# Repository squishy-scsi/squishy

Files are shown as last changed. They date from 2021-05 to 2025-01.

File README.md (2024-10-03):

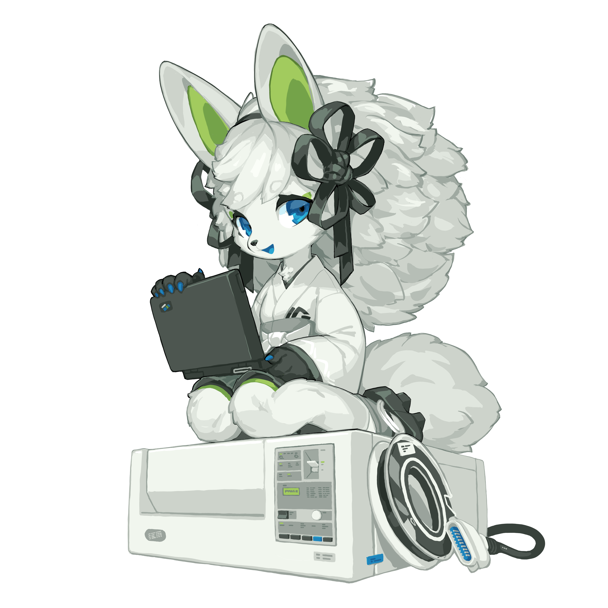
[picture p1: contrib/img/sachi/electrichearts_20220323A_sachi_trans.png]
[](https://docs.scsi.moe/mascot.html)
# Squishy: The SCSI Multitool

Squishy is a platform for working with old SCSI devices with modern systems in a flexible manner. It was originally developed as a one-off solution for the [taperipper](https://lethalbit.net/projects/taperipper/) project, which was to boot a modern system off of a IBM 9348-002 9-track magnetic tape drive.

It has since evolved into being a generic toolkit and hardware platform for all things SCSI.

Squishy is comprised of 4 core components; A gateware library built on [Torii](https://github.com/shrine-maiden-heavy-industries/torii-hdl); A python library with various utilities and structures for dealing with SCSI data; A applet system to allow for custom gateware/python code applets to run on the hardware; And finally, the hardware itself.

> [!IMPORTANT]
> If you're looking for the Squishy hardware, the design files have moved to [`squishy-scsi/hardware`](https://github.com/squishy-scsi/hardware).

## Documentation

The documentation for Squishy can be found at [https://docs.scsi.moe](https://docs.scsi.moe).

## Installation

The installation instructions for squishy on various platforms can be found on the [https://docs.scsi.moe/install.html](https://docs.scsi.moe/install.html) page.

## Hardware

The Squishy hardware design files have be migrated to [`squishy-scsi/hardware`](https://github.com/squishy-scsi/hardware).

Details about the squishy hardware can be found on the [https://docs.scsi.moe/hardware/index.html](https://docs.scsi.moe/hardware/index.html) page.

## Mascot - Sachi

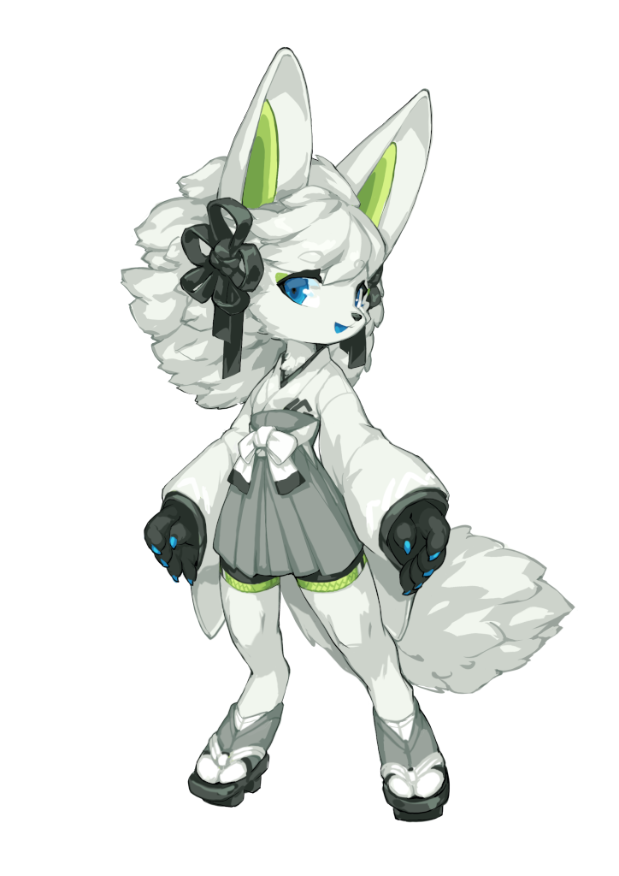
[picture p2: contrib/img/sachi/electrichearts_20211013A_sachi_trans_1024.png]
Sachi the spirit fox


More information about Sachi is available on her [mascot page](https://docs.scsi.moe/mascot.html) in the documentation.

Sachi was designed and illustrated by the amazing [Tyson Tan (tysontan.com)](https://tysontan.com). He provides mascot design service for free and open source software projects, free of charge, under free license.

## Community

Squishy has a dedicated IRC channel, [#squishy on libera.chat](https://web.libera.chat/#squishy). Join to ask questions, discuss ongoing development, or just hang out.

**NOTE:** Squishy does not have an official discord, nor any endorsed discord servers, for an explanation as to why, see the [F.A.Q.](https://docs.scsi.moe/faq.html)

## Licenses

The Squishy project is licensed under 3 individual licenses, one for the hardware and gateware, one for the software and one for the documentation.

The hardware is licensed under the [CERN-OHL-S](https://ohwr.org/cern_ohl_s_v2.txt), the license for which can be found in [`squishy-scsi/hardware/LICENSE`](https://github.com/squishy-scsi/hardware/tree/main/LICENSE)

The software and gateware are licensed under the [BSD-3-Clause](https://spdx.org/licenses/BSD-3-Clause.html) and can be found in [LICENSE.software](https://github.com/squishy-scsi/squishy/tree/main/LICENSE.software).

The documentation is licensed under the Creative Commons [CC-BY-SA](https://creativecommons.org/licenses/by-sa/4.0/) and can be found in [LICENSE.docs](https://github.com/squishy-scsi/squishy/tree/main/LICENSE.docs)

The icons used in the GUI are from the [KDE](https://kde.org) project. They are the [breeze-icons](https://github.com/KDE/breeze-icons/) and they are licensed under the [LGPL v2.1](https://spdx.org/licenses/LGPL-2.1-only.html), and can be found in [LICENSE.icons](https://github.com/squishy-scsi/squishy/tree/main/LICENSE.icons)

Sachi, the mascot is dual-licensed under the [BSD-3-Clause](https://spdx.org/licenses/BSD-3-Clause.html) and the Creative Commons [CC-BY-SA](https://creativecommons.org/licenses/by-sa/2.0/)

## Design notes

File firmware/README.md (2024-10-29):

# Squishy - Supervisor Firmware

> [!CAUTION]
> This documentation is ***really*** rough and incomplete, it will be
> eventually rolled into the [main documentation](https://docs.scsi.moe),
> but only once it's been stabilized.

This is the firmware that runs on the supervisor MCU on the squishy rev2 board, which is responsible for handling programming the FPGA and ensuring it can always boot into backup bootloader gateware.

## Building

To build the firmware you need a handful of things:

* meson >= 1.4.0
* ninja
* and a GCC `arm-none-eabi` cross compiler toolchain

To build the firmware, create a build directory (we'll call it `$BUILD`) and then invoke `meson` passing the toolchain file, like so:

```
$ meson setup --cross-file contrib/arm-none-eabi.meson $BUILD firmware
```

With that all done and happy, you can then build the firmware ELF with `ninja -C build`.

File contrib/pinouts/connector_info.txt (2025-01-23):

| PIN CNT | Body Type  | Signaling | Is Shielded | Name    | SCSI Standard        | Table ID | Table Reference | Figure Reference | Connector Reference                  |
|=========|============|===========|=============|=========|======================|==========|=================|==================|======================================|
| 50      | IDC        | SE        | No          | IDC50   | X3.131:1986 (SCSI-1) | MSE-50   | 4-1             | (FIG 4-1/4-2)    |                                      |
| 50      | IDC        | HVD       | No          | IDC50   | X3.131:1986 (SCSI-1) | HVD-50   | 4-2             | (FIG 4-1/4-2)    |                                      |
| 50      | Centronics | SE        | Yes         | CE50    | x3.131:1986 (SCSI-1) | MSE-50   | 4-1             |                  |                                      |
| 50      | Centronics | HVD       | Yes         | CE50    | x3.131:1986 (SCSI-1) | HVD-50   | 4-2             |                  |                                      |
|---------|------------|-----------|-------------|---------|----------------------|----------|-----------------|------------------|--------------------------------------|
| 50      | HD         | SE        | No          | HD50    | SCSI-2 R10L          | MSE-50   | 2:2             | (FIG 1/2 A)      | Non-shielded connector alternative 1 |
| 68      | HD         | SE        | No          | HD68    | SCSI-2 R10L          | SCSI2-68 | 3               | (FIG 1/2 B)      | Non-shielded connector               |
| 50      | HD         | HVD       | No          | HD50    | SCSI-2 R10L          | HVD-50   | 4:2             | (FIG 1/2 A)      | Non-shielded connector alternative 1 |
| 68      | HD         | HVD       | No          | HD68    | SCSI-2 R10L          | SCSI2-68 | 5               | (FIG 1/2 B)      | Non-shielded connector               |
| 50      | IDC        | SE        | No          | IDC50   | SCSI-2 R10L          | MSE-50   | 2:1             | (FIG 3/4 A)      | Non-shielded connector alternative 2 |
| 50      | IDC        | HVD       | No          | IDC50   | SCSI-2 R10L          | HVD-50   | 4:1             | (FIG 3/4 A)      | Non-shielded connector alternative 2 |
| 50      | HD         | SE        | Yes         | HD50    | SCSI-2 R10L          | MSE-50   | 2:2             | (FIG 6/5 A)      | Shielded connector alternative 1     |
| 68      | HD         | SE        | Yes         | HD68    | SCSI-2 R10L          | SCSI2-68 | 3               | (FIG 6/5 B)      | Shielded connector                   |
| 50      | HD         | HVD       | Yes         | HD50    | SCSI-2 R10L          | HVD-50   | 4:2             | (FIG 6/5 A)      | Shielded connector alternative 1     |
| 68      | HD         | HVD       | Yes         | HD68    | SCSI-2 R10L          | SCSI2-68 | 5               | (FIG 6/5 B)      | Shielded connector                   |
| 50      | Centronics | SE        | Yes         | CE50    | SCSI-2 R10L          | MSE-50   | 2:2             | (FIG 7/8 A)      | Shielded connector alternative 2     |
| 50      | Centronics | HVD       | Yes         | CE50    | SCSI-2 R10L          | HVD-50   | 4:2             | (FIG 7/8 A)      | Shielded connector alternative 2     |
|---------|------------|-----------|-------------|---------|----------------------|----------|-----------------|------------------|--------------------------------------|
| 68      | HD         | SE        | No          | HD68    | SPI-1 R15A (SCSI-3)  | MSE-68   | Table 1/2       | (FIG 4/5)        | Nonshielded connector                |
| 68      | HD         | SE        | Yes         | HD68    | SPI-1 R15A (SCSI-3)  | MSE-68   | Table 1/2       | (FIG 6/7)        | Shielded connector                   |
| 68      | HD         | HVD       | No          | HD68    | SPI-1 R15A (SCSI-3)  | HVD-68   | Table 3/4       | (FIG 4/5)        | Nonshielded connector                |
| 68      | HD         | HVD       | Yes         | HD68    | SPI-1 R15A (SCSI-3)  | HVD-68   | Table 3/4       | (FIG 6/7)        | Shielded connector                   |
|---------|------------|-----------|-------------|---------|----------------------|----------|-----------------|------------------|--------------------------------------|
| 50      | HD         | SE        | No          | HD50    | SPI-2 R20B (SCSI-3)  | MSE-50   | 3:2             | (FIG 8/9 A)      | Nonshielded connector alternative 1  |
| 50      | HD         | LVD       | No          | HD50    | SPI-2 R20B (SCSI-3)  | MSE-50   | 7:2             | (FIG 8/9 A)      | Nonshielded connector alternative 1  |
| 50      | HD         | HVD       | No          | HD50    | SPI-2 R20B (SCSI-3)  | HVD-50   | 10:2            | (FIG 8/9 A)      | Nonshielded connector alternative 1  |
| 50      | IDC        | SE        | No          | IDC50   | SPI-2 R20B (SCSI-3)  | MSE-50   | 3:1             | (FIG 10/11 A)    | Nonshielded connector alternative 2  |
| 50      | IDC        | LVD       | No          | IDC50   | SPI-2 R20B (SCSI-3)  | MSE-50   | 7:1             | (FIG 10/11 A)    | Nonshielded connector alternative 2  |
| 50      | IDC        | HVD       | No          | IDC50   | SPI-2 R20B (SCSI-3)  | HVD-50   | 10:1            | (FIG 10/11 A)    | Nonshielded connector alternative 2  |
| 68      | HD         | SE        | No          | HD68    | SPI-2 R20B (SCSI-3)  | MSE-68   | 4               | (FIG 8/9 P)      | Nonshielded connector alternative 3  |
| 68      | HD         | SE        | No          | HD68    | SPI-2 R20B (SCSI-3)  | MSE-68   | 5               | (FIG 8/9 Q)      | Nonshielded connector alternative 3  |
| 68      | HD         | LVD       | No          | HD68    | SPI-2 R20B (SCSI-3)  | MSE-68   | 8               | (FIG 8/9 P)      | Nonshielded connector alternative 3  |
| 68      | HD         | LVD       | No          | HD68    | SPI-2 R20B (SCSI-3)  | MSE-68   | 9               | (FIG 8/9 Q)      | Nonshielded connector alternative 3  |
| 68      | HD         | HVD       | No          | HD68    | SPI-2 R20B (SCSI-3)  | HVD-68   | 11              | (FIG 8/9 P)      | Nonshielded connector alternative 3  |
| 68      | HD         | HVD       | No          | HD68    | SPI-2 R20B (SCSI-3)  | HVD-68   | 12              | (FIG 8/9 Q)      | Nonshielded connector alternative 3  |
| 80      | SCA        | SE        | No          | SCA-2   | SPI-2 R20B (SCSI-3)  | SCA-80   | 6               | (FIG 12/13 P)    | Nonshielded connector alternative 4  |
| 80      | SCA        | LVD       | No          | SCA-2   | SPI-2 R20B (SCSI-3)  | SCA-80   | 13              | (FIG 12/13 P)    | Nonshielded connector alternative 4  |
| 80      | SCA        | HVD       | No          | SCA-2   | SPI-2 R20B (SCSI-3)  | SCA-80   | 13              | (FIG 12/13 P)    | Nonshielded connector alternative 4  |
| 50      | HD         | SE        | Yes         | HD50    | SPI-2 R20B (SCSI-3)  | MSE-50   | 3:2             | (FIG 14/15 A)    | Shielded connector alternative 1     |
| 50      | HD         | LVD       | Yes         | HD50    | SPI-2 R20B (SCSI-3)  | MSE-50   | 7:2             | (FIG 14/15 A)    | Shielded connector alternative 1     |
| 50      | HD         | HVD       | Yes         | HD50    | SPI-2 R20B (SCSI-3)  | HVD-50   | 10:2            | (FIG 14/15 A)    | Shielded connector alternative 1     |
| 50      | Centronics | SE        | Yes         | CE50    | SPI-2 R20B (SCSI-3)  | MSE-50   | 3:1             | (FIG 16/17 A)    | Shielded connector alternative 2     |
| 50      | Centronics | LVD       | Yes         | CE50    | SPI-2 R20B (SCSI-3)  | MSE-50   | 7:1             | (FIG 16/17 A)    | Shielded connector alternative 2     |
| 50      | Centronics | HVD       | Yes         | CE50    | SPI-2 R20B (SCSI-3)  | HVD-50   | 10:1            | (FIG 16/17 A)    | Shielded connector alternative 2     |
| 68      | HD         | SE        | Yes         | HD68    | SPI-2 R20B (SCSI-3)  | MSE-68   | 4               | (FIG 18/19 P)    | Shielded connector alternative 3     |
| 68      | HD         | SE        | Yes         | HD68    | SPI-2 R20B (SCSI-3)  | MSE-68   | 5               | (FIG 18/19 Q)    | Shielded connector alternative 3     |
| 68      | HD         | LVD       | Yes         | HD68    | SPI-2 R20B (SCSI-3)  | MSE-68   | 8               | (FIG 18/19 P)    | Shielded connector alternative 3     |
| 68      | HD         | LVD       | Yes         | HD68    | SPI-2 R20B (SCSI-3)  | MSE-68   | 9               | (FIG 18/19 Q)    | Shielded connector alternative 3     |
| 68      | HD         | HVD       | Yes         | HD68    | SPI-2 R20B (SCSI-3)  | HVD-68   | 11              | (FIG 18/19 P)    | Shielded connector alternative 3     |
| 68      | HD         | HVD       | Yes         | HD68    | SPI-2 R20B (SCSI-3)  | HVD-68   | 12              | (FIG 18/19 Q)    | Shielded connector alternative 3     |
| 68      | VHDCI      | SE        | Yes         | VHDCI68 | SPI-2 R20B (SCSI-3)  | MSE-68   | 4               | (FIG 20/21 P)    | Shielded connector alternative 4     |
| 68      | VHDCI      | SE        | Yes         | VHDCI68 | SPI-2 R20B (SCSI-3)  | MSE-68   | 5               | (FIG 20/21 Q)    | Shielded connector alternative 4     |
| 68      | VHDCI      | LVD       | Yes         | VHDCI68 | SPI-2 R20B (SCSI-3)  | MSE-68   | 8               | (FIG 20/21 P)    | Shielded connector alternative 4     |
| 68      | VHDCI      | LVD       | Yes         | VHDCI68 | SPI-2 R20B (SCSI-3)  | MSE-68   | 9               | (FIG 20/21 Q)    | Shielded connector alternative 4     |
| 68      | VHDCI      | HVD       | Yes         | VHDCI68 | SPI-2 R20B (SCSI-3)  | HVD-68   | 11              | (FIG 20/21 P)    | Shielded connector alternative 4     |
| 68      | VHDCI      | HVD       | Yes         | VHDCI68 | SPI-2 R20B (SCSI-3)  | HVD-68   | 12              | (FIG 20/21 Q)    | Shielded connector alternative 4     |
|---------|------------|-----------|-------------|---------|----------------------|----------|-----------------|------------------|--------------------------------------|
| 50      | HD         | SE        | No          | HD50    | SPI-3 R14 (SCSI-3)   | MSE-50   | 3:2             | (FIG 11/12 A)    | Nonshielded connector alternative 1  |
| 50      | HD         | LVD       | No          | HD50    | SPI-3 R14 (SCSI-3)   | MSE-50   | 6:2             | (FIG 11/12 A)    | Nonshielded connector alternative 1  |
| 50      | IDC        | SE        | No          | IDC50   | SPI-3 R14 (SCSI-3)   | MSE-50   | 3:1             | (FIG 12/14 A)    | Nonshielded connector alternative 2  |
| 50      | IDC        | LVD       | No          | IDC50   | SPI-3 R14 (SCSI-3)   | MSE-50   | 6:1             | (FIG 12/14 A)    | Nonshielded connector alternative 2  |
| 68      | HD         | SE        | No          | HD68    | SPI-3 R14 (SCSI-3)   | MSE-68   | 4               | (FIG 11/12 P)    | Nonshielded connector alternative 3  |
| 68      | HD         | LVD       | No          | HD68    | SPI-3 R14 (SCSI-3)   | MSE-68   | 7               | (FIG 11/12 P)    | Nonshielded connector alternative 3  |
| 80      | SCA        | SE        | No          | SCA-2   | SPI-3 R14 (SCSI-3)   | SCA-80   | 5               | (FIG 15/16 P)    | Nonshielded connector alternative 4  |
| 80      | SCA        | LVD       | No          | SCA-2   | SPI-3 R14 (SCSI-3)   | SCA-80   | 8               | (FIG 15/16 P)    | Nonshielded connector alternative 4  |
| 50      | HD         | SE        | Yes         | HD50    | SPI-3 R14 (SCSI-3)   | MSE-50   | 3:2             | (FIG 17/18 A)    | Shielded connector alternative 1     |
| 50      | HD         | LVD       | Yes         | HD50    | SPI-3 R14 (SCSI-3)   | MSE-50   | 6:2             | (FIG 17/18 A)    | Shielded connector alternative 1     |
| 50      | Centronics | SE        | Yes         | CE50    | SPI-3 R14 (SCSI-3)   | MSE-50   | 3:1             | (FIG 19/20 A)    | Shielded connector alternative 2     |
| 50      | Centronics | LVD       | Yes         | CE50    | SPI-3 R14 (SCSI-3)   | MSE-50   | 6:1             | (FIG 19/20 A)    | Shielded connector alternative 2     |
| 68      | HD         | SE        | Yes         | HD68    | SPI-3 R14 (SCSI-3)   | MSE-68   | 4               | (FIG 21/22 P)    | Shielded connector alternative 3     |
| 68      | HD         | LVD       | Yes         | HD68    | SPI-3 R14 (SCSI-3)   | MSE-68   | 4               | (FIG 21/22 P)    | Shielded connector alternative 3     |
| 68      | VHDCI      | SE        | Yes         | VHDCI68 | SPI-3 R14 (SCSI-3)   | MSE-68   | 7               | (FIG 23/24 P)    | Shielded connector alternative 4     |
| 68      | VHDCI      | LVD       | Yes         | VHDCI68 | SPI-3 R14 (SCSI-3)   | MSE-68   | 7               | (FIG 23/24 P)    | Shielded connector alternative 4     |
|---------|------------|-----------|-------------|---------|----------------------|----------|-----------------|------------------|--------------------------------------|
| 50      | HD         | SE        | No          | HD50    | SPI-4 R10 (SCSI-3)   | MSE-50   | 13:2            | (FIG 25/26 A)    | Nonshielded connector alternative 1  |
| 50      | HD         | LVD       | No          | HD50    | SPI-4 R10 (SCSI-3)   | MSE-50   | 16:2            | (FIG 25/26 A)    | Nonshielded connector alternative 1  |
| 50      | IDC        | SE        | No          | IDC50   | SPI-4 R10 (SCSI-3)   | MSE-50   | 13:1            | (FIG 27/28 A)    | Nonshielded connector alternative 2  |
| 50      | IDC        | LVD       | No          | IDC50   | SPI-4 R10 (SCSI-3)   | MSE-50   | 16:1            | (FIG 27/28 A)    | Nonshielded connector alternative 2  |
| 68      | HD         | SE        | No          | HD68    | SPI-4 R10 (SCSI-3)   | MSE-68   | 14              | (FIG 25/26 P)    | Nonshielded connector alternative 3  |
| 68      | HD         | LVD       | No          | HD68    | SPI-4 R10 (SCSI-3)   | MSE-68   | 17              | (FIG 25/26 P)    | Nonshielded connector alternative 3  |
| 80      | SCA        | SE        | No          | SCA-2   | SPI-4 R10 (SCSI-3)   | SCA-80   | 15              | (FIG 29/30 P)    | Nonshielded connector alternative 4  |
| 80      | SCA        | LVD       | No          | SCA-2   | SPI-4 R10 (SCSI-3)   | SCA-80   | 18              | (FIG 29/30 P)    | Nonshielded connector alternative 4  |
| 50      | HD         | SE        | Yes         | HD50    | SPI-4 R10 (SCSI-3)   | MSE-50   | 13:2            | (FIG 31/32 A)    | Shielded connector alternative 1     |
| 50      | HD         | LVD       | Yes         | HD50    | SPI-4 R10 (SCSI-3)   | MSE-50   | 16:2            | (FIG 31/32 A)    | Shielded connector alternative 1     |
| 50      | Centronics | SE        | Yes         | CE50    | SPI-4 R10 (SCSI-3)   | MSE-50   | 13:1            | (FIG 33/34 A)    | Shielded connector alternative 2     |
| 50      | Centronics | LVD       | Yes         | CE50    | SPI-4 R10 (SCSI-3)   | MSE-50   | 16:1            | (FIG 33/34 A)    | Shielded connector alternative 2     |
| 68      | HD         | SE        | Yes         | HD68    | SPI-4 R10 (SCSI-3)   | MSE-68   | 14              | (FIG 35/36 P)    | Shielded connector alternative 3     |
| 68      | HD         | LVD       | Yes         | HD68    | SPI-4 R10 (SCSI-3)   | MSE-68   | 17              | (FIG 35/36 P)    | Shielded connector alternative 3     |
| 68      | VHDCI      | SE        | Yes         | VHDCI68 | SPI-4 R10 (SCSI-3)   | MSE-68   | 14              | (FIG 37/38 P)    | Shielded connector alternative 4     |
| 68      | VHDCI      | LVD       | Yes         | VHDCI68 | SPI-4 R10 (SCSI-3)   | MSE-68   | 17              | (FIG 37/38 P)    | Shielded connector alternative 4     |
|---------|------------|-----------|-------------|---------|----------------------|----------|-----------------|------------------|--------------------------------------|
| 50      | HD         | LVD       | No          | HD50    | SPI-5 R06 (SCSI-3)   | MSE-50   | 13:2            | (FIG 25/26 A)    | Nonshielded connector alternative 1  |
| 50      | IDC        | LVD       | No          | IDC50   | SPI-5 R06 (SCSI-3)   | MSE-50   | 13:1            | (FIG 27/28 A)    | Nonshielded connector alternative 2  |
| 68      | HD         | LVD       | No          | HD68    | SPI-5 R06 (SCSI-3)   | MSE-68   | 14              | (FIG 25/26 P)    | Nonshielded connector alternative 3  |
| 80      | SCA        | LVD       | No          | SCA-2   | SPI-5 R06 (SCSI-3)   | SCA-80   | 15              | (FIG 29/30 P)    | Nonshielded connector alternative 4  |
| 50      | HD         | LVD       | Yes         | HD50    | SPI-5 R06 (SCSI-3)   | MSE-50   | 13:2            | (FIG 31/32 A)    | Shielded connector alternative 1     |
| 50      | Centronics | LVD       | Yes         | CE50    | SPI-5 R06 (SCSI-3)   | MSE-50   | 13:1            | (FIG 33/34 A)    | Shielded connector alternative 2     |
| 68      | HD         | LVD       | Yes         | HD68    | SPI-5 R06 (SCSI-3)   | MSE-68   | 14              | (FIG 35/36 P)    | Shielded connector alternative 3     |
| 68      | VHDCI      | LVD       | Yes         | VHDCI68 | SPI-5 R06 (SCSI-3)   | MSE-68   | 14              | (FIG 37/38 P)    | Shielded connector alternative 4     |
|=========|============|===========|=============|=========|======================|==========|=================|==================|======================================|

X3.131:1986

	|         Table 4-1 (SCSI-1)            | - |         Table 4-2 (SCSI-1)            |
	|                  SE                   | - |                  HVD                  |
	| Pin # | Signal    | Signal    | Pin # | - | Pin # | Signal    | Signal    | Pin # |
	|-------|-----------|-----------|-------| - |-------|-----------|-----------|-------|
	| 1     | GND       | -DB0      | 2     | - | 1     | GND       | GND       | 2     |
	| 3     | GND       | -DB1      | 4     | - | 3     | +DB0      | -DB0      | 4     |
	| 5     | GND       | -DB2      | 6     | - | 5     | +DB1      | -DB1      | 6     |
	| 7     | GND       | -DB3      | 8     | - | 7     | +DB2      | -DB2      | 8     |
	| 9     | GND       | -DB4      | 10    | - | 9     | +DB3      | -DB3      | 10    |
	| 11    | GND       | -DB5      | 12    | - | 11    | +DB4      | -DB4      | 12    |
	| 13    | GND       | -DB6      | 14    | - | 13    | +DB5      | -DB5      | 14    |
	| 15    | GND       | -DB7      | 16    | - | 15    | +DB6      | -DB6      | 16    |
	| 17    | GND       | -DBP      | 18    | - | 17    | +DB7      | -DB7      | 18    |
	| 19    | GND       | GND       | 20    | - | 19    | +DBP      | -DBP      | 20    |
	| 21    | GND       | GND       | 22    | - | 21    | DIFFSENS  | GND       | 22    |
	| 23    | GND       | GND       | 24    | - | 23    | GND       | GND       | 24    |
	| 25    | NC        | TERMPWR   | 26    | - | 25    | TERMPWR   | TERMPWR   | 26    |
	| 27    | GND       | GND       | 28    | - | 27    | GND       | GND       | 28    |
	| 29    | GND       | GND       | 30    | - | 29    | +ATN      | -ATN      | 30    |
	| 31    | GND       | -ATN      | 32    | - | 31    | GND       | GND       | 32    |
	| 33    | GND       | GND       | 34    | - | 33    | +BSY      | -BSY      | 34    |
	| 35    | GND       | -BSY      | 36    | - | 35    | +ACK      | -ACK      | 36    |
	| 37    | GND       | -ACK      | 38    | - | 37    | +RST      | -RST      | 38    |
	| 39    | GND       | -RST      | 40    | - | 39    | +MSG      | -MSG      | 40    |
	| 41    | GND       | -MSG      | 42    | - | 41    | +SEL      | -SEL      | 42    |
	| 43    | GND       | -SEL      | 44    | - | 43    | +C/D      | -C/D      | 44    |
	| 45    | GND       | -C/D      | 46    | - | 45    | +REQ      | -REQ      | 46    |
	| 47    | GND       | -REQ      | 48    | - | 47    | +I/O      | -I/O      | 48    |
	| 49    | GND       | -I/O      | 50    | - | 49    | GND       | GND       | 50    |

SCSI-2 R10L

	|          Table 2:1 (SCSI-2)           | - |          Table 2:2 (SCSI-2)           |
	|                  SE                   | - |                  SE                   |
	| Pin # | Signal    | Signal    | Pin # | - | Pin # | Signal    | Signal    | Pin # |
	|-------|-----------|-----------|-------| - |-------|-----------|-----------|-------|
	| 1     | GND       | -DB0      | 2     | - | 1     | GND       | -DB0      | 26    |
	| 3     | GND       | -DB1      | 4     | - | 2     | GND       | -DB1      | 27    |
	| 5     | GND       | -DB2      | 6     | - | 3     | GND       | -DB2      | 28    |
	| 7     | GND       | -DB3      | 8     | - | 4     | GND       | -DB3      | 29    |
	| 9     | GND       | -DB4      | 10    | - | 5     | GND       | -DB4      | 30    |
	| 11    | GND       | -DB5      | 12    | - | 6     | GND       | -DB5      | 31    |
	| 13    | GND       | -DB6      | 14    | - | 7     | GND       | -DB6      | 32    |
	| 15    | GND       | -DB7      | 16    | - | 8     | GND       | -DB7      | 33    |
	| 17    | GND       | -DBP      | 18    | - | 9     | GND       | -DBP      | 34    |
	| 19    | GND       | GND       | 20    | - | 10    | GND       | GND       | 35    |
	| 21    | GND       | GND       | 22    | - | 11    | GND       | GND       | 36    |
	| 23    | RESERVED  | RESERVED  | 24    | - | 12    | RESERVED  | RESERVED  | 37    |
	| 25    | NC        | TERMPWR   | 26    | - | 13    | NC        | TERMPWR   | 38    |
	| 27    | RESERVED  | RESERVED  | 28    | - | 14    | RESERVED  | RESERVED  | 39    |
	| 29    | GND       | GND       | 30    | - | 15    | GND       | GND       | 40    |
	| 31    | GND       | -ATN      | 32    | - | 16    | GND       | -ATN      | 41    |
	| 33    | GND       | GND       | 34    | - | 17    | GND       | GND       | 42    |
	| 35    | GND       | -BSY      | 36    | - | 18    | GND       | -BSY      | 43    |
	| 37    | GND       | -ACK      | 38    | - | 19    | GND       | -ACK      | 44    |
	| 39    | GND       | -RST      | 40    | - | 20    | GND       | -RST      | 45    |
	| 41    | GND       | -MSG      | 42    | - | 21    | GND       | -MSG      | 56    |
	| 43    | GND       | -SEL      | 44    | - | 22    | GND       | -SEL      | 47    |
	| 45    | GND       | -C/D      | 46    | - | 23    | GND       | -C/D      | 48    |
	| 47    | GND       | -REQ      | 48    | - | 24    | GND       | -REQ      | 49    |
	| 49    | GND       | -I/O      | 50    | - | 25    | GND       | -I/O      | 50    |

	|            Table 3 (SCSI-2)           |
	|                  SE                   |
	| Pin # | Signal    | Signal    | Pin # |
	|-------|-----------|-----------|-------|
	| 1     | GND       | GND       | 35    |
	| 2     | GND       | -DB8      | 36    |
	| 3     | GND       | -DB9      | 37    |
	| 4     | GND       | -DB10     | 38    |
	| 5     | GND       | -DB11     | 39    |
	| 6     | GND       | -DB12     | 40    |
	| 7     | GND       | -DB13     | 41    |
	| 8     | GND       | -DB14     | 42    |
	| 9     | GND       | -DB15     | 43    |
	| 10    | GND       | -DBP1     | 44    |
	| 11    | GND       | -ACKB     | 45    |
	| 12    | GND       | GND       | 46    |
	| 13    | GND       | -REQB     | 47    |
	| 14    | GND       | -DB16     | 48    |
	| 15    | GND       | -DB17     | 49    |
	| 16    | GND       | -DB18     | 50    |
	| 17    | TERMPWRB  | TERMPWRB  | 51    |
	| 18    | TERMPWRB  | TERMPWRB  | 52    |
	| 19    | GND       | -DB19     | 53    |
	| 20    | GND       | -DB20     | 54    |
	| 21    | GND       | -DB21     | 55    |
	| 22    | GND       | -DB22     | 56    |
	| 23    | GND       | -DB23     | 57    |
	| 24    | GND       | -DBP2     | 58    |
	| 25    | GND       | -DB24     | 59    |
	| 26    | GND       | -DB25     | 60    |
	| 27    | GND       | -DB26     | 61    |
	| 28    | GND       | -DB27     | 62    |
	| 29    | GND       | -DB28     | 63    |
	| 30    | GND       | -DB29     | 64    |
	| 31    | GND       | -DB30     | 65    |
	| 32    | GND       | -DB31     | 66    |
	| 33    | GND       | -DBP3     | 67    |
	| 34    | GND       | GND       | 68    |

	|          Table 4:1 (SCSI-2)           | - |          Table 4:2 (SCSI-2)           |
	|                  HVD                  | - |                  HVD                  |
	| Pin # | Signal    | Signal    | Pin # | - | Pin # | Signal    | Signal    | Pin # |
	|-------|-----------|-----------|-------| - |-------|-----------|-----------|-------|
	| 1     | GND       | GND       | 2     | - | 1     | GND       | GND       | 26    |
	| 3     | +DB0      | -DB0      | 4     | - | 2     | +DB0      | -DB0      | 27    |
	| 5     | +DB1      | -DB1      | 6     | - | 3     | +DB1      | -DB1      | 28    |
	| 7     | +DB2      | -DB2      | 8     | - | 4     | +DB2      | -DB2      | 29    |
	| 9     | +DB3      | -DB3      | 10    | - | 5     | +DB3      | -DB3      | 30    |
	| 11    | +DB4      | -DB4      | 12    | - | 6     | +DB4      | -DB4      | 31    |
	| 13    | +DB5      | -DB5      | 14    | - | 7     | +DB5      | -DB5      | 32    |
	| 15    | +DB6      | -DB6      | 16    | - | 8     | +DB6      | -DB6      | 33    |
	| 17    | +DB7      | -DB7      | 18    | - | 9     | +DB7      | -DB7      | 34    |
	| 19    | +DBP      | -DBP      | 20    | - | 10    | +DBP      | -DBP      | 35    |
	| 21    | DIFFSENS  | GND       | 22    | - | 11    | DIFFSENS  | GND       | 36    |
	| 23    | RESERVED  | RESERVED  | 24    | - | 12    | RESERVED  | RESERVED  | 37    |
	| 25    | TERMPWR   | TERMPWR   | 26    | - | 13    | TERMPWR   | TERMPWR   | 38    |
	| 27    | RESERVED  | RESERVED  | 28    | - | 14    | RESERVED  | RESERVED  | 39    |
	| 29    | +ATN      | -ATN      | 30    | - | 15    | +ATN      | -ATN      | 40    |
	| 31    | GND       | GND       | 32    | - | 16    | GND       | GND       | 41    |
	| 33    | +BSY      | -BSY      | 34    | - | 17    | +BSY      | -BSY      | 42    |
	| 35    | +ACK      | -ACK      | 36    | - | 18    | +ACK      | -ACK      | 43    |
	| 37    | +RST      | -RST      | 38    | - | 19    | +RST      | -RST      | 44    |
	| 39    | +MSG      | -MSG      | 40    | - | 20    | +MSG      | -MSG      | 45    |
	| 41    | +SEL      | -SEL      | 42    | - | 21    | +SEL      | -SEL      | 56    |
	| 43    | +C/D      | -C/D      | 44    | - | 22    | +C/D      | -C/D      | 47    |
	| 45    | +REQ      | -REQ      | 46    | - | 23    | +REQ      | -REQ      | 48    |
	| 47    | +I/O      | -I/O      | 48    | - | 24    | +I/O      | -I/O      | 49    |
	| 49    | GND       | GND       | 50    | - | 25    | GND       | GND       | 50    |

	|            Table 5 (SCSI-2)           |
	|                  HVD                  |
	| Pin # | Signal    | Signal    | Pin # |
	|-------|-----------|-----------|-------|
	| 1     | GND       | GND       | 35    |
	| 2     | +DB8      | -DB8      | 36    |
	| 3     | +DB9      | -DB9      | 37    |
	| 4     | +DB10     | -DB10     | 38    |
	| 5     | +DB11     | -DB11     | 39    |
	| 6     | +DB12     | -DB12     | 40    |
	| 7     | +DB13     | -DB13     | 41    |
	| 8     | +DB14     | -DB14     | 42    |
	| 9     | +DB15     | -DB15     | 43    |
	| 10    | +DBP1     | -DBP1     | 44    |
	| 11    | +ACKB     | -ACKB     | 45    |
	| 12    | GND       | DIFFSENS  | 46    |
	| 13    | +REQB     | -REQB     | 47    |
	| 14    | +DB16     | -DB16     | 48    |
	| 15    | +DB17     | -DB17     | 49    |
	| 16    | +DB18     | -DB18     | 50    |
	| 17    | TERMPWRB  | TERMPWRB  | 51    |
	| 18    | TERMPWRB  | TERMPWRB  | 52    |
	| 19    | +DB19     | -DB19     | 53    |
	| 20    | +DB20     | -DB20     | 54    |
	| 21    | +DB21     | -DB21     | 55    |
	| 22    | +DB22     | -DB22     | 56    |
	| 23    | +DB23     | -DB23     | 57    |
	| 24    | +DBP2     | -DBP2     | 58    |
	| 25    | +DB24     | -DB24     | 59    |
	| 26    | +DB25     | -DB25     | 60    |
	| 27    | +DB26     | -DB26     | 61    |
	| 28    | +DB27     | -DB27     | 62    |
	| 29    | +DB28     | -DB28     | 63    |
	| 30    | +DB29     | -DB29     | 64    |
	| 31    | +DB30     | -DB30     | 65    |
	| 32    | +DB31     | -DB31     | 66    |
	| 33    | +DBP3     | -DBP3     | 67    |
	| 34    | GND       | GND       | 68    |

SPI-1 R15A (SCSI-3)

    |              Primary Bus              | - |             Secondary Bus             |
	|            Table 1 (SPI-1)            | - |            Table 2 (SPI-1)            |
	|                  SE                   | - |                  SE                   |
	| Pin # | Signal    | Signal    | Pin # | - | Pin # | Signal    | Signal    | Pin # |
	|-------|-----------|-----------|-------| - |-------|-----------|-----------|-------|
	| 1     | GND       | -DB12     | 35    | - | 1     | GND       | -DB28     | 35    |
	| 2     | GND       | -DB13     | 36    | - | 2     | GND       | -DB29     | 36    |
	| 3     | GND       | -DB14     | 37    | - | 3     | GND       | -DB30     | 37    |
	| 4     | GND       | -DB15     | 38    | - | 4     | GND       | -DB31     | 38    |
	| 5     | GND       | -DBP1     | 39    | - | 5     | GND       | -DBP3     | 39    |
	| 6     | GND       | -DB0      | 40    | - | 6     | GND       | -DB16     | 40    |
	| 7     | GND       | -DB1      | 41    | - | 7     | GND       | -DB17     | 41    |
	| 8     | GND       | -DB2      | 42    | - | 8     | GND       | -DB18     | 42    |
	| 9     | GND       | -DB3      | 43    | - | 9     | GND       | -DB19     | 43    |
	| 10    | GND       | -DB4      | 44    | - | 10    | GND       | -DB20     | 44    |
	| 11    | GND       | -DB5      | 45    | - | 11    | GND       | -DB21     | 45    |
	| 12    | GND       | -DB6      | 46    | - | 12    | GND       | -DB22     | 46    |
	| 13    | GND       | -DB7      | 47    | - | 13    | GND       | -DB23     | 47    |
	| 14    | GND       | -DBP      | 48    | - | 14    | GND       | -DBP2     | 48    |
	| 15    | GND       | GND       | 49    | - | 15    | GND       | GND       | 49    |
	| 16    | GND       | GND       | 50    | - | 16    | GND       | GND       | 50    |
	| 17    | TERMPWR   | TERMPWR   | 51    | - | 17    | TERMPWRQ  | TERMPWRQ  | 51    |
	| 18    | TERMPWR   | TERMPWR   | 52    | - | 18    | TERMPWRQ  | TERMPWRQ  | 52    |
	| 19    | RESERVED  | RESERVED  | 53    | - | 19    | RESERVED  | RESERVED  | 53    |
	| 20    | GND       | GND       | 54    | - | 20    | GND       | GND       | 54    |
	| 21    | GND       | -ATN      | 55    | - | 21    | GND       | TERMINATED| 55    |
	| 22    | GND       | GND       | 56    | - | 22    | GND       | GND       | 56    |
	| 23    | GND       | -BSY      | 57    | - | 23    | GND       | TERMINATED| 57    |
	| 24    | GND       | -ACK      | 58    | - | 24    | GND       | -ACKQ     | 58    |
	| 25    | GND       | -RST      | 59    | - | 25    | GND       | TERMINATED| 59    |
	| 26    | GND       | -MSG      | 60    | - | 26    | GND       | TERMINATED| 60    |
	| 27    | GND       | -SEL      | 61    | - | 27    | GND       | TERMINATED| 61    |
	| 28    | GND       | -C/D      | 62    | - | 28    | GND       | TERMINATED| 62    |
	| 29    | GND       | -REQ      | 63    | - | 29    | GND       | -REQQ     | 63    |
	| 30    | GND       | -I/O      | 64    | - | 30    | GND       | TERMINATED| 64    |
	| 31    | GND       | -DB8      | 65    | - | 31    | GND       | -DB24     | 65    |
	| 32    | GND       | -DB9      | 66    | - | 32    | GND       | -DB25     | 66    |
	| 33    | GND       | -DB10     | 67    | - | 33    | GND       | -DB26     | 67    |
	| 34    | GND       | -DB11     | 68    | - | 34    | GND       | -DB27     | 68    |

    |              Primary Bus              | - |             Secondary Bus             |
	|            Table 3 (SPI-1)            | - |            Table 4 (SPI-1)            |
	|                  HVD                  | - |                  HVD                  |
	| Pin # | Signal    | Signal    | Pin # | - | Pin # | Signal    | Signal    | Pin # |
	|-------|-----------|-----------|-------| - |-------|-----------|-----------|-------|
	| 1     | +DB12     | -DB12     | 35    | - | 1     | +DB28     | -DB28     | 35    |
	| 2     | +DB13     | -DB13     | 36    | - | 2     | +DB29     | -DB29     | 36    |
	| 3     | +DB14     | -DB14     | 37    | - | 3     | +DB30     | -DB30     | 37    |
	| 4     | +DB15     | -DB15     | 38    | - | 4     | +DB31     | -DB31     | 38    |
	| 5     | +DBP1     | -DBP1     | 39    | - | 5     | +DBP3     | -DBP3     | 39    |
	| 6     | GND       | GND       | 40    | - | 6     | GND       | GND       | 40    |
	| 7     | +DB0      | -DB0      | 41    | - | 7     | +DB16     | -DB16     | 41    |
	| 8     | +DB1      | -DB1      | 42    | - | 8     | +DB17     | -DB17     | 42    |
	| 9     | +DB2      | -DB2      | 43    | - | 9     | +DB18     | -DB18     | 43    |
	| 10    | +DB3      | -DB3      | 44    | - | 10    | +DB19     | -DB19     | 44    |
	| 11    | +DB4      | -DB4      | 45    | - | 11    | +DB20     | -DB20     | 45    |
	| 12    | +DB5      | -DB5      | 46    | - | 12    | +DB21     | -DB21     | 46    |
	| 13    | +DB6      | -DB6      | 47    | - | 13    | +DB22     | -DB22     | 47    |
	| 14    | +DB7      | -DB7      | 48    | - | 14    | +DB23     | -DB23     | 48    |
	| 15    | +DBP      | -DBP      | 49    | - | 15    | +DBP2     | -DBP2     | 49    |
	| 16    | DIFFSENS  | GND       | 50    | - | 16    | DIFFSENS  | GND       | 50    |
	| 17    | TERMPWR   | TERMPWR   | 51    | - | 17    | TERMPWRQ  | TERMPWRQ  | 51    |
	| 18    | TERMPWR   | TERMPWR   | 52    | - | 18    | TERMPWRQ  | TERMPWRQ  | 52    |
	| 19    | RESERVED  | RESERVED  | 53    | - | 19    | RESERVED  | RESERVED  | 53    |
	| 20    | +ATN      | -ATN      | 54    | - | 20    | TERMINATED| TERMINATED| 54    |
	| 21    | GND       | GND       | 55    | - | 21    | GND       | GND       | 55    |
	| 22    | +BSY      | -BSY      | 56    | - | 22    | TERMINATED| TERMINATED| 56    |
	| 23    | +ACK      | -ACK      | 57    | - | 23    | +ACKQ     | -ACKQ     | 57    |
	| 24    | +RST      | -RST      | 58    | - | 24    | TERMINATED| TERMINATED| 58    |
	| 25    | +MSG      | -MSG      | 59    | - | 25    | TERMINATED| TERMINATED| 59    |
	| 26    | +SEL      | -SEL      | 60    | - | 26    | TERMINATED| TERMINATED| 60    |
	| 27    | +C/D      | -C/D      | 61    | - | 27    | TERMINATED| TERMINATED| 61    |
	| 28    | +REQ      | -REQ      | 62    | - | 28    | +REQQ     | -REQQ     | 62    |
	| 29    | +I/O      | -I/O      | 63    | - | 29    | TERMINATED| TERMINATED| 63    |
	| 30    | GND       | GND       | 64    | - | 30    | GND       | GND       | 64    |
	| 31    | +DB8      | -DB8      | 65    | - | 31    | +DB24     | -DB24     | 65    |
	| 32    | +DB9      | -DB9      | 66    | - | 32    | +DB25     | -DB25     | 66    |
	| 33    | +DB10     | -DB10     | 67    | - | 33    | +DB26     | -DB26     | 67    |
	| 34    | +DB11     | -DB11     | 68    | - | 34    | +DB27     | -DB27     | 68    |

SPI-2 R20B (SCSI-3)

	|          Table 3:1 (SPI-2)            | - |          Table 3:2 (SPI-2)            |
	|                  SE                   | - |                  SE                   |
	| Pin # | Signal    | Signal    | Pin # | - | Pin # | Signal    | Signal    | Pin # |
	|-------|-----------|-----------|-------| - |-------|-----------|-----------|-------|
	| 1     | SIG RET   | -DB0      | 2     | - | 1     | SIG RET   | -DB0      | 26    |
	| 3     | SIG RET   | -DB1      | 4     | - | 2     | SIG RET   | -DB1      | 27    |
	| 5     | SIG RET   | -DB2      | 6     | - | 3     | SIG RET   | -DB2      | 28    |
	| 7     | SIG RET   | -DB3      | 8     | - | 4     | SIG RET   | -DB3      | 29    |
	| 9     | SIG RET   | -DB4      | 10    | - | 5     | SIG RET   | -DB4      | 30    |
	| 11    | SIG RET   | -DB5      | 12    | - | 6     | SIG RET   | -DB5      | 31    |
	| 13    | SIG RET   | -DB6      | 14    | - | 7     | SIG RET   | -DB6      | 32    |
	| 15    | SIG RET   | -DB7      | 16    | - | 8     | SIG RET   | -DB7      | 33    |
	| 17    | SIG RET   | -DBP      | 18    | - | 9     | SIG RET   | -DBP      | 34    |
	| 19    | GND       | GND       | 20    | - | 10    | GND       | GND       | 35    |
	| 21    | GND       | GND       | 22    | - | 11    | GND       | GND       | 36    |
	| 23    | RESERVED  | RESERVED  | 24    | - | 12    | RESERVED  | RESERVED  | 37    |
	| 25    | NC        | TERMPWR   | 26    | - | 13    | NC        | TERMPWR   | 38    |
	| 27    | RESERVED  | RESERVED  | 28    | - | 14    | RESERVED  | RESERVED  | 39    |
	| 29    | GND       | GND       | 30    | - | 15    | GND       | GND       | 40    |
	| 31    | SIG RET   | -ATN      | 32    | - | 16    | SIG RET   | -ATN      | 41    |
	| 33    | GND       | GND       | 34    | - | 17    | GND       | GND       | 42    |
	| 35    | SIG RET   | -BSY      | 36    | - | 18    | SIG RET   | -BSY      | 43    |
	| 37    | SIG RET   | -ACK      | 38    | - | 19    | SIG RET   | -ACK      | 44    |
	| 39    | SIG RET   | -RST      | 40    | - | 20    | SIG RET   | -RST      | 45    |
	| 41    | SIG RET   | -MSG      | 42    | - | 21    | SIG RET   | -MSG      | 56    |
	| 43    | SIG RET   | -SEL      | 44    | - | 22    | SIG RET   | -SEL      | 47    |
	| 45    | SIG RET   | -C/D      | 46    | - | 23    | SIG RET   | -C/D      | 48    |
	| 47    | SIG RET   | -REQ      | 48    | - | 24    | SIG RET   | -REQ      | 49    |
	| 49    | SIG RET   | -I/O      | 50    | - | 25    | SIG RET   | -I/O      | 50    |

	|             Table 4 (SPI-2)           | - |            Table 5 (SPI-2)            |
	|                  SE                   | - |                  SE                   |
	| Pin # | Signal    | Signal    | Pin # | - | Pin # | Signal    | Signal    | Pin # |
	|-------|-----------|-----------|-------| - |-------|-----------|-----------|-------|
	| 1     | SIG RET   | -DB12     | 35    | - | 1     | SIG RET   | -DB28     | 35    |
	| 2     | SIG RET   | -DB13     | 36    | - | 2     | SIG RET   | -DB29     | 36    |
	| 3     | SIG RET   | -DB14     | 37    | - | 3     | SIG RET   | -DB30     | 37    |
	| 4     | SIG RET   | -DB15     | 38    | - | 4     | SIG RET   | -DB31     | 38    |
	| 5     | SIG RET   | -DBP1     | 39    | - | 5     | SIG RET   | -DBP3     | 39    |
	| 6     | SIG RET   | -DB0      | 40    | - | 6     | SIG RET   | -DB16     | 40    |
	| 7     | SIG RET   | -DB1      | 41    | - | 7     | SIG RET   | -DB17     | 41    |
	| 8     | SIG RET   | -DB2      | 42    | - | 8     | SIG RET   | -DB18     | 42    |
	| 9     | SIG RET   | -DB3      | 43    | - | 9     | SIG RET   | -DB19     | 43    |
	| 10    | SIG RET   | -DB4      | 44    | - | 10    | SIG RET   | -DB20     | 44    |
	| 11    | SIG RET   | -DB5      | 45    | - | 11    | SIG RET   | -DB21     | 45    |
	| 12    | SIG RET   | -DB6      | 46    | - | 12    | SIG RET   | -DB22     | 46    |
	| 13    | SIG RET   | -DB7      | 47    | - | 13    | SIG RET   | -DB23     | 47    |
	| 14    | SIG RET   | -DBP      | 48    | - | 14    | SIG RET   | -DBP2     | 48    |
	| 15    | GND       | GND       | 49    | - | 15    | GND       | GND       | 49    |
	| 16    | GND       | GND       | 50    | - | 16    | GND       | GND       | 50    |
	| 17    | TERMPWR   | TERMPWR   | 51    | - | 17    | TERMPWRQ  | TERMPWRQ  | 51    |
	| 18    | TERMPWR   | TERMPWR   | 52    | - | 18    | TERMPWRQ  | TERMPWRQ  | 52    |
	| 19    | RESERVED  | RESERVED  | 53    | - | 19    | RESERVED  | RESERVED  | 53    |
	| 20    | GND       | GND       | 54    | - | 20    | GND       | GND       | 54    |
	| 21    | SIG RET   | -ATN      | 55    | - | 21    | GND       | TERMINATED| 55    |
	| 22    | GND       | GND       | 56    | - | 22    | GND       | GND       | 56    |
	| 23    | SIG RET   | -BSY      | 57    | - | 23    | GND       | TERMINATED| 57    |
	| 24    | SIG RET   | -ACK      | 58    | - | 24    | SIG RET   | -ACKQ     | 58    |
	| 25    | SIG RET   | -RST      | 59    | - | 25    | GND       | TERMINATED| 59    |
	| 26    | SIG RET   | -MSG      | 60    | - | 26    | GND       | TERMINATED| 60    |
	| 27    | SIG RET   | -SEL      | 61    | - | 27    | GND       | TERMINATED| 61    |
	| 28    | SIG RET   | -C/D      | 62    | - | 28    | GND       | TERMINATED| 62    |
	| 29    | SIG RET   | -REQ      | 63    | - | 29    | SIG RET   | -REQQ     | 63    |
	| 30    | SIG RET   | -I/O      | 64    | - | 30    | GND       | TERMINATED| 64    |
	| 31    | SIG RET   | -DB8      | 65    | - | 31    | SIG RET   | -DB24     | 65    |
	| 32    | SIG RET   | -DB9      | 66    | - | 32    | SIG RET   | -DB25     | 66    |
	| 33    | SIG RET   | -DB10     | 67    | - | 33    | SIG RET   | -DB26     | 67    |
	| 34    | SIG RET   | -DB11     | 68    | - | 34    | SIG RET   | -DB27     | 68    |

	|            Table 6 (SPI-2)            |
	|                  SE                   |
	| Pin # | Signal    | Signal    | Pin # |
	|-------|-----------|-----------|-------|
	| 1     | 12V CHRG  | 12V GND   | 41    |
	| 2     | 12V       | 12V GND   | 42    |
	| 3     | 12V       | 12V GND   | 43    |
	| 4     | 12V       | MATED 1   | 44    |
	| 5     | 3.3V      | 3.3V CHRG | 45    |
	| 6     | 3.3V      | GND       | 46    |
	| 7     | -DB11     | SIG RET   | 47    |
	| 8     | -DB10     | SIG RET   | 48    |
	| 9     | -DB9      | SIG RET   | 49    |
	| 10    | -DB8      | SIG RET   | 50    |
	| 11    | -I/O      | SIG RET   | 51    |
	| 12    | -REQ      | SIG RET   | 52    |
	| 13    | -C/D      | SIG RET   | 53    |
	| 14    | -SEL      | SIG RET   | 54    |
	| 15    | -MSG      | SIG RET   | 55    |
	| 16    | -RST      | SIG RET   | 56    |
	| 17    | -ACK      | SIG RET   | 57    |
	| 18    | -BSY      | SIG RET   | 58    |
	| 19    | -ATN      | SIG RET   | 59    |
	| 20    | -DBP      | SIG RET   | 60    |
	| 21    | -DB7      | SIG RET   | 61    |
	| 22    | -DB6      | SIG RET   | 62    |
	| 23    | -DB5      | SIG RET   | 63    |
	| 24    | -DB4      | SIG RET   | 64    |
	| 25    | -DB3      | SIG RET   | 65    |
	| 26    | -DB2      | SIG RET   | 66    |
	| 27    | -DB1      | SIG RET   | 67    |
	| 28    | -DB0      | SIG RET   | 68    |
	| 29    | -DBP1     | SIG RET   | 69    |
	| 30    | -DB15     | SIG RET   | 70    |
	| 31    | -DB14     | SIG RET   | 71    |
	| 32    | -DB13     | SIG RET   | 72    |
	| 33    | -DB12     | SIG RET   | 73    |
	| 34    | 5V        | MATED 2   | 74    |
	| 35    | 5V        | 5V GND    | 75    |
	| 36    | 5V CHRG   | 5V GND    | 76    |
	| 37    | SPINDLE   | LED OUT   | 77    |
	| 38    | RMT_START | DLYD_STRT | 78    |
	| 39    | SCSI ID 0 | SCSI ID 1 | 79    |
	| 40    | SCSI ID 2 | SCSI ID 3 | 80    |

	|          Table 7:1 (SPI-2)            | - |          Table 7:2 (SPI-2)            |
	|                  LVD                  | - |                  LVD                  |
	| Pin # | Signal    | Signal    | Pin # | - | Pin # | Signal    | Signal    | Pin # |
	|-------|-----------|-----------|-------| - |-------|-----------|-----------|-------|
	| 1     | +DB0      | -DB0      | 2     | - | 1     | +DB0      | -DB0      | 26    |
	| 3     | +DB1      | -DB1      | 4     | - | 2     | +DB1      | -DB1      | 27    |
	| 5     | +DB2      | -DB2      | 6     | - | 3     | +DB2      | -DB2      | 28    |
	| 7     | +DB3      | -DB3      | 8     | - | 4     | +DB3      | -DB3      | 29    |
	| 9     | +DB4      | -DB4      | 10    | - | 5     | +DB4      | -DB4      | 30    |
	| 11    | +DB5      | -DB5      | 12    | - | 6     | +DB5      | -DB5      | 31    |
	| 13    | +DB6      | -DB6      | 14    | - | 7     | +DB6      | -DB6      | 32    |
	| 15    | +DB7      | -DB7      | 16    | - | 8     | +DB7      | -DB7      | 33    |
	| 17    | +DBP      | -DBP      | 18    | - | 9     | +DBP      | -DBP      | 34    |
	| 19    | GND       | GND       | 20    | - | 10    | GND       | GND       | 35    |
	| 21    | DIFFSENS  | GND       | 22    | - | 11    | DIFFSENS  | GND       | 36    |
	| 23    | RESERVED  | RESERVED  | 24    | - | 12    | RESERVED  | RESERVED  | 37    |
	| 25    | TERMPWR   | TERMPWR   | 26    | - | 13    | TERMPWR   | TERMPWR   | 38    |
	| 27    | RESERVED  | RESERVED  | 28    | - | 14    | RESERVED  | RESERVED  | 39    |
	| 29    | GND       | GND       | 30    | - | 15    | GND       | GND       | 40    |
	| 31    | +ATN      | -ATN      | 32    | - | 16    | +ATN      | -ATN      | 41    |
	| 33    | GND       | GND       | 34    | - | 17    | GND       | GND       | 42    |
	| 35    | +BSY      | -BSY      | 36    | - | 18    | +BSY      | -BSY      | 43    |
	| 37    | +ACK      | -ACK      | 38    | - | 19    | +ACK      | -ACK      | 44    |
	| 39    | +RST      | -RST      | 40    | - | 20    | +RST      | -RST      | 45    |
	| 41    | +MSG      | -MSG      | 42    | - | 21    | +MSG      | -MSG      | 56    |
	| 43    | +SEL      | -SEL      | 44    | - | 22    | +SEL      | -SEL      | 47    |
	| 45    | +C/D      | -C/D      | 46    | - | 23    | +C/D      | -C/D      | 48    |
	| 47    | +REQ      | -REQ      | 48    | - | 24    | +REQ      | -REQ      | 49    |
	| 49    | +I/O      | -I/O      | 50    | - | 25    | +I/O      | -I/O      | 50    |

	|            Table 8 (SPI-2)            | - |            Table 9 (SPI-2)            |
	|                  LVD                  | - |                  LVD                  |
	| Pin # | Signal    | Signal    | Pin # | - | Pin # | Signal    | Signal    | Pin # |
	|-------|-----------|-----------|-------| - |-------|-----------|-----------|-------|
	| 1     | +DB12     | -DB12     | 35    | - | 1     | +DB28     | -DB28     | 35    |
	| 2     | +DB13     | -DB13     | 36    | - | 2     | +DB29     | -DB29     | 36    |
	| 3     | +DB14     | -DB14     | 37    | - | 3     | +DB30     | -DB30     | 37    |
	| 4     | +DB15     | -DB15     | 38    | - | 4     | +DB31     | -DB31     | 38    |
	| 5     | +DBP1     | -DBP1     | 39    | - | 5     | +DBP3     | -DBP3     | 39    |
	| 6     | +DB0      | -DB0      | 40    | - | 6     | +DB16     | -DB16     | 40    |
	| 7     | +DB1      | -DB1      | 41    | - | 7     | +DB17     | -DB17     | 41    |
	| 8     | +DB2      | -DB2      | 42    | - | 8     | +DB18     | -DB18     | 42    |
	| 9     | +DB3      | -DB3      | 43    | - | 9     | +DB19     | -DB19     | 43    |
	| 10    | +DB4      | -DB4      | 44    | - | 10    | +DB20     | -DB20     | 44    |
	| 11    | +DB5      | -DB5      | 45    | - | 11    | +DB21     | -DB21     | 45    |
	| 12    | +DB6      | -DB6      | 46    | - | 12    | +DB22     | -DB22     | 46    |
	| 13    | +DB7      | -DB7      | 47    | - | 13    | +DB23     | -DB23     | 47    |
	| 14    | +DBP      | -DBP      | 48    | - | 14    | +DBP2     | -DBP2     | 48    |
	| 15    | GND       | GND       | 49    | - | 15    | GND       | GND       | 49    |
	| 16    | DIFFSENS  | GND       | 50    | - | 16    | DIFFSENS  | GND       | 50    |
	| 17    | TERMPWR   | TERMPWR   | 51    | - | 17    | TERMPWRQ  | TERMPWRQ  | 51    |
	| 18    | TERMPWR   | TERMPWR   | 52    | - | 18    | TERMPWRQ  | TERMPWRQ  | 52    |
	| 19    | RESERVED  | RESERVED  | 53    | - | 19    | RESERVED  | RESERVED  | 53    |
	| 20    | GND       | GND       | 54    | - | 20    | GND       | GND       | 54    |
	| 21    | +ATN      | -ATN      | 55    | - | 21    | TERMINATED| TERMINATED| 55    |
	| 22    | GND       | GND       | 56    | - | 22    | GND       | GND       | 56    |
	| 23    | +BSY      | -BSY      | 57    | - | 23    | TERMINATED| TERMINATED| 57    |
	| 24    | +ACK      | -ACK      | 58    | - | 24    | +ACKQ     | -ACKQ     | 58    |
	| 25    | +RST      | -RST      | 59    | - | 25    | TERMINATED| TERMINATED| 59    |
	| 26    | +MSG      | -MSG      | 60    | - | 26    | TERMINATED| TERMINATED| 60    |
	| 27    | +SEL      | -SEL      | 61    | - | 27    | TERMINATED| TERMINATED| 61    |
	| 28    | +C/D      | -C/D      | 62    | - | 28    | TERMINATED| TERMINATED| 62    |
	| 29    | +REQ      | -REQ      | 63    | - | 29    | +REQQ     | -REQQ     | 63    |
	| 30    | +I/O      | -I/O      | 64    | - | 30    | TERMINATED| TERMINATED| 64    |
	| 31    | +DB8      | -DB8      | 65    | - | 31    | +DB24     | -DB24     | 65    |
	| 32    | +DB9      | -DB9      | 66    | - | 32    | +DB25     | -DB25     | 66    |
	| 33    | +DB10     | -DB10     | 67    | - | 33    | +DB26     | -DB26     | 67    |
	| 34    | +DB11     | -DB11     | 68    | - | 34    | +DB27     | -DB27     | 68    |

	|         Table 10:1 (SPI-2)            | - |         Table 10:2 (SPI-2)            |
	|                  HVD                  | - |                  HVD                  |
	| Pin # | Signal    | Signal    | Pin # | - | Pin # | Signal    | Signal    | Pin # |
	|-------|-----------|-----------|-------| - |-------|-----------|-----------|-------|
	| 1     | GND       | GND       | 2     | - | 1     | GND       | GND       | 26    |
	| 3     | +DB0      | -DB0      | 4     | - | 2     | +DB0      | -DB0      | 27    |
	| 5     | +DB1      | -DB1      | 6     | - | 3     | +DB1      | -DB1      | 28    |
	| 7     | +DB2      | -DB2      | 8     | - | 4     | +DB2      | -DB2      | 29    |
	| 9     | +DB3      | -DB3      | 10    | - | 5     | +DB3      | -DB3      | 30    |
	| 11    | +DB4      | -DB4      | 12    | - | 6     | +DB4      | -DB4      | 31    |
	| 13    | +DB5      | -DB5      | 14    | - | 7     | +DB5      | -DB5      | 32    |
	| 15    | +DB6      | -DB6      | 16    | - | 8     | +DB6      | -DB6      | 33    |
	| 17    | +DB7      | -DB7      | 18    | - | 9     | +DB7      | -DB7      | 34    |
	| 19    | +DBP      | -DBP      | 20    | - | 10    | +DBP      | -DBP      | 35    |
	| 21    | DIFFSENS  | GND       | 22    | - | 11    | DIFFSENS  | GND       | 36    |
	| 23    | RESERVED  | RESERVED  | 24    | - | 12    | RESERVED  | RESERVED  | 37    |
	| 25    | TERMPWR   | TERMPWR   | 26    | - | 13    | TERMPWR   | TERMPWR   | 38    |
	| 27    | RESERVED  | RESERVED  | 28    | - | 14    | RESERVED  | RESERVED  | 39    |
	| 29    | +ATN      | -ATN      | 30    | - | 15    | +ATN      | -ATN      | 40    |
	| 31    | GND       | GND       | 32    | - | 16    | GND       | GND       | 41    |
	| 33    | +BSY      | -BSY      | 34    | - | 17    | +BSY      | -BSY      | 42    |
	| 35    | +ACK      | -ACK      | 36    | - | 18    | +ACK      | -ACK      | 43    |
	| 37    | +RST      | -RST      | 38    | - | 19    | +RST      | -RST      | 44    |
	| 39    | +MSG      | -MSG      | 40    | - | 20    | +MSG      | -MSG      | 45    |
	| 41    | +SEL      | -SEL      | 42    | - | 21    | +SEL      | -SEL      | 56    |
	| 43    | +C/D      | -C/D      | 44    | - | 22    | +C/D      | -C/D      | 47    |
	| 45    | +REQ      | -REQ      | 46    | - | 23    | +REQ      | -REQ      | 48    |
	| 47    | +I/O      | -I/O      | 48    | - | 24    | +I/O      | -I/O      | 49    |
	| 49    | GND       | GND       | 50    | - | 25    | GND       | GND       | 50    |

	|           Table 11 (SPI-2)            | - |           Table 12 (SPI-2)            |
	|                  HVD                  | - |                  HVD                  |
	| Pin # | Signal    | Signal    | Pin # | - | Pin # | Signal    | Signal    | Pin # |
	|-------|-----------|-----------|-------| - |-------|-----------|-----------|-------|
	| 1     | +DB12     | -DB12     | 35    | - | 1     | +DB28     | -DB28     | 35    |
	| 2     | +DB13     | -DB13     | 36    | - | 2     | +DB29     | -DB29     | 36    |
	| 3     | +DB14     | -DB14     | 37    | - | 3     | +DB30     | -DB30     | 37    |
	| 4     | +DB15     | -DB15     | 38    | - | 4     | +DB31     | -DB31     | 38    |
	| 5     | +DBP1     | -DBP1     | 39    | - | 5     | +DBP3     | -DBP3     | 39    |
	| 6     | GND       | GND       | 40    | - | 6     | GND       | GND       | 40    |
	| 7     | +DB0      | -DB0      | 41    | - | 7     | +DB16     | -DB16     | 41    |
	| 8     | +DB1      | -DB1      | 42    | - | 8     | +DB17     | -DB17     | 42    |
	| 9     | +DB2      | -DB2      | 43    | - | 9     | +DB18     | -DB18     | 43    |
	| 10    | +DB3      | -DB3      | 44    | - | 10    | +DB19     | -DB19     | 44    |
	| 11    | +DB4      | -DB4      | 45    | - | 11    | +DB20     | -DB20     | 45    |
	| 12    | +DB5      | -DB5      | 46    | - | 12    | +DB21     | -DB21     | 46    |
	| 13    | +DB6      | -DB6      | 47    | - | 13    | +DB22     | -DB22     | 47    |
	| 14    | +DB7      | -DB7      | 48    | - | 14    | +DB23     | -DB23     | 48    |
	| 15    | +DBP      | -DBP      | 49    | - | 15    | +DBP2     | -DBP2     | 49    |
	| 16    | DIFFSENS  | GND       | 50    | - | 16    | DIFFSENS  | GND       | 50    |
	| 17    | TERMPWR   | TERMPWR   | 51    | - | 17    | TERMPWRQ  | TERMPWRQ  | 51    |
	| 18    | TERMPWR   | TERMPWR   | 52    | - | 18    | TERMPWRQ  | TERMPWRQ  | 52    |
	| 19    | RESERVED  | RESERVED  | 53    | - | 19    | RESERVED  | RESERVED  | 53    |
	| 20    | +ATN      | -ATN      | 54    | - | 20    | TERMINATED| TERMINATED| 54    |
	| 21    | GND       | GND       | 55    | - | 21    | GND       | GND       | 55    |
	| 22    | +BSY      | -BSY      | 56    | - | 22    | TERMINATED| TERMINATED| 56    |
	| 23    | +ACK      | -ACK      | 57    | - | 23    | +ACKQ     | -ACKQ     | 57    |
	| 24    | +RST      | -RST      | 58    | - | 24    | TERMINATED| TERMINATED| 58    |
	| 25    | +MSG      | -MSG      | 59    | - | 25    | TERMINATED| TERMINATED| 59    |
	| 26    | +SEL      | -SEL      | 60    | - | 26    | TERMINATED| TERMINATED| 60    |
	| 27    | +C/D      | -C/D      | 61    | - | 27    | TERMINATED| TERMINATED| 61    |
	| 28    | +REQ      | -REQ      | 62    | - | 28    | +REQQ     | -REQQ     | 62    |
	| 29    | +I/O      | -I/O      | 63    | - | 29    | TERMINATED| TERMINATED| 63    |
	| 30    | GND       | GND       | 64    | - | 30    | GND       | GND       | 64    |
	| 31    | +DB8      | -DB8      | 65    | - | 31    | +DB24     | -DB24     | 65    |
	| 32    | +DB9      | -DB9      | 66    | - | 32    | +DB25     | -DB25     | 66    |
	| 33    | +DB10     | -DB10     | 67    | - | 33    | +DB26     | -DB26     | 67    |
	| 34    | +DB11     | -DB11     | 68    | - | 34    | +DB27     | -DB27     | 68    |

	|           Table 13 (SPI-2)            |
	|                HVD/LVD                |
	| Pin # | Signal    | Signal    | Pin # |
	|-------|-----------|-----------|-------|
	| 1     | 12V CHRG  | 12V GND   | 41    |
	| 2     | 12V       | 12V GND   | 42    |
	| 3     | 12V       | 12V GND   | 43    |
	| 4     | 12V       | MATED 1   | 44    |
	| 5     | 3.3V      | 3.3V CHRG | 45    |
	| 6     | 3.3V      | DIFFSENS  | 46    |
	| 7     | -DB11     | +DB11     | 47    |
	| 8     | -DB10     | +DB10     | 48    |
	| 9     | -DB9      | +DB9      | 49    |
	| 10    | -DB8      | +DB8      | 50    |
	| 11    | -I/O      | +I/O      | 51    |
	| 12    | -REQ      | +REQ      | 52    |
	| 13    | -C/D      | +C/D      | 53    |
	| 14    | -SEL      | +SEL      | 54    |
	| 15    | -MSG      | +MSG      | 55    |
	| 16    | -RST      | +RST      | 56    |
	| 17    | -ACK      | +ACK      | 57    |
	| 18    | -BSY      | +BSY      | 58    |
	| 19    | -ATN      | +ATN      | 59    |
	| 20    | -DBP      | +DBP      | 60    |
	| 21    | -DB7      | +DB7      | 61    |
	| 22    | -DB6      | +DB6      | 62    |
	| 23    | -DB5      | +DB5      | 63    |
	| 24    | -DB4      | +DB4      | 64    |
	| 25    | -DB3      | +DB3      | 65    |
	| 26    | -DB2      | +DB2      | 66    |
	| 27    | -DB1      | +DB1      | 67    |
	| 28    | -DB0      | +DB0      | 68    |
	| 29    | -DBP1     | +DBP1     | 69    |
	| 30    | -DB15     | +DB15     | 70    |
	| 31    | -DB14     | +DB14     | 71    |
	| 32    | -DB13     | +DB13     | 72    |
	| 33    | -DB12     | +DB12     | 73    |
	| 34    | 5V        | MATED 2   | 74    |
	| 35    | 5V        | 5V GND    | 75    |
	| 36    | 5V CHRG   | 5V GND    | 76    |
	| 37    | SPINDLE   | LED OUT   | 77    |
	| 38    | RMT_START | DLYD_STRT | 78    |
	| 39    | SCSI ID 0 | SCSI ID 1 | 79    |
	| 40    | SCSI ID 2 | SCSI ID 3 | 80    |

SPI-3 R14 (SCSI-3)

	|          Table 3:1 (SPI-3)            | - |          Table 3:2 (SPI-3)            |
	|                  SE                   | - |                  SE                   |
	| Pin # | Signal    | Signal    | Pin # | - | Pin # | Signal    | Signal    | Pin # |
	|-------|-----------|-----------|-------| - |-------|-----------|-----------|-------|
	| 1     | SIG RET   | -DB0      | 2     | - | 1     | SIG RET   | -DB0      | 26    |
	| 3     | SIG RET   | -DB1      | 4     | - | 2     | SIG RET   | -DB1      | 27    |
	| 5     | SIG RET   | -DB2      | 6     | - | 3     | SIG RET   | -DB2      | 28    |
	| 7     | SIG RET   | -DB3      | 8     | - | 4     | SIG RET   | -DB3      | 29    |
	| 9     | SIG RET   | -DB4      | 10    | - | 5     | SIG RET   | -DB4      | 30    |
	| 11    | SIG RET   | -DB5      | 12    | - | 6     | SIG RET   | -DB5      | 31    |
	| 13    | SIG RET   | -DB6      | 14    | - | 7     | SIG RET   | -DB6      | 32    |
	| 15    | SIG RET   | -DB7      | 16    | - | 8     | SIG RET   | -DB7      | 33    |
	| 17    | SIG RET   | -DBP      | 18    | - | 9     | SIG RET   | -DBP      | 34    |
	| 19    | GND       | GND       | 20    | - | 10    | GND       | GND       | 35    |
	| 21    | GND       | GND       | 22    | - | 11    | GND       | GND       | 36    |
	| 23    | RESERVED  | RESERVED  | 24    | - | 12    | RESERVED  | RESERVED  | 37    |
	| 25    | NC        | TERMPWR   | 26    | - | 13    | NC        | TERMPWR   | 38    |
	| 27    | RESERVED  | RESERVED  | 28    | - | 14    | RESERVED  | RESERVED  | 39    |
	| 29    | GND       | GND       | 30    | - | 15    | GND       | GND       | 40    |
	| 31    | SIG RET   | -ATN      | 32    | - | 16    | SIG RET   | -ATN      | 41    |
	| 33    | GND       | GND       | 34    | - | 17    | GND       | GND       | 42    |
	| 35    | SIG RET   | -BSY      | 36    | - | 18    | SIG RET   | -BSY      | 43    |
	| 37    | SIG RET   | -ACK      | 38    | - | 19    | SIG RET   | -ACK      | 44    |
	| 39    | SIG RET   | -RST      | 40    | - | 20    | SIG RET   | -RST      | 45    |
	| 41    | SIG RET   | -MSG      | 42    | - | 21    | SIG RET   | -MSG      | 56    |
	| 43    | SIG RET   | -SEL      | 44    | - | 22    | SIG RET   | -SEL      | 47    |
	| 45    | SIG RET   | -C/D      | 46    | - | 23    | SIG RET   | -C/D      | 48    |
	| 47    | SIG RET   | -REQ      | 48    | - | 24    | SIG RET   | -REQ      | 49    |
	| 49    | SIG RET   | -I/O      | 50    | - | 25    | SIG RET   | -I/O      | 50    |

	|            Table 4 (SPI-3)            |
	|                  SE                   |
	| Pin # | Signal    | Signal    | Pin # |
	|-------|-----------|-----------|-------|
	| 1     | SIG RET   | -DB12     | 35    |
	| 2     | SIG RET   | -DB13     | 36    |
	| 3     | SIG RET   | -DB14     | 37    |
	| 4     | SIG RET   | -DB15     | 38    |
	| 5     | SIG RET   | -DBP1     | 39    |
	| 6     | SIG RET   | -DB0      | 40    |
	| 7     | SIG RET   | -DB1      | 41    |
	| 8     | SIG RET   | -DB2      | 42    |
	| 9     | SIG RET   | -DB3      | 43    |
	| 10    | SIG RET   | -DB4      | 44    |
	| 11    | SIG RET   | -DB5      | 45    |
	| 12    | SIG RET   | -DB6      | 46    |
	| 13    | SIG RET   | -DB7      | 47    |
	| 14    | SIG RET   | -DBP      | 48    |
	| 15    | GND       | GND       | 49    |
	| 16    | GND       | GND       | 50    |
	| 17    | TERMPWR   | TERMPWR   | 51    |
	| 18    | TERMPWR   | TERMPWR   | 52    |
	| 19    | RESERVED  | RESERVED  | 53    |
	| 20    | GND       | GND       | 54    |
	| 21    | SIG RET   | -ATN      | 55    |
	| 22    | GND       | GND       | 56    |
	| 23    | SIG RET   | -BSY      | 57    |
	| 24    | SIG RET   | -ACK      | 58    |
	| 25    | SIG RET   | -RST      | 59    |
	| 26    | SIG RET   | -MSG      | 60    |
	| 27    | SIG RET   | -SEL      | 61    |
	| 28    | SIG RET   | -C/D      | 62    |
	| 29    | SIG RET   | -REQ      | 63    |
	| 30    | SIG RET   | -I/O      | 64    |
	| 31    | SIG RET   | -DB8      | 65    |
	| 32    | SIG RET   | -DB9      | 66    |
	| 33    | SIG RET   | -DB10     | 67    |
	| 34    | SIG RET   | -DB11     | 68    |

	|            Table 5 (SPI-3)            |
	|                  SE                   |
	| Pin # | Signal    | Signal    | Pin # |
	|-------|-----------|-----------|-------|
	| 1     | 12V CHRG  | 12V GND   | 41    |
	| 2     | 12V       | 12V GND   | 42    |
	| 3     | 12V       | 12V GND   | 43    |
	| 4     | 12V       | MATED 1   | 44    |
	| 5     | 3.3V      | 3.3V CHRG | 45    |
	| 6     | 3.3V      | GND       | 46    |
	| 7     | -DB11     | SIG RET   | 47    |
	| 8     | -DB10     | SIG RET   | 48    |
	| 9     | -DB9      | SIG RET   | 49    |
	| 10    | -DB8      | SIG RET   | 50    |
	| 11    | -I/O      | SIG RET   | 51    |
	| 12    | -REQ      | SIG RET   | 52    |
	| 13    | -C/D      | SIG RET   | 53    |
	| 14    | -SEL      | SIG RET   | 54    |
	| 15    | -MSG      | SIG RET   | 55    |
	| 16    | -RST      | SIG RET   | 56    |
	| 17    | -ACK      | SIG RET   | 57    |
	| 18    | -BSY      | SIG RET   | 58    |
	| 19    | -ATN      | SIG RET   | 59    |
	| 20    | -DBP      | SIG RET   | 60    |
	| 21    | -DB7      | SIG RET   | 61    |
	| 22    | -DB6      | SIG RET   | 62    |
	| 23    | -DB5      | SIG RET   | 63    |
	| 24    | -DB4      | SIG RET   | 64    |
	| 25    | -DB3      | SIG RET   | 65    |
	| 26    | -DB2      | SIG RET   | 66    |
	| 27    | -DB1      | SIG RET   | 67    |
	| 28    | -DB0      | SIG RET   | 68    |
	| 29    | -DBP1     | SIG RET   | 69    |
	| 30    | -DB15     | SIG RET   | 70    |
	| 31    | -DB14     | SIG RET   | 71    |
	| 32    | -DB13     | SIG RET   | 72    |
	| 33    | -DB12     | SIG RET   | 73    |
	| 34    | 5V        | MATED 2   | 74    |
	| 35    | 5V        | 5V GND    | 75    |
	| 36    | 5V CHRG   | 5V GND    | 76    |
	| 37    | SPINDLE   | LED OUT   | 77    |
	| 38    | RMT_START | DLYD_STRT | 78    |
	| 39    | SCSI ID 0 | SCSI ID 1 | 79    |
	| 40    | SCSI ID 2 | SCSI ID 3 | 80    |

	|           Table 6:1 (SPI-3)           | - |           Table 6:2 (SPI-3)           |
	|                LVD/MSE                | - |                LVD/MSE                |
	| Pin # | Signal    | Signal    | Pin # | - | Pin # | Signal    | Signal    | Pin # |
	|-------|-----------|-----------|-------| - |-------|-----------|-----------|-------|
	| 1     | +DB0      | -DB0      | 2     | - | 1     | +DB0      | -DB0      | 26    |
	| 3     | +DB1      | -DB1      | 4     | - | 2     | +DB1      | -DB1      | 27    |
	| 5     | +DB2      | -DB2      | 6     | - | 3     | +DB2      | -DB2      | 28    |
	| 7     | +DB3      | -DB3      | 8     | - | 4     | +DB3      | -DB3      | 29    |
	| 9     | +DB4      | -DB4      | 10    | - | 5     | +DB4      | -DB4      | 30    |
	| 11    | +DB5      | -DB5      | 12    | - | 6     | +DB5      | -DB5      | 31    |
	| 13    | +DB6      | -DB6      | 14    | - | 7     | +DB6      | -DB6      | 32    |
	| 15    | +DB7      | -DB7      | 16    | - | 8     | +DB7      | -DB7      | 33    |
	| 17    | +DBP      | -DBP      | 18    | - | 9     | +DBP      | -DBP      | 34    |
	| 19    | GND       | GND       | 20    | - | 10    | GND       | GND       | 35    |
	| 21    | DIFFSENS  | GND       | 22    | - | 11    | DIFFSENS  | GND       | 36    |
	| 23    | RESERVED  | RESERVED  | 24    | - | 12    | RESERVED  | RESERVED  | 37    |
	| 25    | TERMPWR   | TERMPWR   | 26    | - | 13    | TERMPWR   | TERMPWR   | 38    |
	| 27    | RESERVED  | RESERVED  | 28    | - | 14    | RESERVED  | RESERVED  | 39    |
	| 29    | GND       | GND       | 30    | - | 15    | GND       | GND       | 40    |
	| 31    | +ATN      | -ATN      | 32    | - | 16    | +ATN      | -ATN      | 41    |
	| 33    | GND       | GND       | 34    | - | 17    | GND       | GND       | 42    |
	| 35    | +BSY      | -BSY      | 36    | - | 18    | +BSY      | -BSY      | 43    |
	| 37    | +ACK      | -ACK      | 38    | - | 19    | +ACK      | -ACK      | 44    |
	| 39    | +RST      | -RST      | 40    | - | 20    | +RST      | -RST      | 45    |
	| 41    | +MSG      | -MSG      | 42    | - | 21    | +MSG      | -MSG      | 56    |
	| 43    | +SEL      | -SEL      | 44    | - | 22    | +SEL      | -SEL      | 47    |
	| 45    | +C/D      | -C/D      | 46    | - | 23    | +C/D      | -C/D      | 48    |
	| 47    | +REQ      | -REQ      | 48    | - | 24    | +REQ      | -REQ      | 49    |
	| 49    | +I/O      | -I/O      | 50    | - | 25    | +I/O      | -I/O      | 50    |

	|             Table 7 (SPI-3)           |
	|                LVD/MSE                |
	| Pin # | Signal    | Signal    | Pin # |
	|-------|-----------|-----------|-------|
	| 1     | +DB12     | -DB12     | 35    |
	| 2     | +DB13     | -DB13     | 36    |
	| 3     | +DB14     | -DB14     | 37    |
	| 4     | +DB15     | -DB15     | 38    |
	| 5     | +DBP1     | -DBP1     | 39    |
	| 6     | +DB0      | -DB0      | 40    |
	| 7     | +DB1      | -DB1      | 41    |
	| 8     | +DB2      | -DB2      | 42    |
	| 9     | +DB3      | -DB3      | 43    |
	| 10    | +DB4      | -DB4      | 44    |
	| 11    | +DB5      | -DB5      | 45    |
	| 12    | +DB6      | -DB6      | 46    |
	| 13    | +DB7      | -DB7      | 47    |
	| 14    | +DBP      | -DBP      | 48    |
	| 15    | GND       | GND       | 49    |
	| 16    | DIFFSENS  | GND       | 50    |
	| 17    | TERMPWR   | TERMPWR   | 51    |
	| 18    | TERMPWR   | TERMPWR   | 52    |
	| 19    | RESERVED  | RESERVED  | 53    |
	| 20    | GND       | GND       | 54    |
	| 21    | +ATN      | -ATN      | 55    |
	| 22    | GND       | GND       | 56    |
	| 23    | +BSY      | -BSY      | 57    |
	| 24    | +ACK      | -ACK      | 58    |
	| 25    | +RST      | -RST      | 59    |
	| 26    | +MSG      | -MSG      | 60    |
	| 27    | +SEL      | -SEL      | 61    |
	| 28    | +C/D      | -C/D      | 62    |
	| 29    | +REQ      | -REQ      | 63    |
	| 30    | +I/O      | -I/O      | 64    |
	| 31    | +DB8      | -DB8      | 65    |
	| 32    | +DB9      | -DB9      | 66    |
	| 33    | +DB10     | -DB10     | 67    |
	| 34    | +DB11     | -DB11     | 68    |

	|             Table 8 (SPI-3)           |
	|                LVD/MSE                |
	| Pin # | Signal    | Signal    | Pin # |
	|-------|-----------|-----------|-------|
	| 1     | 12V CHRG  | 12V GND   | 41    |
	| 2     | 12V       | 12V GND   | 42    |
	| 3     | 12V       | 12V GND   | 43    |
	| 4     | 12V       | MATED 1   | 44    |
	| 5     | 3.3V      | 3.3V CHRG | 45    |
	| 6     | 3.3V      | DIFFSENS  | 46    |
	| 7     | -DB11     | +DB11     | 47    |
	| 8     | -DB10     | +DB10     | 48    |
	| 9     | -DB9      | +DB9      | 49    |
	| 10    | -DB8      | +DB8      | 50    |
	| 11    | -I/O      | +I/O      | 51    |
	| 12    | -REQ      | +REQ      | 52    |
	| 13    | -C/D      | +C/D      | 53    |
	| 14    | -SEL      | +SEL      | 54    |
	| 15    | -MSG      | +MSG      | 55    |
	| 16    | -RST      | +RST      | 56    |
	| 17    | -ACK      | +ACK      | 57    |
	| 18    | -BSY      | +BSY      | 58    |
	| 19    | -ATN      | +ATN      | 59    |
	| 20    | -DBP      | +DBP      | 60    |
	| 21    | -DB7      | +DB7      | 61    |
	| 22    | -DB6      | +DB6      | 62    |
	| 23    | -DB5      | +DB5      | 63    |
	| 24    | -DB4      | +DB4      | 64    |
	| 25    | -DB3      | +DB3      | 65    |
	| 26    | -DB2      | +DB2      | 66    |
	| 27    | -DB1      | +DB1      | 67    |
	| 28    | -DB0      | +DB0      | 68    |
	| 29    | -DBP1     | +DBP1     | 69    |
	| 30    | -DB15     | +DB15     | 70    |
	| 31    | -DB14     | +DB14     | 71    |
	| 32    | -DB13     | +DB13     | 72    |
	| 33    | -DB12     | +DB12     | 73    |
	| 34    | 5V        | MATED 2   | 74    |
	| 35    | 5V        | 5V GND    | 75    |
	| 36    | 5V CHRG   | 5V GND    | 76    |
	| 37    | SPINDLE   | LED OUT   | 77    |
	| 38    | RMT_START | DLYD_STRT | 78    |
	| 39    | SCSI ID 0 | SCSI ID 1 | 79    |
	| 40    | SCSI ID 2 | SCSI ID 3 | 80    |

SPI-4 R10 (SCSI-3)

	|         Table 13:1 (SPI-4)            | - |         Table 13:2 (SPI-4)            |
	|                  SE                   | - |                  SE                   |
	| Pin # | Signal    | Signal    | Pin # | - | Pin # | Signal    | Signal    | Pin # |
	|-------|-----------|-----------|-------| - |-------|-----------|-----------|-------|
	| 1     | SIG RET   | -DB0      | 2     | - | 1     | SIG RET   | -DB0      | 26    |
	| 3     | SIG RET   | -DB1      | 4     | - | 2     | SIG RET   | -DB1      | 27    |
	| 5     | SIG RET   | -DB2      | 6     | - | 3     | SIG RET   | -DB2      | 28    |
	| 7     | SIG RET   | -DB3      | 8     | - | 4     | SIG RET   | -DB3      | 29    |
	| 9     | SIG RET   | -DB4      | 10    | - | 5     | SIG RET   | -DB4      | 30    |
	| 11    | SIG RET   | -DB5      | 12    | - | 6     | SIG RET   | -DB5      | 31    |
	| 13    | SIG RET   | -DB6      | 14    | - | 7     | SIG RET   | -DB6      | 32    |
	| 15    | SIG RET   | -DB7      | 16    | - | 8     | SIG RET   | -DB7      | 33    |
	| 17    | SIG RET   | -DBP      | 18    | - | 9     | SIG RET   | -DBP      | 34    |
	| 19    | GND       | GND       | 20    | - | 10    | GND       | GND       | 35    |
	| 21    | GND       | GND       | 22    | - | 11    | GND       | GND       | 36    |
	| 23    | RESERVED  | RESERVED  | 24    | - | 12    | RESERVED  | RESERVED  | 37    |
	| 25    | NC        | TERMPWR   | 26    | - | 13    | NC        | TERMPWR   | 38    |
	| 27    | RESERVED  | RESERVED  | 28    | - | 14    | RESERVED  | RESERVED  | 39    |
	| 29    | GND       | GND       | 30    | - | 15    | GND       | GND       | 40    |
	| 31    | SIG RET   | -ATN      | 32    | - | 16    | SIG RET   | -ATN      | 41    |
	| 33    | GND       | GND       | 34    | - | 17    | GND       | GND       | 42    |
	| 35    | SIG RET   | -BSY      | 36    | - | 18    | SIG RET   | -BSY      | 43    |
	| 37    | SIG RET   | -ACK      | 38    | - | 19    | SIG RET   | -ACK      | 44    |
	| 39    | SIG RET   | -RST      | 40    | - | 20    | SIG RET   | -RST      | 45    |
	| 41    | SIG RET   | -MSG      | 42    | - | 21    | SIG RET   | -MSG      | 56    |
	| 43    | SIG RET   | -SEL      | 44    | - | 22    | SIG RET   | -SEL      | 47    |
	| 45    | SIG RET   | -C/D      | 46    | - | 23    | SIG RET   | -C/D      | 48    |
	| 47    | SIG RET   | -REQ      | 48    | - | 24    | SIG RET   | -REQ      | 49    |
	| 49    | SIG RET   | -I/O      | 50    | - | 25    | SIG RET   | -I/O      | 50    |

	|           Table 14 (SPI-4)            |
	|                  SE                   |
	| Pin # | Signal    | Signal    | Pin # |
	|-------|-----------|-----------|-------|
	| 1     | SIG RET   | -DB12     | 35    |
	| 2     | SIG RET   | -DB13     | 36    |
	| 3     | SIG RET   | -DB14     | 37    |
	| 4     | SIG RET   | -DB15     | 38    |
	| 5     | SIG RET   | -DBP1     | 39    |
	| 6     | SIG RET   | -DB0      | 40    |
	| 7     | SIG RET   | -DB1      | 41    |
	| 8     | SIG RET   | -DB2      | 42    |
	| 9     | SIG RET   | -DB3      | 43    |
	| 10    | SIG RET   | -DB4      | 44    |
	| 11    | SIG RET   | -DB5      | 45    |
	| 12    | SIG RET   | -DB6      | 46    |
	| 13    | SIG RET   | -DB7      | 47    |
	| 14    | SIG RET   | -DBP      | 48    |
	| 15    | GND       | GND       | 49    |
	| 16    | GND       | GND       | 50    |
	| 17    | TERMPWR   | TERMPWR   | 51    |
	| 18    | TERMPWR   | TERMPWR   | 52    |
	| 19    | RESERVED  | RESERVED  | 53    |
	| 20    | GND       | GND       | 54    |
	| 21    | SIG RET   | -ATN      | 55    |
	| 22    | GND       | GND       | 56    |
	| 23    | SIG RET   | -BSY      | 57    |
	| 24    | SIG RET   | -ACK      | 58    |
	| 25    | SIG RET   | -RST      | 59    |
	| 26    | SIG RET   | -MSG      | 60    |
	| 27    | SIG RET   | -SEL      | 61    |
	| 28    | SIG RET   | -C/D      | 62    |
	| 29    | SIG RET   | -REQ      | 63    |
	| 30    | SIG RET   | -I/O      | 64    |
	| 31    | SIG RET   | -DB8      | 65    |
	| 32    | SIG RET   | -DB9      | 66    |
	| 33    | SIG RET   | -DB10     | 67    |
	| 34    | SIG RET   | -DB11     | 68    |

	|           Table 15 (SPI-4)            |
	|                  SE                   |
	| Pin # | Signal    | Signal    | Pin # |
	|-------|-----------|-----------|-------|
	| 1     | 12V CHRG  | 12V GND   | 41    |
	| 2     | 12V       | 12V GND   | 42    |
	| 3     | 12V       | 12V GND   | 43    |
	| 4     | 12V       | MATED 1   | 44    |
	| 5     | 3.3V      | 3.3V CHRG | 45    |
	| 6     | 3.3V      | GND       | 46    |
	| 7     | -DB11     | SIG RET   | 47    |
	| 8     | -DB10     | SIG RET   | 48    |
	| 9     | -DB9      | SIG RET   | 49    |
	| 10    | -DB8      | SIG RET   | 50    |
	| 11    | -I/O      | SIG RET   | 51    |
	| 12    | -REQ      | SIG RET   | 52    |
	| 13    | -C/D      | SIG RET   | 53    |
	| 14    | -SEL      | SIG RET   | 54    |
	| 15    | -MSG      | SIG RET   | 55    |
	| 16    | -RST      | SIG RET   | 56    |
	| 17    | -ACK      | SIG RET   | 57    |
	| 18    | -BSY      | SIG RET   | 58    |
	| 19    | -ATN      | SIG RET   | 59    |
	| 20    | -DBP      | SIG RET   | 60    |
	| 21    | -DB7      | SIG RET   | 61    |
	| 22    | -DB6      | SIG RET   | 62    |
	| 23    | -DB5      | SIG RET   | 63    |
	| 24    | -DB4      | SIG RET   | 64    |
	| 25    | -DB3      | SIG RET   | 65    |
	| 26    | -DB2      | SIG RET   | 66    |
	| 27    | -DB1      | SIG RET   | 67    |
	| 28    | -DB0      | SIG RET   | 68    |
	| 29    | -DBP1     | SIG RET   | 69    |
	| 30    | -DB15     | SIG RET   | 70    |
	| 31    | -DB14     | SIG RET   | 71    |
	| 32    | -DB13     | SIG RET   | 72    |
	| 33    | -DB12     | SIG RET   | 73    |
	| 34    | 5V        | MATED 2   | 74    |
	| 35    | 5V        | 5V GND    | 75    |
	| 36    | 5V CHRG   | 5V GND    | 76    |
	| 37    | SPINDLE   | LED OUT   | 77    |
	| 38    | RMT_START | DLYD_STRT | 78    |
	| 39    | SCSI ID 0 | SCSI ID 1 | 79    |
	| 40    | SCSI ID 2 | SCSI ID 3 | 80    |

	|          Table 16:1 (SPI-4)           | - |          Table 16:2 (SPI-4)           |
	|                LVD/MSE                | - |                LVD/MSE                |
	| Pin # | Signal    | Signal    | Pin # | - | Pin # | Signal    | Signal    | Pin # |
	|-------|-----------|-----------|-------| - |-------|-----------|-----------|-------|
	| 1     | +DB0      | -DB0      | 2     | - | 1     | +DB0      | -DB0      | 26    |
	| 3     | +DB1      | -DB1      | 4     | - | 2     | +DB1      | -DB1      | 27    |
	| 5     | +DB2      | -DB2      | 6     | - | 3     | +DB2      | -DB2      | 28    |
	| 7     | +DB3      | -DB3      | 8     | - | 4     | +DB3      | -DB3      | 29    |
	| 9     | +DB4      | -DB4      | 10    | - | 5     | +DB4      | -DB4      | 30    |
	| 11    | +DB5      | -DB5      | 12    | - | 6     | +DB5      | -DB5      | 31    |
	| 13    | +DB6      | -DB6      | 14    | - | 7     | +DB6      | -DB6      | 32    |
	| 15    | +DB7      | -DB7      | 16    | - | 8     | +DB7      | -DB7      | 33    |
	| 17    | +DBP      | -DBP      | 18    | - | 9     | +DBP      | -DBP      | 34    |
	| 19    | GND       | GND       | 20    | - | 10    | GND       | GND       | 35    |
	| 21    | DIFFSENS  | GND       | 22    | - | 11    | DIFFSENS  | GND       | 36    |
	| 23    | RESERVED  | RESERVED  | 24    | - | 12    | RESERVED  | RESERVED  | 37    |
	| 25    | TERMPWR   | TERMPWR   | 26    | - | 13    | TERMPWR   | TERMPWR   | 38    |
	| 27    | RESERVED  | RESERVED  | 28    | - | 14    | RESERVED  | RESERVED  | 39    |
	| 29    | GND       | GND       | 30    | - | 15    | GND       | GND       | 40    |
	| 31    | +ATN      | -ATN      | 32    | - | 16    | +ATN      | -ATN      | 41    |
	| 33    | GND       | GND       | 34    | - | 17    | GND       | GND       | 42    |
	| 35    | +BSY      | -BSY      | 36    | - | 18    | +BSY      | -BSY      | 43    |
	| 37    | +ACK      | -ACK      | 38    | - | 19    | +ACK      | -ACK      | 44    |
	| 39    | +RST      | -RST      | 40    | - | 20    | +RST      | -RST      | 45    |
	| 41    | +MSG      | -MSG      | 42    | - | 21    | +MSG      | -MSG      | 56    |
	| 43    | +SEL      | -SEL      | 44    | - | 22    | +SEL      | -SEL      | 47    |
	| 45    | +C/D      | -C/D      | 46    | - | 23    | +C/D      | -C/D      | 48    |
	| 47    | +REQ      | -REQ      | 48    | - | 24    | +REQ      | -REQ      | 49    |
	| 49    | +I/O      | -I/O      | 50    | - | 25    | +I/O      | -I/O      | 50    |

	|           Table 17 (SPI-4)            |
	|                LVD/MSE                |
	| Pin # | Signal    | Signal    | Pin # |
	|-------|-----------|-----------|-------|
	| 1     | +DB12     | -DB12     | 35    |
	| 2     | +DB13     | -DB13     | 36    |
	| 3     | +DB14     | -DB14     | 37    |
	| 4     | +DB15     | -DB15     | 38    |
	| 5     | +DBP1     | -DBP1     | 39    |
	| 6     | +DB0      | -DB0      | 40    |
	| 7     | +DB1      | -DB1      | 41    |
	| 8     | +DB2      | -DB2      | 42    |
	| 9     | +DB3      | -DB3      | 43    |
	| 10    | +DB4      | -DB4      | 44    |
	| 11    | +DB5      | -DB5      | 45    |
	| 12    | +DB6      | -DB6      | 46    |
	| 13    | +DB7      | -DB7      | 47    |
	| 14    | +DBP      | -DBP      | 48    |
	| 15    | GND       | GND       | 49    |
	| 16    | DIFFSENS  | GND       | 50    |
	| 17    | TERMPWR   | TERMPWR   | 51    |
	| 18    | TERMPWR   | TERMPWR   | 52    |
	| 19    | RESERVED  | RESERVED  | 53    |
	| 20    | GND       | GND       | 54    |
	| 21    | +ATN      | -ATN      | 55    |
	| 22    | GND       | GND       | 56    |
	| 23    | +BSY      | -BSY      | 57    |
	| 24    | +ACK      | -ACK      | 58    |
	| 25    | +RST      | -RST      | 59    |
	| 26    | +MSG      | -MSG      | 60    |
	| 27    | +SEL      | -SEL      | 61    |
	| 28    | +C/D      | -C/D      | 62    |
	| 29    | +REQ      | -REQ      | 63    |
	| 30    | +I/O      | -I/O      | 64    |
	| 31    | +DB8      | -DB8      | 65    |
	| 32    | +DB9      | -DB9      | 66    |
	| 33    | +DB10     | -DB10     | 67    |
	| 34    | +DB11     | -DB11     | 68    |

	|            Table 18 (SPI-4)           |
	|                LVD/MSE                |
	| Pin # | Signal    | Signal    | Pin # |
	|-------|-----------|-----------|-------|
	| 1     | 12V CHRG  | 12V GND   | 41    |
	| 2     | 12V       | 12V GND   | 42    |
	| 3     | 12V       | 12V GND   | 43    |
	| 4     | 12V       | MATED 1   | 44    |
	| 5     | 3.3V      | 3.3V CHRG | 45    |
	| 6     | 3.3V      | DIFFSENS  | 46    |
	| 7     | -DB11     | +DB11     | 47    |
	| 8     | -DB10     | +DB10     | 48    |
	| 9     | -DB9      | +DB9      | 49    |
	| 10    | -DB8      | +DB8      | 50    |
	| 11    | -I/O      | +I/O      | 51    |
	| 12    | -REQ      | +REQ      | 52    |
	| 13    | -C/D      | +C/D      | 53    |
	| 14    | -SEL      | +SEL      | 54    |
	| 15    | -MSG      | +MSG      | 55    |
	| 16    | -RST      | +RST      | 56    |
	| 17    | -ACK      | +ACK      | 57    |
	| 18    | -BSY      | +BSY      | 58    |
	| 19    | -ATN      | +ATN      | 59    |
	| 20    | -DBP      | +DBP      | 60    |
	| 21    | -DB7      | +DB7      | 61    |
	| 22    | -DB6      | +DB6      | 62    |
	| 23    | -DB5      | +DB5      | 63    |
	| 24    | -DB4      | +DB4      | 64    |
	| 25    | -DB3      | +DB3      | 65    |
	| 26    | -DB2      | +DB2      | 66    |
	| 27    | -DB1      | +DB1      | 67    |
	| 28    | -DB0      | +DB0      | 68    |
	| 29    | -DBP1     | +DBP1     | 69    |
	| 30    | -DB15     | +DB15     | 70    |
	| 31    | -DB14     | +DB14     | 71    |
	| 32    | -DB13     | +DB13     | 72    |
	| 33    | -DB12     | +DB12     | 73    |
	| 34    | 5V        | MATED 2   | 74    |
	| 35    | 5V        | 5V GND    | 75    |
	| 36    | 5V CHRG   | 5V GND    | 76    |
	| 37    | SPINDLE   | LED OUT   | 77    |
	| 38    | RMT_START | DLYD_STRT | 78    |
	| 39    | SCSI ID 0 | SCSI ID 1 | 79    |
	| 40    | SCSI ID 2 | SCSI ID 3 | 80    |

SPI-5 R06 (SCSI-3)

	|           Table 13:1 (SPI-5)          | - |           Table 13:2 (SPI-5)          |
	|                  LVD                  | - |                  LVD                  |
	| Pin # | Signal    | Signal    | Pin # | - | Pin # | Signal    | Signal    | Pin # |
	|-------|-----------|-----------|-------| - |-------|-----------|-----------|-------|
	| 1     | +DB0      | -DB0      | 2     | - | 1     | +DB0      | -DB0      | 26    |
	| 3     | +DB1      | -DB1      | 4     | - | 2     | +DB1      | -DB1      | 27    |
	| 5     | +DB2      | -DB2      | 6     | - | 3     | +DB2      | -DB2      | 28    |
	| 7     | +DB3      | -DB3      | 8     | - | 4     | +DB3      | -DB3      | 29    |
	| 9     | +DB4      | -DB4      | 10    | - | 5     | +DB4      | -DB4      | 30    |
	| 11    | +DB5      | -DB5      | 12    | - | 6     | +DB5      | -DB5      | 31    |
	| 13    | +DB6      | -DB6      | 14    | - | 7     | +DB6      | -DB6      | 32    |
	| 15    | +DB7      | -DB7      | 16    | - | 8     | +DB7      | -DB7      | 33    |
	| 17    | +DBP      | -DBP      | 18    | - | 9     | +DBP      | -DBP      | 34    |
	| 19    | GND       | GND       | 20    | - | 10    | GND       | GND       | 35    |
	| 21    | DIFFSENS  | GND       | 22    | - | 11    | DIFFSENS  | GND       | 36    |
	| 23    | RESERVED  | RESERVED  | 24    | - | 12    | RESERVED  | RESERVED  | 37    |
	| 25    | TERMPWR   | TERMPWR   | 26    | - | 13    | TERMPWR   | TERMPWR   | 38    |
	| 27    | RESERVED  | RESERVED  | 28    | - | 14    | RESERVED  | RESERVED  | 39    |
	| 29    | GND       | GND       | 30    | - | 15    | GND       | GND       | 40    |
	| 31    | +ATN      | -ATN      | 32    | - | 16    | +ATN      | -ATN      | 41    |
	| 33    | GND       | GND       | 34    | - | 17    | GND       | GND       | 42    |
	| 35    | +BSY      | -BSY      | 36    | - | 18    | +BSY      | -BSY      | 43    |
	| 37    | +ACK      | -ACK      | 38    | - | 19    | +ACK      | -ACK      | 44    |
	| 39    | +RST      | -RST      | 40    | - | 20    | +RST      | -RST      | 45    |
	| 41    | +MSG      | -MSG      | 42    | - | 21    | +MSG      | -MSG      | 56    |
	| 43    | +SEL      | -SEL      | 44    | - | 22    | +SEL      | -SEL      | 47    |
	| 45    | +C/D      | -C/D      | 46    | - | 23    | +C/D      | -C/D      | 48    |
	| 47    | +REQ      | -REQ      | 48    | - | 24    | +REQ      | -REQ      | 49    |
	| 49    | +I/O      | -I/O      | 50    | - | 25    | +I/O      | -I/O      | 50    |

	|            Table 14 (SPI-5)           |
	|                  LVD                  |
	| Pin # | Signal    | Signal    | Pin # |
	|-------|-----------|-----------|-------|
	| 1     | +DB12     | -DB12     | 35    |
	| 2     | +DB13     | -DB13     | 36    |
	| 3     | +DB14     | -DB14     | 37    |
	| 4     | +DB15     | -DB15     | 38    |
	| 5     | +DBP1     | -DBP1     | 39    |
	| 6     | +DB0      | -DB0      | 40    |
	| 7     | +DB1      | -DB1      | 41    |
	| 8     | +DB2      | -DB2      | 42    |
	| 9     | +DB3      | -DB3      | 43    |
	| 10    | +DB4      | -DB4      | 44    |
	| 11    | +DB5      | -DB5      | 45    |
	| 12    | +DB6      | -DB6      | 46    |
	| 13    | +DB7      | -DB7      | 47    |
	| 14    | +DBP      | -DBP      | 48    |
	| 15    | GND       | GND       | 49    |
	| 16    | DIFFSENS  | GND       | 50    |
	| 17    | TERMPWR   | TERMPWR   | 51    |
	| 18    | TERMPWR   | TERMPWR   | 52    |
	| 19    | RESERVED  | RESERVED  | 53    |
	| 20    | GND       | GND       | 54    |
	| 21    | +ATN      | -ATN      | 55    |
	| 22    | GND       | GND       | 56    |
	| 23    | +BSY      | -BSY      | 57    |
	| 24    | +ACK      | -ACK      | 58    |
	| 25    | +RST      | -RST      | 59    |
	| 26    | +MSG      | -MSG      | 60    |
	| 27    | +SEL      | -SEL      | 61    |
	| 28    | +C/D      | -C/D      | 62    |
	| 29    | +REQ      | -REQ      | 63    |
	| 30    | +I/O      | -I/O      | 64    |
	| 31    | +DB8      | -DB8      | 65    |
	| 32    | +DB9      | -DB9      | 66    |
	| 33    | +DB10     | -DB10     | 67    |
	| 34    | +DB11     | -DB11     | 68    |

	|            Table 15 (SPI-5)           |
	|                  LVD                  |
	| Pin # | Signal    | Signal    | Pin # |
	|-------|-----------|-----------|-------|
	| 1     | 12V CHRG  | 12V GND   | 41    |
	| 2     | 12V       | 12V GND   | 42    |
	| 3     | 12V       | 12V GND   | 43    |
	| 4     | 12V       | MATED 1   | 44    |
	| 5     | 3.3V      | 3.3V CHRG | 45    |
	| 6     | 3.3V      | DIFFSENS  | 46    |
	| 7     | -DB11     | +DB11     | 47    |
	| 8     | -DB10     | +DB10     | 48    |
	| 9     | -DB9      | +DB9      | 49    |
	| 10    | -DB8      | +DB8      | 50    |
	| 11    | -I/O      | +I/O      | 51    |
	| 12    | -REQ      | +REQ      | 52    |
	| 13    | -C/D      | +C/D      | 53    |
	| 14    | -SEL      | +SEL      | 54    |
	| 15    | -MSG      | +MSG      | 55    |
	| 16    | -RST      | +RST      | 56    |
	| 17    | -ACK      | +ACK      | 57    |
	| 18    | -BSY      | +BSY      | 58    |
	| 19    | -ATN      | +ATN      | 59    |
	| 20    | -DBP      | +DBP      | 60    |
	| 21    | -DB7      | +DB7      | 61    |
	| 22    | -DB6      | +DB6      | 62    |
	| 23    | -DB5      | +DB5      | 63    |
	| 24    | -DB4      | +DB4      | 64    |
	| 25    | -DB3      | +DB3      | 65    |
	| 26    | -DB2      | +DB2      | 66    |
	| 27    | -DB1      | +DB1      | 67    |
	| 28    | -DB0      | +DB0      | 68    |
	| 29    | -DBP1     | +DBP1     | 69    |
	| 30    | -DB15     | +DB15     | 70    |
	| 31    | -DB14     | +DB14     | 71    |
	| 32    | -DB13     | +DB13     | 72    |
	| 33    | -DB12     | +DB12     | 73    |
	| 34    | 5V        | MATED 2   | 74    |
	| 35    | 5V        | 5V GND    | 75    |
	| 36    | 5V CHRG   | 5V GND    | 76    |
	| 37    | SPINDLE   | LED OUT   | 77    |
	| 38    | RMT_START | DLYD_STRT | 78    |
	| 39    | SCSI ID 0 | SCSI ID 1 | 79    |
	| 40    | SCSI ID 2 | SCSI ID 3 | 80    |

--------------------------------------

De-duplicated tables

HVD-50
	|                               SCSI-1, SCSI-2, SPI-2                               |
	|                                        HVD                                        |
	| Pin # | Signal    | Signal    | Pin # | - | Pin # | Signal    | Signal    | Pin # |
	|-------|-----------|-----------|-------| - |-------|-----------|-----------|-------|
	| 1     | GND       | GND       | 2     | - | 1     | GND       | GND       | 26    |
	| 3     | +DB0      | -DB0      | 4     | - | 2     | +DB0      | -DB0      | 27    |
	| 5     | +DB1      | -DB1      | 6     | - | 3     | +DB1      | -DB1      | 28    |
	| 7     | +DB2      | -DB2      | 8     | - | 4     | +DB2      | -DB2      | 29    |
	| 9     | +DB3      | -DB3      | 10    | - | 5     | +DB3      | -DB3      | 30    |
	| 11    | +DB4      | -DB4      | 12    | - | 6     | +DB4      | -DB4      | 31    |
	| 13    | +DB5      | -DB5      | 14    | - | 7     | +DB5      | -DB5      | 32    |
	| 15    | +DB6      | -DB6      | 16    | - | 8     | +DB6      | -DB6      | 33    |
	| 17    | +DB7      | -DB7      | 18    | - | 9     | +DB7      | -DB7      | 34    |
	| 19    | +DBP      | -DBP      | 20    | - | 10    | +DBP      | -DBP      | 35    |
	| 21    | DIFFSENS  | GND       | 22    | - | 11    | DIFFSENS  | GND       | 36    |
	| 23    | RESERVED* | RESERVED* | 24    | - | 12    | RESERVED* | RESERVED* | 37    |
	| 25    | TERMPWR   | TERMPWR   | 26    | - | 13    | TERMPWR   | TERMPWR   | 38    |
	| 27    | RESERVED* | RESERVED* | 28    | - | 14    | RESERVED* | RESERVED* | 39    |
	| 29    | +ATN      | -ATN      | 30    | - | 15    | +ATN      | -ATN      | 40    |
	| 31    | GND       | GND       | 32    | - | 16    | GND       | GND       | 41    |
	| 33    | +BSY      | -BSY      | 34    | - | 17    | +BSY      | -BSY      | 42    |
	| 35    | +ACK      | -ACK      | 36    | - | 18    | +ACK      | -ACK      | 43    |
	| 37    | +RST      | -RST      | 38    | - | 19    | +RST      | -RST      | 44    |
	| 39    | +MSG      | -MSG      | 40    | - | 20    | +MSG      | -MSG      | 45    |
	| 41    | +SEL      | -SEL      | 42    | - | 21    | +SEL      | -SEL      | 56    |
	| 43    | +C/D      | -C/D      | 44    | - | 22    | +C/D      | -C/D      | 47    |
	| 45    | +REQ      | -REQ      | 46    | - | 23    | +REQ      | -REQ      | 48    |
	| 47    | +I/O      | -I/O      | 48    | - | 24    | +I/O      | -I/O      | 49    |
	| 49    | GND       | GND       | 50    | - | 25    | GND       | GND       | 50    |
* GND in SCSI-1, SCSI-2 makes these "RESERVED"

Left-hand table uses wire pin (odd-even) numbering, right-hand table uses clockwise pin numbering.

MSE-50
	|                     SCSI-1, SCSI-2, SPI-2, SPI-3, SPI-4, SPI-5                    |
	|                                    LVD/MSE/SE                                     |
	| Pin # | Signal    | Signal    | Pin # | - | Pin # | Signal    | Signal    | Pin # |
	|-------|-----------|-----------|-------| - |-------|-----------|-----------|-------|
	| 1     | +DB0†     | -DB0      | 2     | - | 1     | +DB0†     | -DB0      | 26    |
	| 3     | +DB1†     | -DB1      | 4     | - | 2     | +DB1†     | -DB1      | 27    |
	| 5     | +DB2†     | -DB2      | 6     | - | 3     | +DB2†     | -DB2      | 28    |
	| 7     | +DB3†     | -DB3      | 8     | - | 4     | +DB3†     | -DB3      | 29    |
	| 9     | +DB4†     | -DB4      | 10    | - | 5     | +DB4†     | -DB4      | 30    |
	| 11    | +DB5†     | -DB5      | 12    | - | 6     | +DB5†     | -DB5      | 31    |
	| 13    | +DB6†     | -DB6      | 14    | - | 7     | +DB6†     | -DB6      | 32    |
	| 15    | +DB7†     | -DB7      | 16    | - | 8     | +DB7†     | -DB7      | 33    |
	| 17    | +DBP†     | -DBP      | 18    | - | 9     | +DBP†     | -DBP      | 34    |
	| 19    | GND       | GND       | 20    | - | 10    | GND       | GND       | 35    |
	| 21    | DIFFSENS‡ | GND       | 22    | - | 11    | DIFFSENS‡ | GND       | 36    |
	| 23    | RESERVED* | RESERVED* | 24    | - | 12    | RESERVED* | RESERVED* | 37    |
	| 25    | NC        | TERMPWR   | 26    | - | 13    | NC        | TERMPWR   | 38    |
	| 27    | RESERVED* | RESERVED* | 28    | - | 14    | RESERVED* | RESERVED* | 39    |
	| 29    | GND       | GND       | 30    | - | 15    | GND       | GND       | 40    |
	| 31    | +ATN†     | -ATN      | 32    | - | 16    | +ATN†     | -ATN      | 41    |
	| 33    | GND       | GND       | 34    | - | 17    | GND       | GND       | 42    |
	| 35    | +BSY†     | -BSY      | 36    | - | 18    | +BSY†     | -BSY      | 43    |
	| 37    | +ACK†     | -ACK      | 38    | - | 19    | +ACK†     | -ACK      | 44    |
	| 39    | +RST†     | -RST      | 40    | - | 20    | +RST†     | -RST      | 45    |
	| 41    | +MSG†     | -MSG      | 42    | - | 21    | +MSG†     | -MSG      | 56    |
	| 43    | +SEL†     | -SEL      | 44    | - | 22    | +SEL†     | -SEL      | 47    |
	| 45    | +C/D†     | -C/D      | 46    | - | 23    | +C/D†     | -C/D      | 48    |
	| 47    | +REQ†     | -REQ      | 48    | - | 24    | +REQ†     | -REQ      | 49    |
	| 49    | +I/O†     | -I/O      | 50    | - | 25    | +I/O†     | -I/O      | 50    |
* GND in SCSI-1, SCSI-2 makes these "RESERVED"
† GND in SCSI-1 and SCSI-2, SPI-2 makes these "SIG-RET" which is entirely equivalent
‡ GND in SE, which is used to distinguish that from LVD

Left-hand table uses wire pin (odd-even) numbering, right-hand table uses clockwise pin numbering.

SCA-80
	|      SPI-2, SPI-3, SPI-4, SPI-5       |
	|            HVD/LVD/MSE/SE             |
	| Pin # | Signal    | Signal    | Pin # |
	|-------|-----------|-----------|-------|
	| 1     | 12V CHRG  | 12V GND   | 41    |
	| 2     | 12V       | 12V GND   | 42    |
	| 3     | 12V       | 12V GND   | 43    |
	| 4     | 12V       | MATED 1   | 44    |
	| 5     | 3.3V      | 3.3V CHRG | 45    |
	| 6     | 3.3V      | DIFFSENS‡ | 46    |
	| 7     | -DB11     | +DB11†    | 47    |
	| 8     | -DB10     | +DB10†    | 48    |
	| 9     | -DB9      | +DB9†     | 49    |
	| 10    | -DB8      | +DB8†     | 50    |
	| 11    | -I/O      | +I/O†     | 51    |
	| 12    | -REQ      | +REQ†     | 52    |
	| 13    | -C/D      | +C/D†     | 53    |
	| 14    | -SEL      | +SEL†     | 54    |
	| 15    | -MSG      | +MSG†     | 55    |
	| 16    | -RST      | +RST†     | 56    |
	| 17    | -ACK      | +ACK†     | 57    |
	| 18    | -BSY      | +BSY†     | 58    |
	| 19    | -ATN      | +ATN†     | 59    |
	| 20    | -DBP      | +DBP†     | 60    |
	| 21    | -DB7      | +DB7†     | 61    |
	| 22    | -DB6      | +DB6†     | 62    |
	| 23    | -DB5      | +DB5†     | 63    |
	| 24    | -DB4      | +DB4†     | 64    |
	| 25    | -DB3      | +DB3†     | 65    |
	| 26    | -DB2      | +DB2†     | 66    |
	| 27    | -DB1      | +DB1†     | 67    |
	| 28    | -DB0      | +DB0†     | 68    |
	| 29    | -DBP1     | +DBP1†    | 69    |
	| 30    | -DB15     | +DB15†    | 70    |
	| 31    | -DB14     | +DB14†    | 71    |
	| 32    | -DB13     | +DB13†    | 72    |
	| 33    | -DB12     | +DB12†    | 73    |
	| 34    | 5V        | MATED 2   | 74    |
	| 35    | 5V        | 5V GND    | 75    |
	| 36    | 5V CHRG   | 5V GND    | 76    |
	| 37    | SPINDLE   | LED OUT   | 77    |
	| 38    | RMT_START | DLYD_STRT | 78    |
	| 39    | SCSI ID 0 | SCSI ID 1 | 79    |
	| 40    | SCSI ID 2 | SCSI ID 3 | 80    |
† SIG RET in SE
‡ GND in SE, which is used to distinguish that from HVD/LVD

SCSI2-68
	|                SCSI-2                 |
	|                HVD/SE                 |
	| Pin # | Signal    | Signal    | Pin # |
	|-------|-----------|-----------|-------|
	| 1     | GND       | GND       | 35    |
	| 2     | +DB8†     | -DB8      | 36    |
	| 3     | +DB9†     | -DB9      | 37    |
	| 4     | +DB10†    | -DB10     | 38    |
	| 5     | +DB11†    | -DB11     | 39    |
	| 6     | +DB12†    | -DB12     | 40    |
	| 7     | +DB13†    | -DB13     | 41    |
	| 8     | +DB14†    | -DB14     | 42    |
	| 9     | +DB15†    | -DB15     | 43    |
	| 10    | +DBP1†    | -DBP1     | 44    |
	| 11    | +ACKB†    | -ACKB     | 45    |
	| 12    | GND       | DIFFSENS‡ | 46    |
	| 13    | +REQB†    | -REQB     | 47    |
	| 14    | +DB16†    | -DB16     | 48    |
	| 15    | +DB17†    | -DB17     | 49    |
	| 16    | +DB18†    | -DB18     | 50    |
	| 17    | TERMPWRB  | TERMPWRB  | 51    |
	| 18    | TERMPWRB  | TERMPWRB  | 52    |
	| 19    | +DB19†    | -DB19     | 53    |
	| 20    | +DB20†    | -DB20     | 54    |
	| 21    | +DB21†    | -DB21     | 55    |
	| 22    | +DB22†    | -DB22     | 56    |
	| 23    | +DB23†    | -DB23     | 57    |
	| 24    | +DBP2†    | -DBP2     | 58    |
	| 25    | +DB24†    | -DB24     | 59    |
	| 26    | +DB25†    | -DB25     | 60    |
	| 27    | +DB26†    | -DB26     | 61    |
	| 28    | +DB27†    | -DB27     | 62    |
	| 29    | +DB28†    | -DB28     | 63    |
	| 30    | +DB29†    | -DB29     | 64    |
	| 31    | +DB30†    | -DB30     | 65    |
	| 32    | +DB31†    | -DB31     | 66    |
	| 33    | +DBP3†    | -DBP3     | 67    |
	| 34    | GND       | GND       | 68    |
† GND in SCSI-2
‡ GND in SE, which is used to distinguish that from LVD

HVD-68
	|             SPI-1, SPI-2              |
	|                  HVD                  |
	| Pin # | Signal    | Signal    | Pin # |
	|-------|-----------|-----------|-------|
	| 1     | +DB12     | -DB12     | 35    |
	| 2     | +DB13     | -DB13     | 36    |
	| 3     | +DB14     | -DB14     | 37    |
	| 4     | +DB15     | -DB15     | 38    |
	| 5     | +DBP1     | -DBP1     | 39    |
	| 6     | GND       | GND       | 40    |
	| 7     | +DB0      | -DB0      | 41    |
	| 8     | +DB1      | -DB1      | 42    |
	| 9     | +DB2      | -DB2      | 43    |
	| 10    | +DB3      | -DB3      | 44    |
	| 11    | +DB4      | -DB4      | 45    |
	| 12    | +DB5      | -DB5      | 46    |
	| 13    | +DB6      | -DB6      | 47    |
	| 14    | +DB7      | -DB7      | 48    |
	| 15    | +DBP      | -DBP      | 49    |
	| 16    | DIFFSENS  | GND       | 50    |
	| 17    | TERMPWR   | TERMPWR   | 51    |
	| 18    | TERMPWR   | TERMPWR   | 52    |
	| 19    | RESERVED  | RESERVED  | 53    |
	| 20    | +ATN      | -ATN      | 54    |
	| 21    | GND       | GND       | 55    |
	| 22    | +BSY      | -BSY      | 56    |
	| 23    | +ACK      | -ACK      | 57    |
	| 24    | +RST      | -RST      | 58    |
	| 25    | +MSG      | -MSG      | 59    |
	| 26    | +SEL      | -SEL      | 60    |
	| 27    | +C/D      | -C/D      | 61    |
	| 28    | +REQ      | -REQ      | 62    |
	| 29    | +I/O      | -I/O      | 63    |
	| 30    | GND       | GND       | 64    |
	| 31    | +DB8      | -DB8      | 65    |
	| 32    | +DB9      | -DB9      | 66    |
	| 33    | +DB10     | -DB10     | 67    |
	| 34    | +DB11     | -DB11     | 68    |
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

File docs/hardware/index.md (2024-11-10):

```{warning}
Squishy hardware is specially designed and **is not** able to be substituted for other hardware at the moment. This include any popular development or eval boards.
```

# Hardware

```{toctree}
:hidden:

rev1
rev2
```

```{todo}
Flesh this section out
```

The squishy hardware is broken up into revisions and release levels. Each revision has breaking changes when it comes to hardware, and so they are their own platforms, however, release levels within each revision are hardware compatible with each other.

Both the revision and the release level start at 0, and increment by one. If the release level is omitted, it is assumed to be 0.

The format follows the `rev<#>[.#]` format, where `rev<#>` is the hardware revision and `[.#]` is the release level. so the following string, `rev8.3` is hardware revision 8, release 3.

Currently there are two hardware releases [`rev1`] and [`rev2`], see each page for details on each respective hardware revision.

## Getting Squishy Hardware

There are two main ways to get squishy hardware, buying it, or building it.

### Buying Hardware

```{note}
As of 2024-11-07, Squishy hardware is not available for sale, however, once engineering and validation of Revision 2 is completed, rev2 units are expected to be available to purchase.
```
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

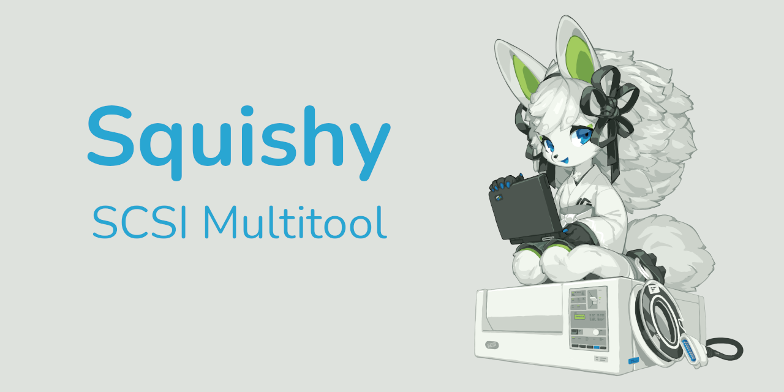
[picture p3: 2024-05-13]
docs/_images/og-image.png

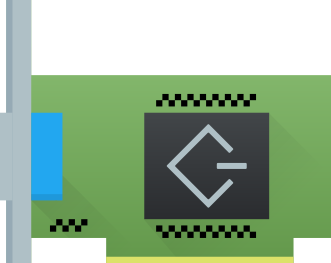
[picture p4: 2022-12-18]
contrib/img/scsi-card.png

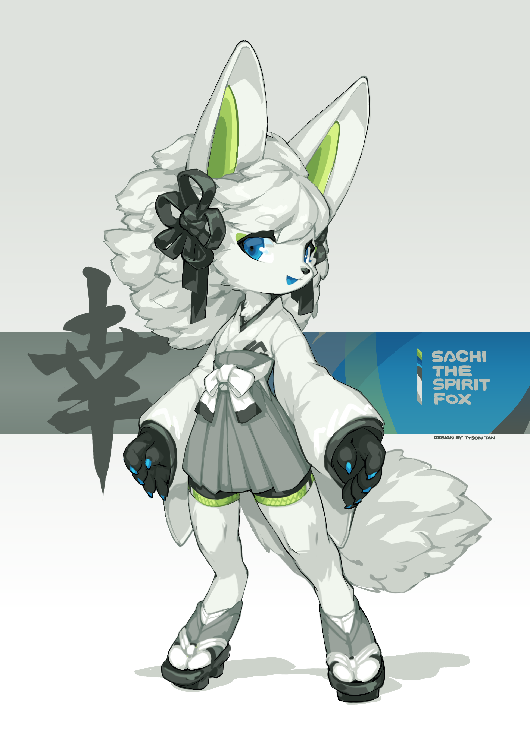
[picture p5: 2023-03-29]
contrib/img/sachi/electrichearts_20211013A_sachi.png

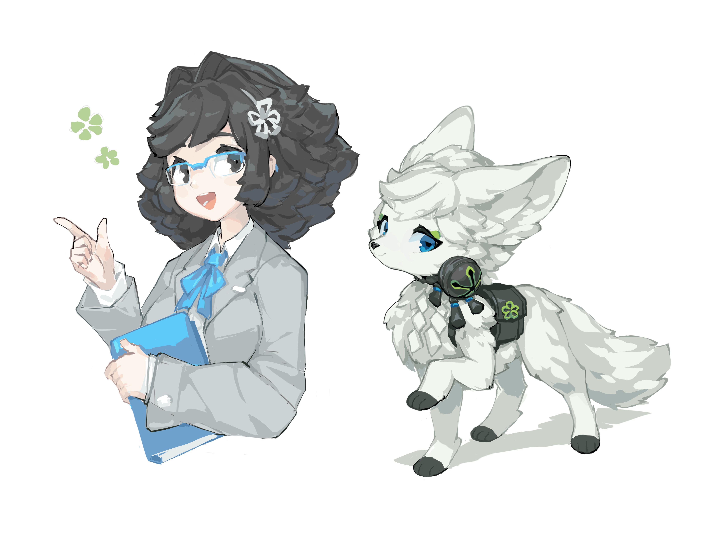
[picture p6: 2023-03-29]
contrib/img/sachi/electrichearts_20230322A_sachi_human_animal_trans.png

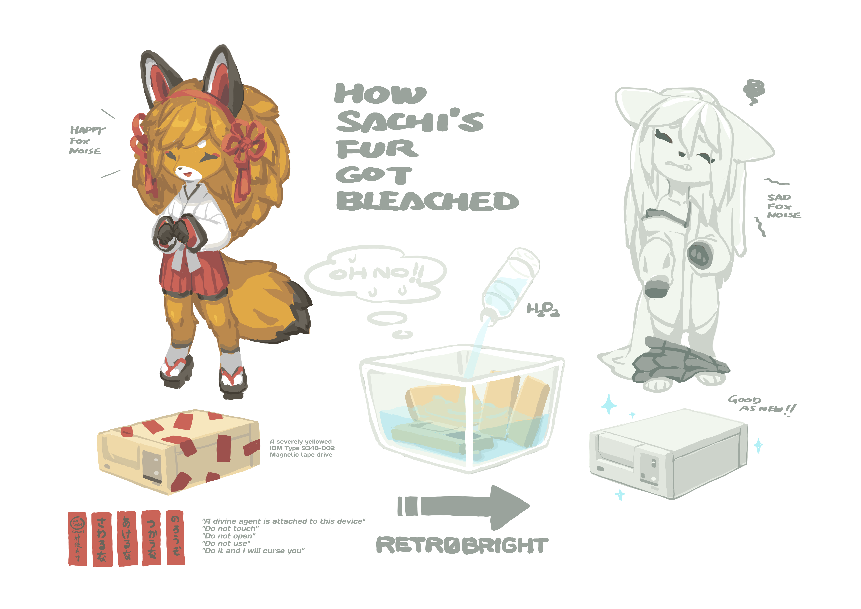
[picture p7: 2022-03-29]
contrib/img/sachi/electrichearts_20220325A_sachi_yellow_trans.png

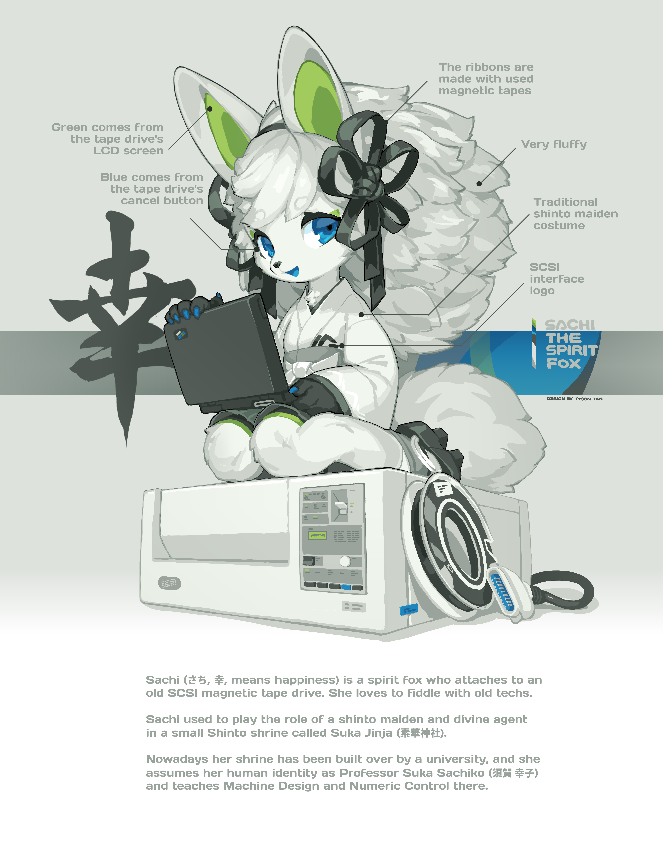
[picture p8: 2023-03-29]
contrib/img/sachi/electrichearts_20220323A_sachi_text_english.png

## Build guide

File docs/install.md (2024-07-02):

# Installation

```{warning}
The following instructions are a work-in-progress and may not be entirely up to date.
```

Squishy is a python application that can be installed via [`pip`],  either from the [git repository] or via a [wheel] package.

## System Requirements

Squishy is officially supported on most Linux distributions, the primary one being [Arch Linux] and variants there of. However other Linux distributions are supported as well.

Support for Microsoft Windows is preliminary, and due to lack of testing and development resources official support is currently not possible. But effort to make it as painless as possible to use on this platform is in-progress.

Support for Apple macOS is also unofficial, however due to its similarity to Linux and Unix-like operating systems, using Squishy on macOS should be just as painless as it is on Linux. Official support for macOS and other BSD-Family operating systems is planned.

Regardless of the operating system, there are some core dependencies that Squishy requires. This includes Python >= 3.10, [Yosys] >= 0.39, and [nextpnr] >= 0.7.

Squishy has been tested with [CPython], but might possibly run under [PyPy].

## Installing Prerequisites

Prior to installing Squishy, you must install all of its prerequisites and requirements.

### Installing Python

First off, install `python` and `pip` onto your system if the're not there already. It is also recommended to upgrade `pip` if not already to ensure all the steps work as expected.

```{eval-rst}
.. tab:: Arch-like

	.. code-block:: console

		$ sudo pacman -S python python-pip

.. tab:: Other Linux

	.. warning:: These instructions may be incorrect or incomplete!

	.. tab:: Debian-Like

		For `Debian <https://www.debian.org/>`_ based systems, use ``apt`` to install ``python3`` and ``python3-pip``

		.. code-block:: console

			$ sudo apt install python3 python3-pip

	.. tab:: Fedora-like

		For `Fedora <https://getfedora.org/>`_ and other ``dnf`` based systems,

		.. code-block:: console

			$ sudo dnf install python3 python3-pip

.. tab:: macOS

	Install `Homebrew <https://brew.sh/>`_ if not done already, then install the requirements.

	.. code-block:: console

		$ brew install python

.. tab:: Windows

	.. warning:: These instructions may be incorrect or incomplete!

	Download the latest Python installer from the `python downloads <https://www.python.org/downloads/>`_ page.

	Follow the instructions and ensure that the installer installs ``pip`` and puts the python executable in your ``%PATH%``

```
At this point, you may want to create a virtual environment for installing Squishy into:

```{eval-rst}
.. code-block:: console

	$ python -m venv squishy.venv
```

```{note}
If your python install doesn't have the `venv` module by default, then you will need to also install the python `virtualenv` package
```

You can then activate the virtual environment with:
```{eval-rst}
.. tab:: Arch-like

	.. code-block:: console

		$ . squishy.venv/bin/activate

.. tab:: Other Linux

	.. code-block:: console

		$ . squishy.venv/bin/activate

.. tab:: macOS

	.. code-block:: console

		$ . squishy.venv/bin/activate

.. tab:: Windows

	.. code-block:: console

		$ call squishy.venv/Scripts/activate.bat
```

### Installing Yosys and nextpnr

Next, you need to install [`yosys`] and [`nextpnr`] onto your system if it is not there already.

#### Native Install

The next option is to do a native install of the toolchain.

```{eval-rst}
.. tab:: Arch-like

	On Arch Linux and Arch-likes, you can install nightly packages which are located in the `AUR <https://aur.archlinux.org/>`_ with an AUR helper or using ``makepkg`` directly.

	Via an AUR helper like ``yay``

	.. code-block:: console

		$ yay -S yosys-nightly nextpnr-ice40-nightly nextpnr-ecp5-nightly

	Via ``makepkg`` directly

	.. code-block:: console

		$ git clone https://aur.archlinux.org/yosys-nightly.git
		$ git clone https://aur.archlinux.org/prjtrellis-nightly.git
		$ git clone https://aur.archlinux.org/icestorm-nightly.git
		$ git clone https://aur.archlinux.org/nextpnr-ecp5-nightly.git
		$ git clone https://aur.archlinux.org/nextpnr-ice40-nightly.git
		$ (cd yosys-nightly && makepkg -sic)
		$ (cd prjtrellis-nightly && makepkg -sic)
		$ (cd icestorm-nightly && makepkg -sic)
		$ (cd nextpnr-ecp5-nightly && makepkg -sic)
		$ (cd nextpnr-ice40-nightly && makepkg -sic)

.. tab:: Other Linux

	.. warning:: These instructions may be incorrect or incomplete!

	With other Linux distributions, it is recommended to use the `OSS Cad Suite <https://github.com/YosysHQ/oss-cad-suite-build>`_ nightly build. It provides a full environment of all the tools needed built on a nightly basis.

	Simply download the latest `release <https://github.com/YosysHQ/oss-cad-suite-build/releases>`_ for your architecture, extract it to a good home, and then add it to your ``$PATH``

	.. code-block:: console

		$ curl -LOJ https://github.com/YosysHQ/oss-cad-suite-build/releases/download/2024-07-02/oss-cad-suite-linux-x64-20240702.tgz
		$ tar xfv oss-cad-suite-linux-x64-20240702.tgz
		$ export PATH="`pwd`/oss-cad-suite/bin:$PATH"

.. tab:: macOS

	For macOS systems, it is recommended to use the YoWASP distribution of the toolchain. However if you want to use the native tools, and you are using an Intel based Mac, then the `OSS Cad Suite <https://github.com/YosysHQ/oss-cad-suite-build>`_ has nightly builds for x86_64 versions of Darwin.

	Simply download the latest `release <https://github.com/YosysHQ/oss-cad-suite-build/releases>`_ for your architecture, extract it to a good home, and then add it to your ``$PATH``

	.. code-block:: console

		$ curl -LOJ https://github.com/YosysHQ/oss-cad-suite-build/releases/download/2024-07-02/oss-cad-suite-darwin-x64-20240702.tgz
		$ tar xfv oss-cad-suite-darwin-x64-20240702.tgz
		$ export PATH="`pwd`/oss-cad-suite/bin:$PATH"

.. tab:: Windows

	.. warning:: These instructions may be incorrect or incomplete!

	For Windows systems, it is recommended to use the YoWASP distribution of the toolchain. However if you want to use the native tools, and you are using an Intel based PC, then the `OSS Cad Suite <https://github.com/YosysHQ/oss-cad-suite-build>`_ has nightly builds for x86_64 versions of Windows.

	Simply download the latest `release <https://github.com/YosysHQ/oss-cad-suite-build/releases>`_ for your architecture, extract it to a good home, and then add it to your ``%PATH%``

	.. code-block:: console

		$ call %cd%\oss-cad-suite\environment.bat

```

## Installing Squishy

```{eval-rst}
.. note::

	Due to some of squishy's dependencies, we can not publish a PyPi package at the moment.
```

Once all of the prerequisites are installed, you can finally install squishy into the virtual environment like so:

```{eval-rst}
.. code-block:: console

	(squishy.venv) $ pip install 'squishy @ git+https://github.com/squishy-scsi/squishy.git'
```

After that, check to make sure you have the `squishy` command:

```{eval-rst}
.. code-block:: console

	(squishy.venv) $ squishy --help
```

Now you can view the [Getting Started] page and start to use Squishy.

[`pip`]: https://pypi.org/project/pip/
[git repository]: https://github.com/squishy-scsi/squishy
[wheel]: https://pypi.org/project/wheel/
[Arch Linux]: https://archlinux.org/
[Yosys]: https://github.com/YosysHQ/yosys
[nextpnr]: https://github.com/YosysHQ/nextpnr
[CPython]: https://www.python.org/
[PyPy]: https://www.pypy.org/
[`yosys`]: https://github.com/YosysHQ/yosys
[`nextpnr`]: https://github.com/YosysHQ/nextpnr
[Getting Started]: ./getting_started.md

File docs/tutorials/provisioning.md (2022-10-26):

# Provisioning a New Device

```{toctree}
:hidden:

```

When you first build a squishy, or if the flash on your existing squishy gets corrupted, you will need to provision the device again. This is done by flashing a special image into the flash that contains the bootloader and stub bitstreams to ensure DFU works properly.

## Generating the Initial Image

To generate the initial image, we run squishy with the `provision` command like so:

```{eval-rst}
.. code-block:: console

	(squishy.venv) $ squishy provision --build-only --whole-device
```
The `--build-only` argument tells the `provision` command to build the but not program the image to a device, this means you can build it without a Squishy attached or for a blank Squishy.

The `--whole-device` argument tells `provision` to build the bootloader and bake the special device image that is to be flashed onto Squishy.

The resulting file `squishy-unified.bin` can then be flashed onto the SPI flash of the Squishy unit.

## Flashing the Image

To write the image to the Squishy device, you can hook up to the SPI header on the board using any capable tool and flash the whole `squishy-unified.bin` image. Once the device is then reset and able to read the new image, it will start in the bootloader waiting for an applet to be flashed to the device via the `squishy` utility or `dfu-util`.

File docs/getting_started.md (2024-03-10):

```{eval-rst}
.. figure:: ../contrib/img/sachi/doric-sachi.png
	:align: right
	:figwidth: 450px
```

# Getting Started

To get started with Squishy, first follow the [installation] instructions before you continue.

## Connecting the Hardware

```{todo}
Write this section
```

## Using the CLI

```{todo}
Write this section
```

[installation]: ./install.md

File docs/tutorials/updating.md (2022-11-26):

# Updating Squishy

```{toctree}
:hidden:

```

```
dfu-util -d 1209:ca70,:ca71 -a 0 -R -D ~/.cache/squishy/build/squishy_bootloader.bin
```

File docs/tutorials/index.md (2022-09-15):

# Tutorials

```{toctree}
:hidden:
applets/index
provisioning

```
## Hardware Usage

```{todo}
Write this section
```

## Software Usage

```{todo}
Write this section
```

## Applets

```{todo}
Write this section
```

## Gateware Library

```{todo}
Write this section
```

## Python Library

```{todo}
Write this section
```

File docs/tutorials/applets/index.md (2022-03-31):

# Custom Applets

```{toctree}
:hidden:

```

```{todo}
Write this section
```

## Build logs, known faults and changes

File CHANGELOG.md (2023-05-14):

# Changelog

All notable changes to this project will be documented in this file.

The format is based on [Keep a Changelog](https://keepachangelog.com/en/1.0.0/),
and this project adheres to [Semantic Versioning](https://semver.org/spec/v2.0.0.html).

<!--
Unreleased template stuff

## [Unreleased]
### Added
### Changed
### Deprecated
### Removed
### Fixed
### Security
-->

## [Unreleased]

[unreleased]: https://github.com/squishy-scsi/squishy/compare/543f4d29...main

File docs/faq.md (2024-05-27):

# Frequently Asked Questions

The following are some commonly asked questions, while this section is not exhaustive it will be updated when appropriate. For more specific questions, please join the IRC channel [#squishy on libera.chat] or use the [GitHub Discussions].

## Why should I use Squishy rather than one of the other SCSI projects?

That really depends on what you need. If you just want/need storage emulation, then please do go with one of the other projects, [BlueSCSI] et. al. are awesome projects and deserve your support.

But if you need something more flexible, or support for arcane hardware, then Squishy might be the right choice. It's not as turnkey as the other projects, but it is far more capable in more ways than one.

## Why is Squishy so complex?

Squishy, at first, seems overly complicated for what it is, after all, the other SCSI projects are fairly simple, not more than a handful of parts, where as Squishy is this monster with multiple boards, large power requirements and a complex software stack.

But it's for a good reason, Squishy was designed to be as capable, covering everything for SCSI-1 and HVD all the way to ULTRA-320 LVD, and everything between. Such capabilities demand complexity in order to be achieved, this is the primary driver behind the complexity of both the hardware and software ecosystem. However, this allows Squishy to be as flexible as possible, able to hopefully meet any possible needs that may arise.

## Why is Squishy using [Torii] rather than Amaranth or another HDL?

The reason for this is due to the fact ties into the original reason why Torii forked off from [Amaranth] in the first place. To keep it brief, it was primarily due to originally the stagnation of Amaranth at the time of the fork. Once pace of the development of Amaranth picked back up, it started to go in a design direction that was not quite what we wanted out of an HDL.

When using Torii, we have more tight integration in the development process between Squishy and Torii, they can effect and influence each other. We can also more rapidly respond to any bugs in the HDL without having to wait for a third party upstream.

## Why is Squishy so expensive?

This goes in tandem with [Why is Squishy so complex?](#why-is-squishy-so-complex). It is not expensive for the sake of being expensive, the upmost care and detail has been put in to the design, as such I like to say that Squishy is not built down to a price, but up to a standard, and that standard is very high.

This, unfortunately leads to the hardware being expensive, there is sadly nothing that can be done about that. However, as Squishy is 100% Open Source Hardware under the [CERN-OHL-S v2], you can go and build it yourself to try to cut down on costs. However, assembling Squishy yourself is not a trivial task due to several large BGA components and fairly tight tolerances for manufacturing.

## Why Does Squishy not have a Discord?

Squishy likes to do things out in the open, this means that Discords model of walled-off communities is not conducive to how we want to do things. In addition to this, there is a trend to moving documentation away from things like Wiki's and websites into Discord servers, which causes that information to no longer be publicly accessible, this is a huge problem when it comes to things like Open Source projects such as Squishy.

All in all, to make things easier on both the maintainers and community members, we are staying away from Discord for the forseeable future. We have an <a href="irc://irc.libera.chat:6667/#squishy">IRC chanel</a> for developer talk and general chatting, and for everything else we have the [GitHub Discussions], [Issue tracker], and this website.

[#squishy on libera.chat]: https://web.libera.chat/#squishy
[GitHub Discussions]: https://github.com/squishy-scsi/squishy/discussions
[Issue tracker]: https://github.com/squishy-scsi/squishy/issues
[BlueSCSI]: https://scsi.blue/
[CERN-OHL-S v2]: https://ohwr.org/cern_ohl_s_v2.pdf
[Torii]: https://github.com/shrine-maiden-heavy-industries/torii-hdl/
[Amaranth]: https://github.com/amaranth-lang/amaranth

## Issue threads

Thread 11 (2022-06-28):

Layout rev2 tempwr ADC and switching

lethalbit, 2022-06-28:
The rev2 hardware has a current/voltage ADC to measure TERMPWR to try to detect if the hardware has a fault.

This ADC as well as the TERMPWR enable/disable circuitry needs to be laid out and hooked up.

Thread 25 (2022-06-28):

micro SD Card SPI/SDIO Support

lethalbit, 2022-06-28:
The rev2 hardware has an on-board micro SD Card slot for storage emulation or other possible features, ideally the communication would be over SDIO if possible, but fallback to SPI mode for the SD Card might be needed.

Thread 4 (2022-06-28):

Complete rev2 FPGA Supervisor layout

lethalbit, 2022-06-28:
The layout for the FPGA supervisor mcu needs to be completed.

- [ ] Connect SPI bus + control signals to FPGA
- [ ] Connect SPI bus to onboard flash
- [ ] Connect LEDs
- [ ] Connect to DFU trigger button

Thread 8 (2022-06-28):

Design rev2 Physical bus interfaces

lethalbit, 2022-06-28:
The rev2 hardware is designed to have an interchangable bus / device front-end based on using the Samtec QTH-060-01-X-D-RA-PGP as it's connector.

Ideally we will have a board for each of the following SCSI connectors, more than one per board is okay, in the case of the IDC connectors and other small connectors.

- [ ] HD50
- [ ] DB25
- [ ] HD68
- [ ] C50
- [ ] IDC50
- [ ] IDC68
- [ ] SCA80
- [ ] VHDCI
- [ ] MD50
- [ ] MD68

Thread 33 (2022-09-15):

Add detection for yowasp-yosys/nextpnr

lethalbit, 2022-09-15:
When using the Yowasp builds of Yosys and nextpnr there is an issue with detecting them and using them when trying to build gateware. We need to add detection for this and warn if we don't find any of them.

lethalbit, 2023-01-21:
Debating if this should be deprecated and just replaced with [OSS CAD Suite](https://github.com/YosysHQ/oss-cad-suite-build)

lethalbit, 2023-05-12:
As we switched [Torii](https://github.com/shrine-maiden-heavy-industries/torii-hdl), we're dropping yowasp, as such we will be going with the [OSS CAD Suite](https://github.com/YosysHQ/oss-cad-suite-build) as part of setup, either packaged with Squishy software as part of the distribution, or as a needed dep.

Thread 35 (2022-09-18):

[PACKAGING] Debian / deb

lethalbit, 2022-09-18:
Setup / Automate packaging for Debian / apt/dpkg based distributions

laf0rge, 2023-10-08:
I'm wondering about the scope: Is this ticket on packaging just for host software, or also for firmware or even gateware?

In any case, I can strongly recommend using [OBS](https://openbuildservice.org/help/manuals/obs-user-guide/) for building for a variety of dpkg (Debian/Ubuntu/Raspbian) as well as rpm (OpenSuse, Fedora, ...) distributions.  We have years of experience in building lots of packages this way at [Osmocom](https://osmocom.org/) and are generally very happy with the OBS software/system.

You can play with OBS on https://build.opensuse.org/

I'm happy to help once the scope is becoming a bit more clear to me.

lethalbit, 2023-10-08:
In this case the gateware and host software are on and the same, as they are directly coupled and the gateware itself is generated based on the applet configuration.

I've not heard of that OBS, i'll give it a look and have a play around with it when I can. Currently the software is a bit on hold as I get working on the rev2 hardware again, which should fix all the problems and limitations with the rev1 hardware.

But yeah, i'll give OBS a poke and report back when I have the time~

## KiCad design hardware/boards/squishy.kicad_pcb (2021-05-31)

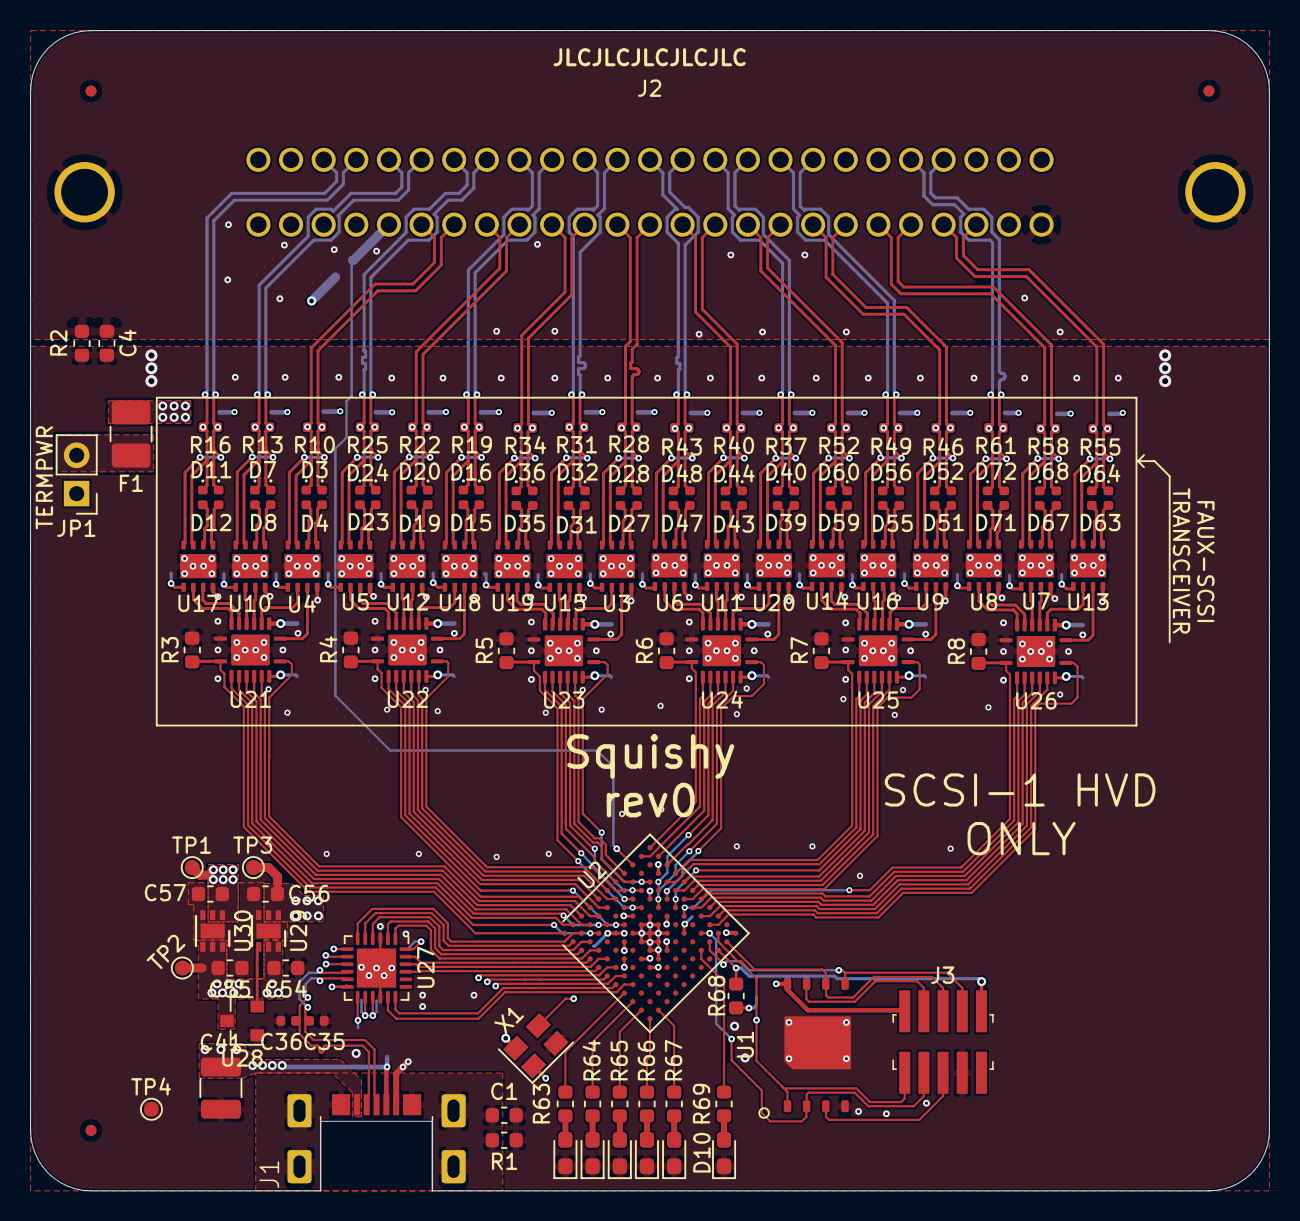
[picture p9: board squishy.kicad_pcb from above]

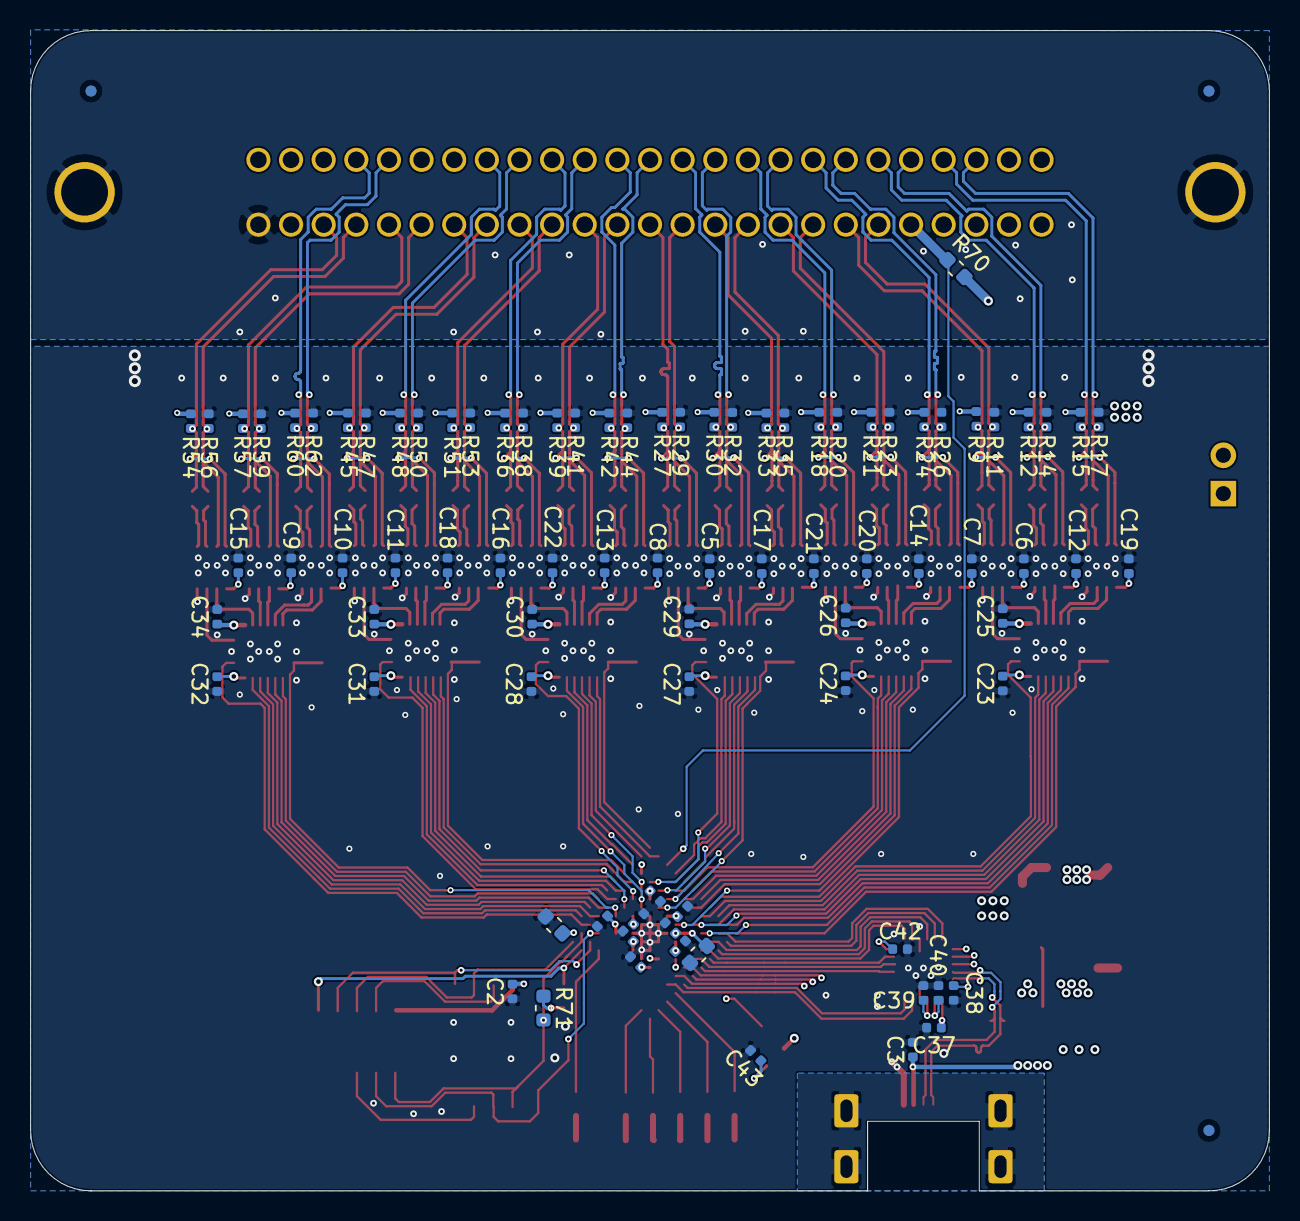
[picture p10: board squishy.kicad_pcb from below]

Board: 4 copper layers, 82.0 x 76.8 mm, 216 parts (89 on the bottom side), 196 nets.

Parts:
C1, C4: 0.1uF; C_0603_1608Metric
C2, C5, C6, C7, C8, C9, C10, C11, C12, C13, C14, C15, C16, C17, C18, C19, C20, C21, C22, C23, C24, C25, C26, C27, C28, C29, C30, C31, C32, C33, C34, C37, C38, C39, C40, C42, C46, C47, C48, C49, C50, C51, C52, C53: 0.1uF; C_0402_1005Metric
C3, C43: 0.01uF; C_0402_1005Metric
C35, C36: 47pf; C_0402_1005Metric
C41: 100uF; C_1210_3225Metric
C44, C45, C54, C55, C56, C57: 4.7uF; C_0603_1608Metric
D1, D9, D10: BLUE; LED_0603_1608Metric_Pad1.05x0.95mm_HandSolder
D2, D6: PINK; LED_0603_1608Metric_Pad1.05x0.95mm_HandSolder
D3, D4, D7, D8, D11, D12, D15, D16, D19, D20, D23, D24, D27, D28, D31, D32, D35, D36, D39, D40, D43, D44, D47, D48, D51, D52, D55, D56, D59, D60, D63, D64, D67, D68, D71, D72: D_Schottky_Small; D_0402_1005Metric
D5: WHITE; LED_0603_1608Metric_Pad1.05x0.95mm_HandSolder
F1: Polyfuse_Small; Fuse_1210_3225Metric_Castellated
FID1, FID2, FID3, FID4, FID5, FID6: Fiducial; Fiducial_0.75mm_Mask1.5mm
J1: USB_B_Micro; MICRO-USB-B-(IN_PCB)
J2: Conn_02x26_Top_Bottom; SCSI-50-PIN
J3: Conn_02x05_Odd_Even; FTSH-105-01-L-DV-K-TR
JP1: TERMPWR; PinHeader_1x02_P2.54mm_Vertical
R1, R2: 1M; R_0603_1608Metric
R3, R4, R5, R6, R7, R8, R64, R66, R68, R70, R71: 10k; R_0603_1608Metric
R9, R11, R12, R14, R15, R17, R18, R20, R21, R23, R24, R26, R27, R29, R30, R32, R33, R35, R36, R38, R39, R41, R42, R44, R45, R47, R48, R50, R51, R53, R54, R56, R57, R59, R60, R62: 330; R_0402_1005Metric
R10, R13, R16, R19, R22, R25, R28, R31, R34, R37, R40, R43, R46, R49, R52, R55, R58, R61: 150; R_0402_1005Metric
R63, R67, R69: 4k7; R_0603_1608Metric
R65: 6k8; R_0603_1608Metric
TP1: 1v2; TestPoint_Pad_D1.0mm
TP2: 5v0; TestPoint_Pad_D1.0mm
TP3: 3v3; TestPoint_Pad_D1.0mm
TP4: GND; TestPoint_Pad_D1.0mm
U1: 128MiB; WSON-8-1EP-6.0x8.0mm
U2: ICE40HX8K-BG121; BGA-121_9.0x9.0mm_Layout11x11_P0.8mm_Ball0.4mm_Pad0.35mm_NS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
U3, U4, U5, U6, U7, U8, U9, U10, U11, U12, U13, U14, U15, U16, U17, U18, U19, U20: THVD1451; VSON_8_3mm_x_3mm_1EP
U21, U22, U23, U24, U25, U26: TXB0106; R-PVQFN-N16
U27: FT240XQ; QFN-24-1EP_4x4mm_P0.5mm_EP2.6x2.6mm
U28: MAX809JTRG; SOT-23
U29: TLV755533PDRVR; DFN-6-1EP_2x2mm_P0.65mm_EP1x1.6mm
U30: TLV73312PQDRVRQ1; DFN-6-1EP_2x2mm_P0.65mm_EP1x1.6mm
X1: ASEM-48MHz; Oscillator_SMD_Abracon_ASE-4Pin_3.2x2.5mm

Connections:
+1V2: C45.2, C47.2, C49.2, C51.2, C53.2, C57.2, TP1.1, U2.D4, U2.D8, U2.H4, U2.H8, U30.1, U30.2
+3V3: C2.2, C23.2, C24.2, C27.2, C28.2, C31.2, C32.2, C38.1, C39.1, C40.1, C42.1, C43.1, C44.2, C46.2, C48.2, C50.2, C52.2, C56.2, J3.2, R68.2, R71.2, TP3.1, U1.8, U2.C10, U2.D6, U2.E4, U2.F8, U2.G4, U2.H6, U2.L11, U21.2, U22.2, U23.2, U24.2, U25.2, U26.2, U27.12, U27.14, U27.15, U27.24, U29.1, U29.2, X1.1, X1.4
+5V: C3.1, C5.2, C6.2, C7.2, C8.2, C9.2, C10.2, C11.2, C12.2, C13.2, C14.2, C15.2, C16.2, C17.2, C18.2, C19.2, C20.2, C21.2, C22.2, C25.1, C26.1, C29.1, C30.1, C33.1, C34.1, C41.1, C54.2, C55.2, J1.1, J1.4, JP1.1, TP2.1, U3.1, U4.1, U5.1, U6.1, U7.1, U8.1, U9.1, U10.1, U11.1, U12.1, U13.1, U14.1, U15.1, U16.1, U17.1, U18.1, U19.1, U20.1, U21.15, U22.15, U23.15, U24.15, U25.15, U26.15, U28.3, U29.5, U29.6, U30.4, U30.5, U30.6
/ACK+: D40.1, J2.35, R36.1, R37.2, U20.8
/ACK-: D39.1, J2.36, R37.1, R38.2, U20.7
/ACK_RX: U2.A6, U22.3
/ACK_TX: U2.B7, U22.1
/ATN+: D72.1, J2.29, R60.1, R61.2, U8.8
/ATN-: D71.1, J2.30, R61.1, R62.2, U8.7
/ATN_RX: U2.C4, U21.5
/ATN_TX: U2.B3, U21.4
/BNK0_OE: R3.1, U2.A1, U21.8
/BNK1_OE: R4.1, U2.A4, U22.8
/BNK2_OE: R5.1, U2.D7, U23.8
/BNK3_OE: R6.1, U2.A11, U24.8
/BNK4_OE: R7.1, U2.D11, U25.8
/BNK5_OE: R8.1, U2.G9, U26.8
/BSY+: D56.1, J2.33, R48.1, R49.2, U16.8
/BSY-: D55.1, J2.34, R49.1, R50.2, U16.7
/BSY_RX: U2.D5, U22.7
/BSY_TX: U2.B5, U22.6
/CD+: D24.1, J2.43, R24.1, R25.2, U5.8
/CD-: D23.1, J2.44, R25.1, R26.2, U5.7
/CD_RX: U2.E11, U25.5
/CD_TX: U2.E10, U25.4
/D0: U2.E1, U27.21
/D1: U2.D2, U27.1
/D2: U2.D1, U27.23
/D3: U2.B2, U27.6
/D4: U2.E2, U27.22
/D5: U2.C2, U27.4
/D6: U2.B1, U27.5
/D7: U2.C1, U27.2
/D+: C35.1, J1.3, U27.10
/D-: C36.1, J1.2, U27.11
/DB0+: D64.1, J2.3, R54.1, R55.2, U13.8
/DB0-: D63.1, J2.4, R55.1, R56.2, U13.7
/DB0_RX: U2.C3, U21.7
/DB0_TX: U2.A2, U21.6
/DB1+: D68.1, J2.5, R57.1, R58.2, U7.8
/DB1-: D67.1, J2.6, R58.1, R59.2, U7.7
/DB1_RX: U2.A3, U21.3
/DB1_TX: U2.B4, U21.1
/DB2+: D52.1, J2.7, R45.1, R46.2, U9.8
/DB2-: D51.1, J2.8, R46.1, R47.2, U9.7
/DB2_RX: U2.A5, U22.5
/DB2_TX: U2.B6, U22.4
/DB3+: D60.1, J2.9, R51.1, R52.2, U14.8
/DB3-: D59.1, J2.10, R52.1, R53.2, U14.7
/DB3_RX: U2.C7, U23.7
/DB3_TX: U2.A7, U23.6
/DB4+: D44.1, J2.11, R39.1, R40.2, U11.8
/DB4-: D43.1, J2.12, R40.1, R41.2, U11.7
/DB4_RX: U2.A8, U23.3
/DB4_TX: U2.C9, U23.1
/DB5+: D28.1, J2.13, R27.1, R28.2, U3.8
/DB5-: D27.1, J2.14, R28.1, R29.2, U3.7
/DB5_RX: U2.D9, U24.5
/DB5_TX: U2.C11, U24.4
/DB6+: D36.1, J2.15, R33.1, R34.2, U19.8
/DB6-: D35.1, J2.16, R34.1, R35.2, U19.7
/DB6_RX: U2.D10, U25.7
/DB6_TX: U2.F9, U25.6
/DB7+: D20.1, J2.17, R21.1, R22.2, U12.8
/DB7-: D19.1, J2.18, R22.1, R23.2, U12.7
/DB7_RX: U2.F11, U25.3
/DB7_TX: U2.F10, U25.1
/DBP+: D4.1, J2.19, R9.1, R10.2, U4.8
/DBP-: D3.1, J2.20, R10.1, R11.2, U4.7
/DBP_RX: U2.H11, U26.5
/DBP_TX: U2.H10, U26.4
/DIFF_SENSE: J2.21, R70.1, U2.A9
/FPGA_DONE: R69.1, U2.K8
/GLOBAL_CLK: U2.F3, X1.3
/IO+: D12.1, J2.47, R15.1, R16.2, U17.8
/IO-: D11.1, J2.48, R16.1, R17.2, U17.7
/IO_RX: U2.J11, U26.3
/IO_TX: U2.J10, U26.1
/MSG+: D32.1, J2.39, R30.1, R31.2, U15.8
/MSG-: D31.1, J2.40, R31.1, R32.2, U15.7
/MSG_RX: U2.A10, U24.7
/MSG_TX: U2.B11, U24.6
/REQ+: D8.1, J2.45, R12.1, R13.2, U10.8
/REQ-: D7.1, J2.46, R13.1, R14.2, U10.7
/REQ_RX: U2.G11, U26.7
/REQ_TX: U2.G10, U26.6
/RST+: D48.1, J2.37, R42.1, R43.2, U6.8
/RST-: D47.1, J2.38, R43.1, R44.2, U6.7
/RST_RX: U2.C8, U23.5
/RST_TX: U2.B8, U23.4
/S1: R63.1, U2.H1
/S2: R64.1, U2.J1
/S3: R65.1, U2.K1
/S4: R66.1, U2.L1
/S5: R67.1, U2.L2
/SEL+: D16.1, J2.41, R18.1, R19.2, U18.8
/SEL-: D15.1, J2.42, R19.1, R20.2, U18.7
/SEL_RX: U2.E8, U24.3
/SEL_TX: U2.E9, U24.1
/SHIELD: C4.1, J2.1, J2.51, J2.52, R2.1
/TERMPWR: F1.1, J2.25, J2.26, R9.2, R12.2, R15.2, R18.2, R21.2, R24.2, R27.2, R30.2, R33.2, R36.2, R39.2, R42.2, R45.2, R48.2, R51.2, R54.2, R57.2, R60.2, R70.2
/~FPGA_RESET: J3.10, R68.1, U2.L9
/~RD: U2.F1, U27.8
/~RXF: U2.G1, U27.18
/~SI_WU: U2.F2, U27.7
/~TXF: U2.H2, U27.17
/~WR: U2.G2, U27.9
GND: C1.1, C2.1, C3.2, C4.2, C5.1, C6.1, C7.1, C8.1, C9.1, C10.1, C11.1, C12.1, C13.1, C14.1, C15.1, C16.1, C17.1, C18.1, C19.1, C20.1, C21.1, C22.1, C23.1, C24.1, C25.2, C26.2, C27.1, C28.1, C29.2, C30.2, C31.1, C32.1, C33.2, C34.2, C35.2, C36.2, C37.2, C38.2, C39.2, C40.2, C41.2, C42.2, C43.2, C44.1, C45.1, C46.1, C47.1, C48.1, C49.1, C50.1, C51.1, C52.1, C53.1, C54.1, C55.1, C56.1, C57.1, D1.1, D2.1, D5.1, D6.1, D9.1, D10.1, J1.5, J2.2, J2.22, J2.23, J2.24, J2.27, J2.28, J2.31, J2.32, J2.49, J2.50, J3.7, R1.1, R2.2, R3.2, R4.2, R5.2, R6.2, R7.2, R8.2, R11.1, R14.1, R17.1, R20.1, R23.1, R26.1, R29.1, R32.1, R35.1, R38.1, R41.1, R44.1, R47.1, R50.1, R53.1, R56.1, R59.1, R62.1, TP4.1, U1.4, U1.9, U2.E5, U2.E6, U2.E7, U2.F5, U2.F6, U2.F7, U2.G5, U2.G6, U2.G7, U2.H5, U3.4, U3.9, U4.4, U4.9, U5.4, U5.9, U6.4, U6.9, U7.4, U7.9, U8.4, U8.9, U9.4, U9.9, U10.4, U10.9, U11.4, U11.9, U12.4, U12.9, U13.4, U13.9, U14.4, U14.9, U15.4, U15.9, U16.4, U16.9, U17.4, U17.9, U18.4, U18.9, U19.4, U19.9, U20.4, U20.9, U21.9, U21.17, U22.9, U22.17, U23.9, U23.17, U24.9, U24.17, U25.9, U25.17, U26.9, U26.17, U27.3, U27.16, U27.25, U28.1, U29.3, U29.7, U30.3, U30.7, X1.2
unnamed: C1.2, J1.6, R1.2
unnamed: C37.1, U27.13
unnamed: D1.2, R63.2
unnamed: D2.2, R64.2
unnamed: D3.2, U4.6
unnamed: D4.2, U4.5
unnamed: D5.2, R65.2
unnamed: D6.2, R66.2
unnamed: D7.2, U10.6
unnamed: D8.2, U10.5
unnamed: D9.2, R67.2
unnamed: D10.2, R69.2
unnamed: D11.2, U17.6
unnamed: D12.2, U17.5
unnamed: D15.2, U18.6
unnamed: D16.2, U18.5
unnamed: D19.2, U12.6
unnamed: D20.2, U12.5
unnamed: D23.2, U5.6
unnamed: D24.2, U5.5
unnamed: D27.2, U3.6
unnamed: D28.2, U3.5
unnamed: D31.2, U15.6
unnamed: D32.2, U15.5
unnamed: D35.2, U19.6
unnamed: D36.2, U19.5
unnamed: D39.2, U20.6
unnamed: D40.2, U20.5
unnamed: D43.2, U11.6
unnamed: D44.2, U11.5
unnamed: D47.2, U6.6
unnamed: D48.2, U6.5
unnamed: D51.2, U9.6
unnamed: D52.2, U9.5
unnamed: D55.2, U16.6
unnamed: D56.2, U16.5
unnamed: D59.2, U14.6
unnamed: D60.2, U14.5
unnamed: D63.2, U13.6
unnamed: D64.2, U13.5
unnamed: D67.2, U7.6
unnamed: D68.2, U7.5
unnamed: D71.2, U8.6
unnamed: D72.2, U8.5
unnamed: F1.2, JP1.2
unnamed: J3.1, R71.1, U1.1, U2.K10
unnamed: J3.3, U1.2, U2.J9
unnamed: J3.4, U1.7
unnamed: J3.5, U1.3
unnamed: J3.6, U1.6, U2.L10
unnamed: J3.8, U1.5, U2.K9
unnamed: U10.2, U21.12
unnamed: U10.3, U21.13
unnamed: U11.2, U24.12
unnamed: U11.3, U24.13
unnamed: U12.2, U22.12
unnamed: U12.3, U22.13
unnamed: U13.2, U26.14
unnamed: U13.3, U26.16
unnamed: U14.2, U25.10
unnamed: U14.3, U25.11
unnamed: U15.2, U23.12
unnamed: U15.3, U23.13
unnamed: U16.2, U25.12
unnamed: U16.3, U25.13
unnamed: U17.2, U21.10
unnamed: U17.3, U21.11
unnamed: U18.2, U22.14
unnamed: U18.3, U22.16
unnamed: U19.2, U23.10
unnamed: U19.3, U23.11
unnamed: U20.2, U24.14
unnamed: U20.3, U24.16
unnamed: U4.2, U21.14
unnamed: U4.3, U21.16
unnamed: U5.2, U22.10
unnamed: U5.3, U22.11
unnamed: U3.2, U23.14
unnamed: U3.3, U23.16
unnamed: U6.2, U24.10
unnamed: U6.3, U24.11
unnamed: U9.2, U25.14
unnamed: U9.3, U25.16
unnamed: U8.2, U26.10
unnamed: U8.3, U26.11
unnamed: U7.2, U26.12
unnamed: U7.3, U26.13
unnamed: U28.2, U29.4

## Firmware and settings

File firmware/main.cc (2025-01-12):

/* SPDX-License-Identifier: BSD-3-Clause */

#include <cstdint>

#include <exception>

#include "units.hh"
#include "platform.hh"
#include "peripherals.hh"
#include "pindefs.hh"
#include "fault.hh"
#include "fpga.hh"
#include "spi.hh"

std::atomic<std::uint8_t> extint{0U};

void setup_io() noexcept {
	/* Setup the global clock input */
	PORTA.setup_pin(pin::CLKIN, true, false, false, false, port_t::pin_func_t::H);
	PORTA.set_input(pin::CLKIN);

	/* Setup LEDs */
	PORTA.set_high(pin::SU_LED_G);
	PORTA.set_output(pin::SU_LED_G); /* status LED */
	PORTA.set_high(pin::SU_LED_R);
	PORTA.set_output(pin::SU_LED_R); /* error LED */

	/* Setup External DFU Trigger */
	PORTA.setup_pin(pin::DFU_BTN, true, false, false, false, port_t::pin_func_t::A);
	PORTA.set_input(pin::DFU_BTN);
	/* Setup FPGA Side attention lines */
	PORTA.set_low(pin::SU_ATTN);
	PORTA.setup_pin(pin::SU_ATTN, true, false, true, false, port_t::pin_func_t::A);
	PORTA.set_input(pin::SU_ATTN);

	/* SPI Bus hold line */
	PORTA.setup_pin(pin::BUS_HOLD, false, true, false, false, port_t::pin_func_t::A);
	PORTA.set_input(pin::BUS_HOLD);
}

void setup_clocking() noexcept {
	/* TODO(aki): Setup the PLL so we can boost our core clock to 48MHz */

	/* Set GCLK0 to use the external clock input on PA08 */
	GCLK.config_gen(gclk_t::clkgen_t::GCLK0, gclk_t::clksrc_t::GCLKIN, true);

	/* Enable SERCOM0 clocking */
	PM.unmask(pm_t::apbc_periph_t::SERCOM0);

	/* Set SERCOM0_CORE to GCLK0 */
	GCLK.config_clk(gclk_t::clkid_t::SERCOM0_CORE, gclk_t::clkgen_t::GCLK0, true, false);
	/* Set SERCOMx_SLOW to GCLK0 */
	GCLK.config_clk(gclk_t::clkid_t::SERCOMx_SLOW, gclk_t::clkgen_t::GCLK0, true, false);

	/* Enable the EIC */
	PM.unmask(pm_t::apba_periph_t::EIC);
	GCLK.config_clk(gclk_t::clkid_t::EIC, gclk_t::clkgen_t::GCLK0, true, false);
}

void setup_extint() noexcept {

	/* Configure the EXTINTS */

	/* SU_ATTN line */
	EIC.enable_extint_irq(1U);
	EIC.enable_extint(1U, false, eic_t::sense_t::RISE);

	/* DFU_TRIG line */
	EIC.enable_extint_irq(7U);
	EIC.enable_extint(7U, true, eic_t::sense_t::RISE); // When button is released

	/* Finally, enable the EIC */
	EIC.enable();

	/* Clear out anything that may have accidentally triggered */
	EIC.ack_extint(1U);
	EIC.ack_extint(7U);

	/* Tell the NVIC we actually want to have this work */
	NVIC.enable_irq(4);
	NVIC.set_priority(20, nvic_t::priority_t::MID);
}

void start() noexcept {
	/* Brown-out detect @ 1v7 ± 50mV */
	SYSCTRL.enable_bod33(7U);
	/* This will do until BOD is configured */
	if (PM.was_brownout()) {
		DSU.reset_core();
	}

	setup_io();
	setup_clocking();
	setup_extint();
	setup_fpga_ctrl_pins();

	/* Ensure SysTick keeps running when we call std::terminate() so we can blink a panic code  */
	NVIC.set_priority(15, nvic_t::priority_t::TOP);

	SYSTICK.reload_value = (32_MHz / 1_kHz) - 1U;
	SYSTICK.enable();

	/* If we can't initialize SPI, then we're SOL, so bail */
	if (!setup_spi()) {
		std::terminate();
	}

	/* Try to load the first applet */
	if (!load_bitstream_flash(squishy::slots::APPLET1)) {
		/* We *might* still be okay, clear the fault code and try to load the bootloader */
		active_fault = fault_code_t::NONE;
		if (!load_bitstream_flash(squishy::slots::BOOTLOADER)) {
			/* Well shit,,, */
			std::terminate();
		}
	}

	for(;;) {
		const auto interrupts{extint.exchange(0U)};

		if (interrupts != 0) {
			/* Someone pressed the DFU button (EXTINT1) */
			if (interrupts & (1U << 7U)) {
				fpga_enter_cfg();
				/* Load the bootloader bitstream */
				if (!load_bitstream_flash(squishy::slots::BOOTLOADER)) {
					std::terminate();
				}
			}

			/* FPGA wants our attention */
			if (interrupts & (1U << 1U)) {
				if(!fpga_handle_irq()) {
					/* Simply, explode, */
					std::terminate();
				}
			}
		}

		asm ("wfi"); // Wiggle for interrupt:tm:
	}
}

void irq_eic() noexcept {
	/* Get the triggered EXTINTs */
	const auto intnum{EIC.get_extint_irq()};

	/* Set which interrupts were triggered */
	extint = intnum;

	/* ACK triggered interrupts */
	for (std::size_t i{0U}; i < 8U; ++i) {
		const auto was_enabled{static_cast<bool>(std::uint32_t(intnum >> i) & 0b1U)};
		if (was_enabled) {
			EIC.ack_extint(static_cast<std::uint8_t>(i));
		}
	}
}

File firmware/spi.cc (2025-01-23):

/* SPDX-License-Identifier: BSD-3-Clause */

#include <cstdint>

#include "spi.hh"

#include "peripherals.hh"
#include "pindefs.hh"
#include "units.hh"
#include "timing.hh"
#include "flash.hh"
#include "fault.hh"
#include "fpga.hh"
#include "memory.hh"

enum struct flash_cmd_t : std::uint16_t {
	WRITE_ENABLE  = 0x0006U,
	WRITE_DISABLE = 0x0004U,
	READ_STATUS   = 0x0005U,
	READ          = 0x0003U | 0x0800U,
	PAGE_PROGRAM  = 0x0002U | 0x0800U,
	SECTOR_ERASE  = 0x0020U | 0x0800U,
	CHIP_ERASE    = 0x0060U,
	READ_ID       = 0x009FU,
	READ_SFDP     = 0x005AU | 0x0800U | 0x0100U,
};

enum struct fpga_cmd_t : std::uint8_t {
	NOP            = 0xFFU,
	READ_ID        = 0xE0U,
	READ_STATUS    = 0x3CU,
	CHECK_BUSY     = 0xF0U,
	ENABLE         = 0xC6U,
	ENABLE_TRANS   = 0x74U,
	DISABLE        = 0x26U,
	YEET_BITSTREAM = 0x7AU,
};

[[nodiscard]]
static std::uint8_t flash_xfr(const std::uint8_t data = 0x00U) noexcept;
static void flash_setup_xfr(const flash_cmd_t command, const std::uint32_t addr = 0x0000'0000U) noexcept;
static void flash_run_cmd(const flash_cmd_t command, const std::uint32_t addr = 0x0000'0000U) noexcept;

[[nodiscard]]
static std::uint8_t fpga_xfr(const std::uint8_t data = 0x00U) noexcept;
[[nodiscard]]
static bool fpga_program_status() noexcept;

static void fpga_cmd_read(const fpga_cmd_t command, std::span<std::uint8_t> data) noexcept;
static void fpga_cmd_write(const fpga_cmd_t command, const std::span<std::uint8_t>& data) noexcept;

[[nodiscard]]
static std::uint8_t gateware_xfr(const std::uint8_t data = 0x00U) noexcept;

static void psram_setup_xfr(const flash_cmd_t command, const std::uint32_t addr = 0x0000'0000U) noexcept;
static void psram_run_cmd(const flash_cmd_t command, const std::uint32_t addr = 0x0000'0000U) noexcept;

[[nodiscard]]
std::array<std::uint8_t, 3> read_flash_id() noexcept;
[[nodiscard]]
std::array<std::uint8_t, 8> read_psram_id() noexcept;
[[nodiscard]]
fpga_id_t read_fpga_id() noexcept;
static fpga_id_t active_fpga_id{};

static std::array<std::uint8_t, 1_KiB> spi_buffer{{}};

static void setup_fpga_pins() noexcept {

	/* Set up PSRAM Chip select is inverted */
	PORTA.set_low(pin::PSRAM_CS);
	PORTA.set_output(pin::PSRAM_CS);

	/* Set up FPGA SPI Bus */
	PORTA.set_high(pin::FPGA_CS);
	PORTA.set_output(pin::FPGA_CS);

	PORTA.set_low(pin::FPGA_CLK);
	PORTA.set_output(pin::FPGA_CLK);

	PORTA.set_low(pin::FPGA_COPI);
	PORTA.set_output(pin::FPGA_COPI);
	PORTA.setup_pin(pin::FPGA_CIPO, false, true, false, false, port_t::pin_func_t::A);
	PORTA.set_input(pin::FPGA_CIPO);
}

static void setup_flash_pins() noexcept {

	PORTA.setup_pin(pin::FLASH_CS, false, false, false, false, port_t::pin_func_t::C);
	PORTA.set_high(pin::FLASH_CS);
	PORTA.set_output(pin::FLASH_CS);

	PORTA.setup_pin(pin::FLASH_CLK, true,  false, false, false, port_t::pin_func_t::D);
	PORTA.set_output(pin::FLASH_CLK);

	PORTA.setup_pin(pin::FLASH_COPI, true,  false, false, false, port_t::pin_func_t::C);
	PORTA.set_output(pin::FLASH_COPI);

	PORTA.setup_pin(pin::FLASH_CIPO, true,  true,  false, false, port_t::pin_func_t::D);
	PORTA.set_input(pin::FLASH_CIPO);
}


static void setup_sercom() noexcept {
	/* Check if by some change the SERCOM is enabled, if so, disable it */
	if (SERCOM0_SPI.enabled()) {
		SERCOM0_SPI.disable();
	}

	setup_flash_pins();

	SERCOM0_SPI.configure(
		sercom_spi_t::mode_t::Controller,
		/* PAD0 = COPI; PAD1 = CLK; PAD2 = CS; PAD3 = CIPO */
		sercom_spi_t::dopo_t::CFG0, sercom_spi_t::dipo_t::PAD3,
		sercom_spi_t::form_t::SPI,
		sercom_spi_t::cpha_t::SAMPLE_TRAILING, sercom_spi_t::cpol_t::IDLE_LOW,
		sercom_spi_t::dord_t::MSB
	);

	/* Set the SERCOM baud */
	/* baud = (32MHz / (2 * 16MHz)) - 1 = 0 */
	SERCOM0_SPI.baud = 0U;

	SERCOM0_SPI.ctrlb = (0U << 0U) | (1U << 17U);

	while (SERCOM0_SPI.sync_busy_ctrlb()) {
		continue;
	}

	/* Enable the SERCOM */
	SERCOM0_SPI.enable();
}

bool test_psram() noexcept {
	for(std::size_t idx{}; idx < spi_buffer.size(); ++idx) {
		spi_buffer[idx] = idx & 0xFFU;
	}

	for(std::size_t offset{}; offset < 4_KiB; offset += spi_buffer.size()) {
		[[maybe_unused]]
		auto _{write_psram(offset, spi_buffer)};
	}

	[[maybe_unused]]
	auto _{read_psram(0x0000'0000U, spi_buffer)};

	for(std::size_t idx{}; idx < spi_buffer.size(); ++idx) {
		if (spi_buffer[idx] != (idx & 0xFFU))
			return false;
	}

	return true;
}

bool setup_spi() noexcept {
	setup_sercom();
	setup_fpga_pins();

	const auto flash_id{read_flash_id()};

	/* Ensure we get the expected ID from the flash */
	if (flash_id != decltype(flash_id){{0xC8U, 0x40U, 0x17U}}) {
		active_fault = fault_code_t::SPI_FLASH_BAD;
		return false;
	}


	const auto psram_id{read_psram_id()};
	const auto psram_size{std::uint8_t((psram_id[2] & 0xE0U) >> 5U)};
	if (psram_id[0] != 0x9D /* ISSI */ || psram_size != 2U /* 32Mb */) {
		active_fault = fault_code_t::SPI_PSRAM_BAD;
		return false;
	}

	// NOTE(aki): There is a hardware bug (squishy-scsi/hardware#17) that causes this test to run
	// forever until you gently boop the FPGA_CIPO line with your finger or oscliscope probe.
	// if (!test_psram()) {
	// 	active_fault = fault_code_t::SPI_PSRAM_BAD;
	// 	return false;
	// }


	fpga_enter_cfg();

	// Cache the ID of the FPGA that is attached to the board
	active_fpga_id = read_fpga_id();

	if (!((active_fpga_id == fpga_id_t::LEF5UM45) || (active_fpga_id == fpga_id_t::LEF5UM5G45))) {
		active_fault = fault_code_t::FPGA_ID_BAD;
		return false;
	}

	return true;
}

[[nodiscard]]
static std::uint8_t flash_xfr(const std::uint8_t data) noexcept {

	SERCOM0_SPI.data = data;

	while (!SERCOM0_SPI.receive_complete()) {
		continue;
	}

	return std::uint8_t(SERCOM0_SPI.data);
}

static void flash_setup_xfr(const flash_cmd_t command, const std::uint32_t addr) noexcept {
	PORTA.set_low(pin::FLASH_CS);

	const auto opcode{std::uint8_t(command)};

	[[maybe_unused]]
	auto _{flash_xfr(opcode)};

	if ((static_cast<std::uint16_t>(command) & 0x0800U) == 0x0800U) {
		_ = flash_xfr(std::uint8_t(addr >> 16U));
		_ = flash_xfr(std::uint8_t(addr >>  8U));
		_ = flash_xfr(std::uint8_t(addr >>  0U));
	}

	/* Wiggle out the intersticial bytes between addr and data phase */
	const std::size_t inter_len{(static_cast<std::uint16_t>(command) & 0x0700U) >> 8U};
	for (std::size_t ctr{}; ctr < inter_len; ++ctr) {
		_ = flash_xfr();
	}
}

/* Run a flash command */
static void flash_run_cmd(const flash_cmd_t command, const std::uint32_t addr) noexcept {
	flash_setup_xfr(command, addr);
	PORTA.set_high(pin::FLASH_CS);
}

[[nodiscard]]
std::array<std::uint8_t, 3> read_flash_id() noexcept {
	std::array<std::uint8_t, 3> id;

	flash_setup_xfr(flash_cmd_t::READ_ID);

	for (auto& byte : id) {
		byte = flash_xfr();
	}

	PORTA.set_high(pin::FLASH_CS);

	return id;
}

void read_flash(const std::uint32_t addr, std::span<std::uint8_t> buffer) noexcept {
	flash_setup_xfr(flash_cmd_t::READ, addr);

	for (auto& data : buffer) {
		data = flash_xfr();
	}

	PORTA.set_high(pin::FLASH_CS);
}
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

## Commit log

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2020-07-25 Routed the rest of the buses for the level shifters, added the bypass caps, and a whole bunch of other stuff
    [squishy.kicad_pcb, squishy.sch]
2020-07-25 Completed the routing and power, the last two things to do are sort the SCSI TERMPOWER and DIFFSENSE, and then the FPGA reset.
    [squishy.kicad_pcb, squishy.sch]
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2020-08-02 Fixed some part attributes
    [squishy.sch]
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2021-06-16 gateware/docs: removed the empty TODO file and also re-organized the gateware a bit
    [squishy.kicad_sch]
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2021-07-04 Fixed the SCSI connector shield ground points for bolts
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2021-07-21 gateware: broke out the uart into it's own sub elaboratable
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2021-07-21 gateware: uart: fixed the divisor calculation using the new PLL'd clock value
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2021-08-01 gateware: fixed up the `__all__` exports
    [spi.py]
2021-08-04 gateware: updated the UART simulation bench and replaced the dummy platform with a global simulation SimPlatform for use in the other simulation benches
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2021-08-25 gateware: sim: fixed the sim clocks so we're now running at 100MHz and not 48GHz,,,,
    [spi.py]
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2021-09-26 hardware: fixed a blip in the scsi wiggles, added ESD protection to the USB line because i got bullied into doing so
    [squishy.kicad_sch]
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2021-09-26 hardware: ensured we got a clean bill of health from DRC and ERC
    [squishy-power.kicad_sch, squishy-transceiver.kicad_sch, squishy.kicad_sch]
2021-09-26 hardware: fixed up some datasheets for symbols and added mounting holes
    [squishy-mechanical.kicad_sch, squishy-power.kicad_sch, squishy-transceiver.kicad_sch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]
2021-09-26 hardware: found an error with how the SCSI connector was laid out, fixed that, oh no, my poor pcb
    [squishy.kicad_sch]
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2021-09-26 hardware: added reset gen for power sequencing
    [squishy-power.kicad_sch, squishy.kicad_sch]
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2021-09-26 hardware: went-through the schematic checklist and ensured it was correct and complete, hence the previous few commits
2021-09-26 hardware: fipped the reset button pins around to make more sense and placed the reset button
    [squishy-power.kicad_sch]
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2021-09-26 hardware: supposedly fixed the pin ordering for all the scsi stuff, i hope
    [squishy-transceiver.kicad_sch, squishy.kicad_sch]
2021-09-26 hardware: termination resistors kicked my ass, but most of the nets are correct now
    [squishy-transceiver.kicad_sch]
2021-09-26 hardware: fixed up the bsy/ack as they were mixed up, still need to fix the enable signals
    [squishy-transceiver.kicad_sch]
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2021-09-27 hardware: fixed up the gnd plane below the fpga
    [squishy.kicad_sch]
2021-09-27 hardware: fixed the wson footprint for the chonky flash
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2021-09-27 hardware: added termpower indicator and pullup so we don't accidentally enable termpower on boot
    [squishy.kicad_sch]
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2021-09-27 hardware: added the "official" rev1 hardware output used to fab the boards
    [squishy-B_Cu.gbl, squishy-B_Mask.gbs, squishy-B_Paste.gbp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]
2021-09-27 hardware: rev1 fixed an oopsie with the colours and the exported schematic
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2021-09-29 hardware: rev1: created an initial design for a case for the project
    [squishy-clamshell.FCStd]
2021-09-30 hardware: rev1: added some spots for rubber feet and cleaned up some edges
    [squishy-clamshell.FCStd]
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2021-10-02 hardware: moved the squishy files into a subdir in the boards directory
    [squishy-mechanical.kicad_sch, squishy-power.kicad_sch, squishy-transceiver.kicad_sch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]
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2021-10-03 hardware: lots of work on the initial layout of rev2, not gonnya but too much effort in now though until we find all the problems with rev1
    [squishy-mechanical.kicad_sch, squishy-power.kicad_sch, squishy.kicad_sch]
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2021-10-04 hardware: some more work on rev2 getting the psu and the like sorted
    [squishy-power.kicad_sch, squishy.kicad_pcb, squishy.kicad_sch]
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2021-10-10 software: removed the configurability for the vid and pid and stuck them as constants into the platform
2021-10-12 hardware: fixed the part number for the FPGA
    [squishy-power.kicad_sch, squishy.kicad_sch]
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2021-10-18 hardware: got most of everything but the scsi phy done, that still needs to be designed
    [squishy-power.kicad_sch, squishy-termpwr.kicad_sch, squishy.kicad_pcb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]
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2021-10-18 hardware: did a lot of routing, added a syzygy connector for daughter cards
    [squishy-termpwr.kicad_sch, squishy.kicad_sch]
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2021-10-22 hardware: in the process of swapping out the hard-mount scsi connector for a mezzanine connector to allow for swapping out of connectors
    [squishy-transceiver.kicad_sch, squishy.kicad_sch]
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2021-11-01 hardware: some cleanup of the schematics, also added a dedicated uart port for the FPGA, and test points for SWD
    [squishy-transceiver.kicad_sch, squishy.kicad_sch]
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2021-11-01 hardware: did a whole lot of work on changing the form factor of the board as well as finally assigning the signals and some initial routing.
    [squishy-mechanical.kicad_sch, squishy-termpwr.kicad_sch, squishy.kicad_sch]
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2021-12-05 hardware: updated KiCad to v6 and replaced the silly USB-C connector with something more sane for USB 2
    [squishy-mechanical.kicad_sch, squishy-power.kicad_sch, squishy-termpwr.kicad_sch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]
2021-12-11 fixed up names and paths from `nmigen` to `amaranth`
    [spi.py]
2021-12-14 hardware/rev1/case: updated the case to include the termpower hole and cleaned up the screw and threading definitions
    [squishy-clamshell.FCStd]
2021-12-19 hardware: scsi-tap: 50: Updated the 50-pin scsi tap, still needs some work
    [scsi-50-tap.kicad_pcb, scsi-50-tap.kicad_sch]
2021-12-21 hardware: some updates to the connector being used for rev2 and it's modular bits
    [squishy-phy.kicad_sch, squishy-power.kicad_sch, squishy.kicad_sch]
2021-12-21 hardware: cleaned up the schematics a bit and made them more unified
    [squishy-mechanical.kicad_sch, squishy-phy.kicad_sch, squishy-power.kicad_sch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]
2021-12-21 hardware: fixed up the hardware a bit and resized the board
2021-12-21 hardware: fixed the large connector symbol pinout
    [squishy.kicad_sch]
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2022-01-11 hardware: rev1: case: Updated the case to improve the lid screw posts
    [squishy-clamshell.FCStd]
2022-01-13 hardware: updated hardware plans, moving from the LEF5U-*F-8BG256C to the LEF5UM5G-*F-8BG381C to allow for USB 3.1 gen 1
    [squishy.kicad_sch]
2022-01-13 hardware: started gutting the old FPGA in preparation to migrate to the new FPGA
    [squishy-phy.kicad_sch, squishy-power.kicad_sch, squishy-termpwr.kicad_sch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]
2022-01-14 hardware: started the absolutely colossal rework/refactor that is switching FPGAs and moving from USB2 to USB 3.2 Gen 1x1
    [squishy-mechanical.kicad_sch, squishy-phy.kicad_sch, squishy-power.kicad_sch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]
2022-01-14 hardware: sorted out some of the FPGA banks so they're in their proper home
    [squishy-power.kicad_sch, squishy-usbfe.kicad_sch, squishy.kicad_sch]
2022-01-16 hardware: large amount of refactoring and schematic tetris, slowly getting everything hooked back up, also merrged all the DFU/Debug signals onto a single connector
    [squishy-mechanical.kicad_sch, squishy-power.kicad_sch, squishy-usbfe.kicad_sch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]
2022-01-16 hardware: some more refactoring, prior to a full PCB rip-up and re-layout
    [squishy-power.kicad_sch, squishy.kicad_sch]
2022-01-19 hardware: added back the 1v8 regulated as we need the ULPI PHY again for USB2 compatibility, also updated the sheet metadata
    [squishy-mechanical.kicad_sch, squishy-phy.kicad_sch, squishy-power.kicad_sch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]
2022-01-22 gateware: platform: rev2: fixed up the attributes and removed the syzygy connector resource
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2022-01-24 hardware: squishy: got most of the USB FE done, it's a bit of a squiggly mess but should work:tm:
    [squishy-usbfe.kicad_sch, squishy.kicad_pcb]
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2022-02-14 hardware: squishy: picking back up on things, don't recall what was updated last
    [squishy-usbfe.kicad_sch, squishy.kicad_pcb, squishy.kicad_sch]
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2022-02-14 hardware: squishy: cleaned up some testpoints and made sure things that should not be in the BOM are not
    [squishy-power.kicad_sch, squishy.kicad_pcb, squishy.kicad_sch]
2022-02-14 hardware: squishy: cleaned up floating traces and grouped the LEDs and USB-FE, also moved the LEDs to their new home
    [squishy.kicad_pcb]
2022-02-14 hardware: squishy: some more cleanup, as well as starting work on the PSU side of things finally
    [squishy-power.kicad_sch, squishy-usbfe.kicad_sch, squishy.kicad_pcb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]
2022-02-16 hardware: squishy: replaced the SPI flash with a less batshit device from GigaDevice
    [squishy-power.kicad_sch, squishy-usbfe.kicad_sch, squishy.kicad_pcb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]
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2022-02-17 hardware: squishy: some misc additions, mainly a pull-up resistor for the sd card detect and the SPI CS for the FPGA
    [squishy.kicad_pcb, squishy.kicad_sch]
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2022-02-17 hardware: squishy: usb fe: fixing up and getting the last little bits of the USB front end done and dusted, just needs power routing now
    [squishy-usbfe.kicad_sch, squishy.kicad_pcb]
2022-02-20 hardware: fixed the USB PD controller pinout, as well as the AT SAMD symbol
    [squishy-usbfe.kicad_sch, squishy.kicad_pcb, squishy.kicad_sch]
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2022-02-20 hardware: squishy: some minor ERC fixes
    [squishy-usbfe.kicad_sch, squishy.kicad_sch]
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2022-04-14 software: made sure that when you hit `^C` it doesn't dump an ugly trace at you
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2022-04-15 software: swapped out pyusb to libusb1 and added a rough device wrapper
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2022-04-15 software: fixed up the device collection code to handle duplicate serial numbers, as well as print connected devices if no sn is supplied
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2022-04-21 ci: replaced pytest with pythons built-in test framework
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2022-04-21 software: gateware: forgot to replace the UARTPhy with UARTInterface during the last refactor
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2022-05-04 software: gateware: core: fixed the spi chip-select signal
    [spi.py]
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2022-09-11 squishy: core: fixed the `FlashGeometry` `init_slots` to return the instance of itself
    [flash.py]
2022-09-11 squishy: gateware: core: fixed some spelling mistakes in the `SPIFlash` elaboratable
    [flash.py]
2022-09-11 squishy: gateware: minor fixup of the import order and the SPI resource in the main applet elaboratable wrapper
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2022-09-11 squishy: gateware: core: fixed the SPI elaboratable test
    [spi.py]
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2022-09-15 squishy: some more refactoring to fix the type annotations to work on python 3.8
    [flash.py]
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2022-09-26 squishy: core: fixed an egregious oversight that caused the DFU upload functionality of the device to overwrite the bootloader, oops.
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2023-01-13 squishy: applets: analyzer: fixed a typo that would brake the pcapng timestamp generation
2023-01-14 squishy: action: fixed up the provision action to handle whole device image generation better
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2023-02-14 squishy: actions: Enabled debug verilog for applets and for provision behind a switch, and also set the provision action to always skip the cache
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2023-03-15 noxfile: updated noxfile to make the typing a bit more backwards compatible and also fixed up the `publish` session, which is now called `upload` and explicitly only uploads the non-dev wheel and src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
2023-03-15 tests: removed python 3.9 because the DFU sim currently breaks pysim and there is no fix atm
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2023-04-30 hardware: Updated the LEDs to make room for light pipes, swapped the USB-SS TX and RX polarities, added a 100MHz REFCLK for USB3 and also replaced the part for the 48MHz sysclock
    [squishy-usbfe.kicad_sch, squishy.kicad_pcb, squishy.kicad_sch]
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2024-03-16 squishy: core: cache: Added caching for the raw generated RTLIL not just the debug verilog in case something deeper needs to be debugged and the Yosys RTLIL to Verilog step causes problems
2024-03-16 squishy: core: device: Fixed a bug with DFU where the lambda was attempting to do parameter expansion which it cant so, and also added an note to check udev rules if we get a libusb error
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2024-06-14 squishy: gateware: platform: rev2: Fixed the LED errata in the hardware files,
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2024-10-19 firmware: fixed the FPGA/PSRAM SPI pinout due to some silly hardware errata
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2024-10-19 firmware: spi: Fixed the FPGA pin setup
    [spi.cc]
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2024-10-19 firmware: startup: fixed the NVIC table, we were missing two reserved entries causing the SysTick handler to be in the wrong spot, i'm surprised anything worked
    [startup.cc]
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2024-10-19 firmware: fixed a typo
    [spi.cc]
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2024-10-20 firmware: spi: Fixed up the pin modes for FPGA_DONE and FPGA_INIT
    [spi.cc]
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2024-10-20 firmware: startup: Fixed the disaster that calling `std::terminate()` would have caused due to calling a naked function
    [startup.cc]
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2024-10-21 firmware: spi: removed the LED toggles in the failure cases for the flash and FPGA id failure, relying on just the new fault system
    [spi.cc]
2024-10-21 firmware: main: set the priority of the SysTick interrupt to keep running despite other interrupts to ensure when we hit the fault handler we can still blink out an error code
    [main.cc]
2024-10-21 firmware: spi: replaced `read_jedec_id` with `read_flash_id` as we don't do a full JEDEC compliant ID read, only enough for our onboard flash
    [spi.cc]
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2024-10-23 firmware: Added rough POR detection due to a hardware issue(?) means we brown-out rather than lose all power causing the peripherals to stay configured causing a lockup state on power on from reset
    [main.cc]
2024-10-25 firmware: main: Set up brownout detection and we are only now resetting the core if we browned out
    [main.cc]
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2024-11-18 squishy: gateware: peripherals: Updated SPI Flash peripheral.
    Updated the SPI Flash controller peripheral to use the new SPIController interface, meaning we no longer pass the resource down, we now manually extract the needed subsignals to construct the controller, otherwise the interface remains unchanged.
    NOTE: There is some weirdness with the tests that was fixed by reaching into the SPI controller for it's Bus signals rather than using the global record signals, this reeks of unsoundness, and needs further investigation as to determine the cause
    [flash.py]
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2024-11-28 squishy: gateware: peripherals: spi: Fixed the clock glitch that occurs when in CPOL.LOW
    [spi.py]
2024-11-28 tests: gateware: peripherals: fixed the SPI tests
2024-11-29 gateware: peripherals: spi: Fixed the SPIPeripheral and also filled out the tests
    [spi.py]
2024-12-01 test: peripherals: psram: Completed the PSRAM read tests, ensuring that we stall properly if the read FIFO fills up as well.
2024-12-03 gateware: bootloader: Removed the unneeded extra addition of the `StallOnlyRequestHandler` as that is built by SOL on-the-fly from handler conditions.
    This also resolved the issue where the bootloader module when provided with the same synth options would fail cache lookup, because the SOL request handler name disambiguation would kick in, this might be able to be improved in upstream SOL by using a more deterministic method to calculate the disambiguation ID
2024-12-13 actions: Graceful handling of when gateware synth fails, rather than exploding with a stack trace
2024-12-14 gateware: peripherals: spi: Fixed an potential edge case where CS may drop if we are in the middle of our state machine, causing a de-sync
    [spi.py]
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2024-12-24 gateware: bootloader: rev2: fix the slot change timing so we actually latch the slot, and not just 0
2024-12-25 gateware: peripherals: psram: Fixed a bug where if the write FIFO had data we jumped the gun out of addressing
    [psram.py]
2024-12-26 actions: synth: Added a `--lie` option to pack the FPGA bitstream as a non-5G device, allowing for over-clocked non-5G FPGAs to be used,
    However, this won't allow them to use USB3, only USB the High-speed via the ULPI PHY
2024-12-26 core: flash: Fixed up the Squishy rev2 flash image bits in preparation for artifact packing
    [flash.py]
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2024-12-28 gateware: bootloader: rev2: changed the dl_ready synchronizer from PulseSynchronizer to a FFSynchronizer to fix a case where the DFU state machine would miss the short pulse from the PSRAM controller
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2025-01-05 gateware: bootloader: rev2: Switched the slot change signal's CDC to a pulse synchroniser to fix some FSM behaviour
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2025-01-08 firmware: Hooked up the EIC machinery and ensured the correct pin modes were set
    [main.cc, startup.cc]
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2025-01-10 firmware: spi: fixed the FPGA ID check to allow for both the 5G and non-5G variants
    [spi.cc]
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2025-01-12 gateware: peripherals: spi: Fixed and oopsie that causes us to hold the shared SPI bus hostage, even when we're a peripheral
    [spi.py]
2025-01-12 firmware: main: enabled the pulldown on the `SU_ATTN` line to prevent spurious triggers
    [main.cc]
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2025-01-12 firmware: main: Fixed the interrupt numbers in the `EIC` interrupt number check
    [main.cc]
2025-01-12 firmware: fpga: added a check to make sure the result we get back from `read_squishy_register` when getting the IRQ is not `0xFF` if it is, something is wrong
    [fpga.cc]
2025-01-12 gateware: bootloader: rev2: Fixed a case where the DFU machinery would ask for a reboot but the controller would just be stuck in IDLE
2025-01-12 firmware: fpga: added some glitch filtering to the SU_ATTN line
    [fpga.cc]
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2025-01-12 gateware: platform: rev2: Fixed a bug where despite everything CIPO and COPI are backwards on the supervisor SPI interface???
2025-01-12 gateware: peripherals: spi: replaced janky clock delay with more descriptive `Rose` and `Fell` Torii operators
    [spi.py]
2025-01-13 gateware: peripherals: spi: Fixed a bug where CIPO was set up a bit too late in the SPI Peripheral
    [spi.py]
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2025-01-15 tests: gateware: bootloader: Fixed the rev2 bootloader test after we adjusted the SPI timing in the supervisor interface
2025-01-15 gateware: bootloader: rev2: Added a delay slot for re-timing the `SLOT_CHANGED` signal so we hopefully latch it correctly
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
